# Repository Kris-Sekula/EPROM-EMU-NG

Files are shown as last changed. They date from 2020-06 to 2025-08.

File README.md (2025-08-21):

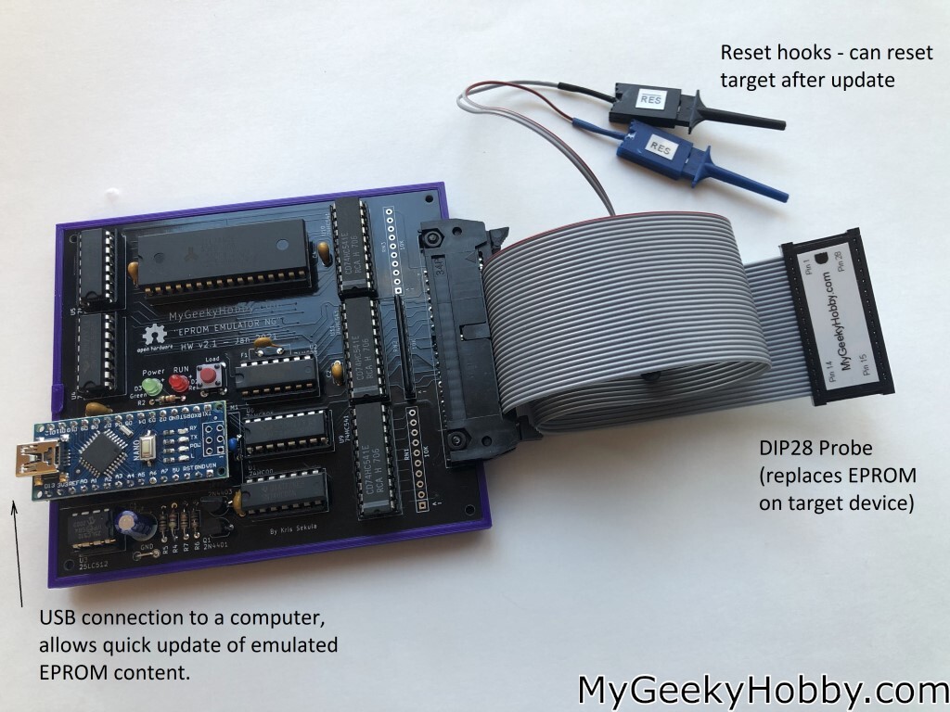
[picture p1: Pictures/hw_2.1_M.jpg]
EPROM EMULATOR NG

# EPROM-EMU-NG
EPROM Emulator Project with Arduino Nano, read more on [https://MyGeekyHobby.com](https://mygeekyhobby.com/2020/07/05/eprom-emulator/)

I have assembled devices and kits listed on [eBay](https://www.ebay.com/usr/avr4sale)

As people start building those, I encourage everyone to help creating updated firmware, software and collaborate here, report Issues if needed or contact me directly.

I get my PCBs from:

PCBWay (https://www.pcbway.com/project/shareproject/EPROM_Emulator_based_on_Arduino_.html)

If you found this helpful and you like the work I do, why not buy me a coffe, thanks ! :)



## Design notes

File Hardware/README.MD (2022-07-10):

###### Jul-9-2022

As of hardware version 1.9d and 2.2d support for a cheaper 28 pin probe has been added to the PCB, so depending on the type of probe you end up using, connector J1 has to be soldered in accordingly, see the picture below:

EPROM EMULATOR NG

###### Feb-6-2022

At this point there are two differnt hardware version of the emulator, one using 2x 32kb SRAMs and the other using a single 128kb SRAM (64k usable). Firmware and software is exaclty the same for both.

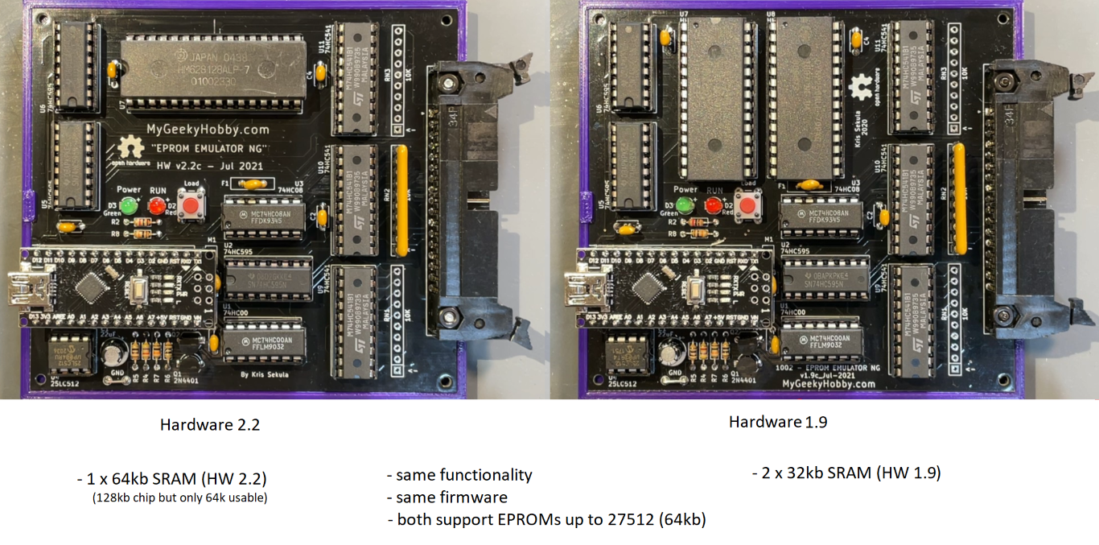
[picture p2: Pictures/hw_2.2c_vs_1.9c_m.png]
EPROM EMULATOR NG


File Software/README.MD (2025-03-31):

## Software (Python script) to control the EPROM emulator

### Currently recommended firmware and software:
* Firmware 2.0rc4 (EPROM_EMU_NG_FW_2.0rc4.ino - Arduino sketch in [Firmware](https://github.com/Kris-Sekula/EPROM-EMU-NG/tree/master/Firmware) folder)
* Software 2.0rc4 (EPROM_NG_v2.0rc4.py - Python script)

### If you want to try new features (increased speed of transfer, support for EEPROM), use the following:
* Firmware 2.0rc12 (EPROM_EMU_NG_FW_2.0rc12.ino - Arduino sketch in [Firmware](https://github.com/Kris-Sekula/EPROM-EMU-NG/tree/master/Firmware) folder)
* Software 2.0rc10 (EPROM_EMU_NG_2.0rc10.py - Python script)

## To successfully use the EPROM Emulator, you must do the following:
1. Install drivers
2. Install Python
3. Install required Python libraries
4. Run the script in command line mode (CLI) or in graphical interface mode (GUI)

### 1. Install Drivers
If you're using a genuine Arduino Nano module, install the Arduino IDE (this will install the drivers for all modules).
Most people use the much cheaper "clones", those in most cases, use the CH340 chip.
When plugged to a computer, they are supposed to "show up" as a "serial port device", but in many cases, driver installation is required. 

Sparkfun created a dedicated page that will guide you through the installation of CH340 drivers:

https://learn.sparkfun.com/tutorials/how-to-install-ch340-drivers/all

### 2. Install Python
The base way to install Python is to download the installation file from https://www.python.org/downloads/

> [!TIP]
> The installer has an option called "Add python to PATH", make sure you select it, this makes executing scripts much easier.

### 3. Install required libraries
There are two essential libraries that you must install:

* **pyserial** - to enable serial communication in Python
* **FreeSimpleGUI** - to allow a Python script to display a graphical user interface (GUI)

In Python, we install the libraries by calling a "package manager" called PIP. In your command prompt, you need to run:

```python -m pip install pyserial```

and 

```python -m pip install FreeSimpleGUI```

### 4.1 Run the script - CLI mode
You can run the script in a command-line mode by supplying the required parameters. Here is an example of the minimum required parameters to run the script:

```python.exe EPROM_NG_v2.0rc4.py -mem 27512 blink.bin COM13```

Parameters are explained:

"-mem 27512" -> Type of emulated memory

"blink.bin" -> file getting transferred (we support binary and intel hex files)

"COM13" -> serial port the emulator is plugged into

Here is a full output of the "upload session":
```
C:\PyDev>python.exe EPROM_NG_v2.0rc4.py -mem 27512 blink.bin COM13

Running EPROM EMU NG python script version 2.0rc4

File used: blink.bin

Done processing bin

Memory map disabled

Using serial port COM13, emulating: 27512 EPROM

-- attempting to get sync --

-> HW: v2.2h @ 115200, FW: 2.0rc4, SPI: 0, Auto: 0, Last EPROM: 27512, mygeekyhobby.com 2020 :)

-- processing file --

0x7E00 ->in

Time taken to transfer: 4.79s

-- Setting EPROM Type --
ACK

-- Finished --
-> Bus set to 27512 EPROM Memory
```

## 4.2 Run the script - GUI mode
If you want to start the script in graphical mode, **simply start it without any parameters**:

```python.exe EPROM_NG_v2.0rc4.py```

The script will open a "window":

![GUIMODE](https://github.com/Kris-Sekula/EPROM-EMU-NG/blob/master/Pictures/running_GUI_mode.JPG)

> [!NOTE]
> Depending on how Python is installed on your system, you may be able to simply "double-click" on the script to start it in GUI mode.

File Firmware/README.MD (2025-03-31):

## Firmware for Arduino Nano

### Currently recommended firmware and software:
* Firmware 2.0rc4 (EPROM_EMU_NG_FW_2.0rc4.ino)
* Software 2.0rc3 (EPROM_NG_v2.0rc4.py in [Software](https://github.com/Kris-Sekula/EPROM-EMU-NG/tree/master/Software) folder)

### If you want to try new features (increased speed of transfer, support for EEPROM) use the following:
* Firmware 2.0rc12 (EPROM_EMU_NG_FW_2.0rc12.ino - Arduino sketch)
* Software 2.0rc9 (EPROM_EMU_NG_2.0rc10.py - Python script in [Software](https://github.com/Kris-Sekula/EPROM-EMU-NG/tree/master/Software) folder)

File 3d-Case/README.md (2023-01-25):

The original files are for a "plastic base" rather than a proper case, but recently Todd Decker shared his design for a real case, check it out at [printables.com](https://www.printables.com/model/379508-eprom-emulator-case). He also shared his design via his [GitHub](https://github.com/ptdecker/openscad/tree/master/ROM%20Emulator) page.

Calling it a "case" is a bit of overstatement, it's simply a plastic "base plate" that you can install your emulator into. Adding some rubber feet to it (I use 3M sticky ones) will keep both your emulator and your table "protected". I printed mine with PLA.

There is a Probe_label file in Brother ptouch format and png format, so you print it and attach to the DIP 28 emulator probe.

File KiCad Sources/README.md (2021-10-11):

KiCad project files.

Version 2.2: Reshuffled component designations for pcb v1.9c and 2.2c to keep them in sync - help to keep the BoM alligned... only delta is the SRAM

Version 2.1: Moved from using 2x 32k SRAM to single 128k SRAM (64k usable). Firware and software is the same for both.

Version 1.9: Added pull-up resistors to /WE and EN_RST, helps prevent SRAM corruption during Arduino reset (needed only when doing partial uploads)

Version 1.8b: Fixed the footprint for Q1-2N4401 and Q2-2N4403, see Errata document for more details.

Version 1.8: I re-shuffled resistor networks, added RN3 to offer optional pull-up resistors for address line A0-A7, RN2 should be populated, RN1 and RN3 are optional. Added Q3 for my experiments, but there is no need to populate that transistor.

Version 1.7: Minor fix for a desing flaw as described in the ERRATA document. I also enlarged the holes for J1 as depeding on vendor of the connector in some cases the fit was very tight.

Version 1.6: Added some component description on silkscreen, no changes to tracks routing.

Version 1.4: I re-routed the power and improved the PCB design.

Version 1.0: After I built the first 5 prototypes, I discovered an issue with the PCB layout, one of the shift registers (U11) was getting onto a CMOS latch-up state, even though I had a few bypass caps around the PCB, I was still occasionally getting the issues. I fixed the prototypes by "bodging" a few connections at the bottom of the pcb.

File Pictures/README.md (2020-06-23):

A few pictures of the device, plus some "in action".

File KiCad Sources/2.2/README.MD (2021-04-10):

Version 2.2: no major changes, cleaned up the schematic a bit, re-shuffled the part designators so that ICs that are close to each other have consecutive numbers etc.

Firmware and software stays the same.

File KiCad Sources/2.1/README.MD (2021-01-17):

Changed from using 2x32 SRAM to single 128k SRAM (only 64k used). 

Firmware and software is the same for both desings, but the single SRAM has few pins less to solder :)

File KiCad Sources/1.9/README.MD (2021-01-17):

In this version of the design, I'm adding pull-up resistors to the /WE and the EN_RST lines. 
It helps to handle the state of the emulator when Arduino resets, this prevents the memory content corruption when we re-connect to the Arduino,
remember Arduino Nano has the feature where it resets as soon as you open the serial port. 
All of this is useful for the new software that I'm working on - it allows you to cache the data and only upload new/changed sectors.

Consider this PCB version verified as I already had boards made by PCBWay and they work fine.

This is the last version for the design with 2x 32k SRAMs ... I'm now moving to a new design that is using a single SRAM chip (see the 2.1 folder).

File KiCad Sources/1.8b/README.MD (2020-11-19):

1.8b is exactly as 1.8 but uses different footprint for Q1 and Q2 (see the Errata document for details)

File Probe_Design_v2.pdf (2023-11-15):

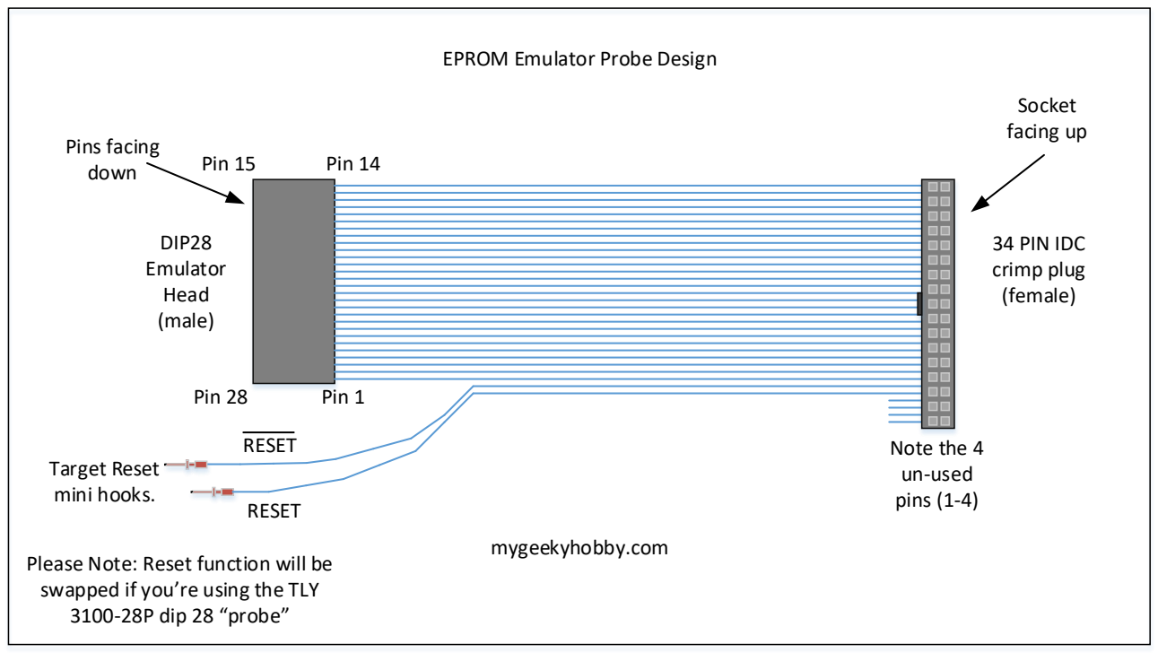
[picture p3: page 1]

34 PIN IDC
crimp plug
(female)

DIP28
Emulator
Head
(male)

Note the 4
un-used
pins (1-4)

Pin 14

Pin 28

Pin 15

Pin 1

mygeekyhobby.com

EPROM Emulator Probe Design

Pins facing
down

Socket
facing up

RESET

RESET
Target Reset
mini hooks.

Please Note: Reset function will be swapped if you’re using the TLY 3100-28P dip 28 “probe”

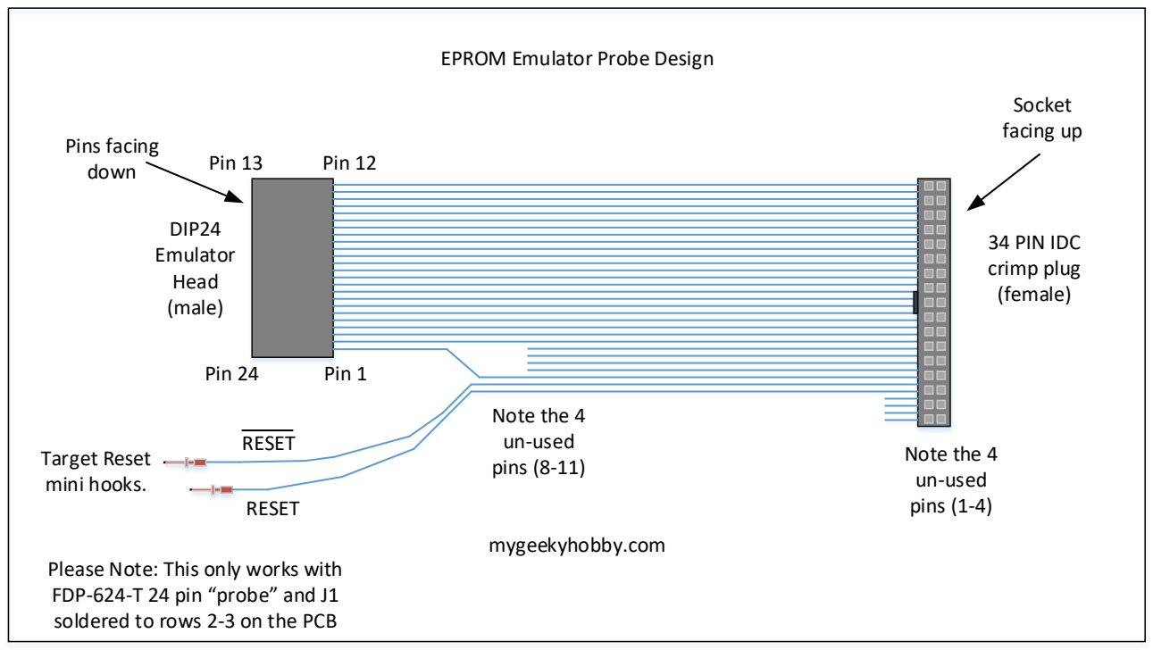
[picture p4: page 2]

34 PIN IDC
crimp plug
(female)

DIP24
Emulator
Head
(male)

Target Reset
mini hooks.

Note the 4
un-used
pins (1-4)

Pin 12

Pin 24

Pin 13

Pin 1

mygeekyhobby.com

EPROM Emulator Probe Design

Pins facing
down

Socket
facing up

Note the 4
un-used
pins (8-11)

RESET

RESET

Please Note: This only works with FDP-624-T 24 pin “probe” and J1 soldered to rows 2-3 on the PCB

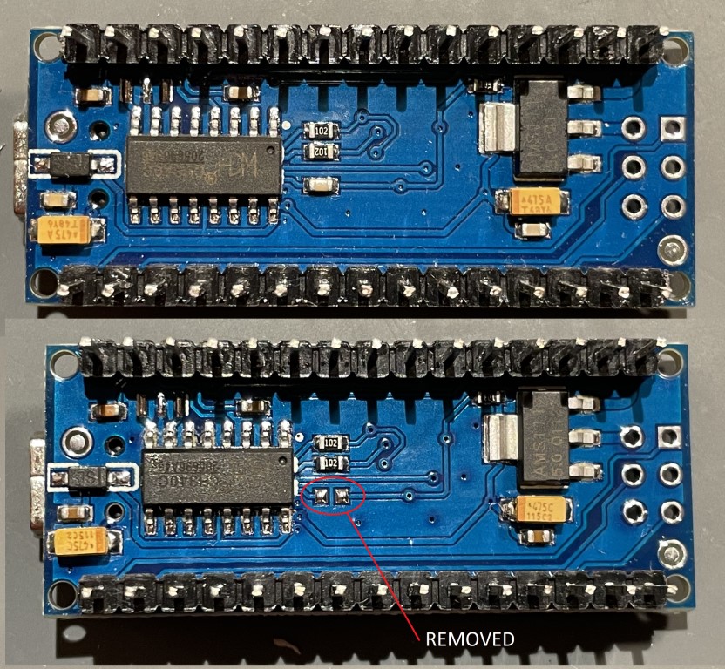
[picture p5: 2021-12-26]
Pictures/Nano_328PB.jpg

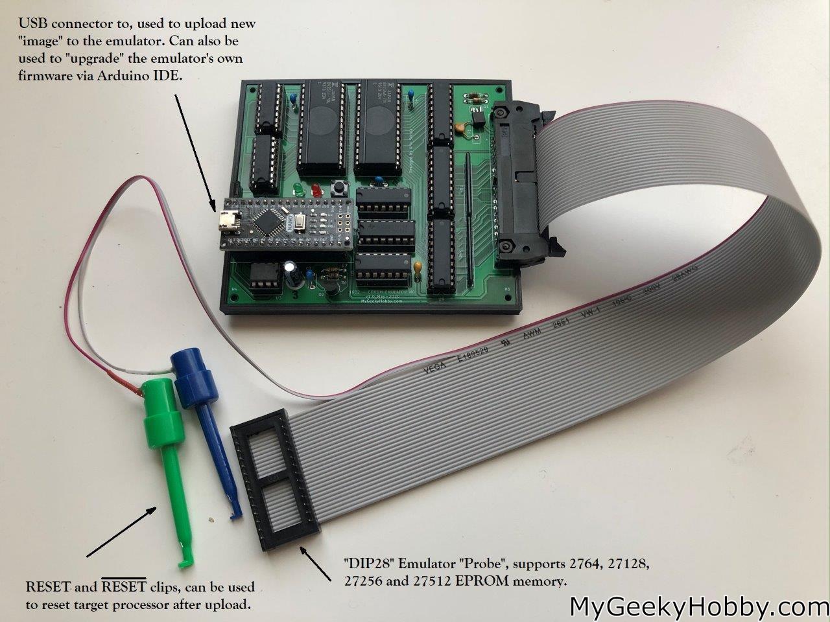
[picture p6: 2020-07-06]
Pictures/EMU_1.0b_ready_descr.jpg

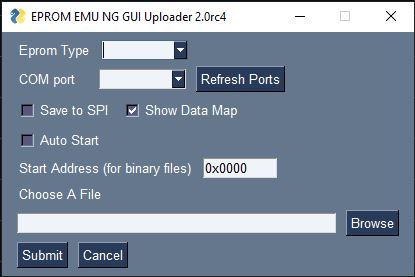
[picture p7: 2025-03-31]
Pictures/running_GUI_mode.JPG

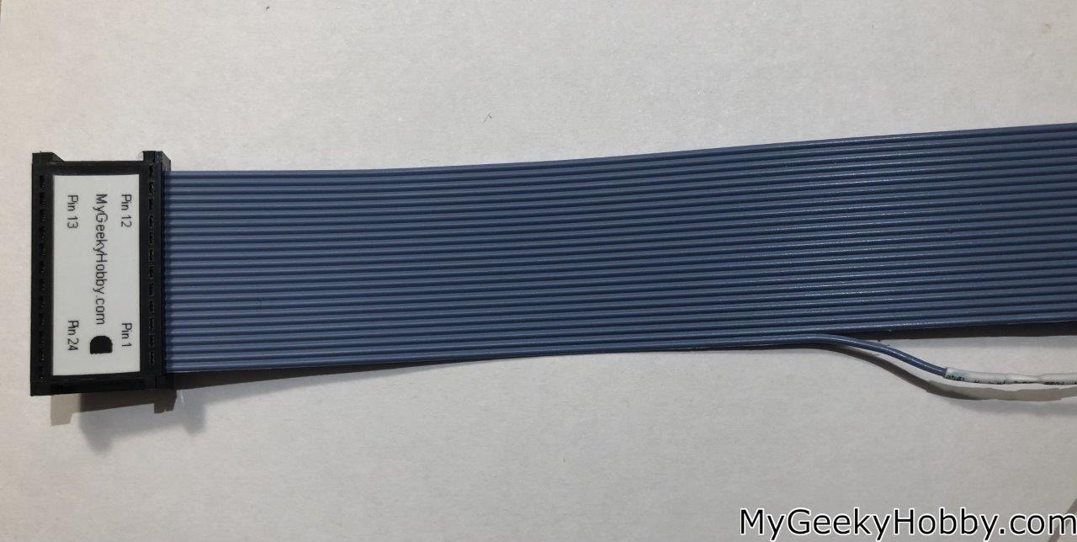
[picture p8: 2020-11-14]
Pictures/Emulator Probe/DIP24_4.jpg

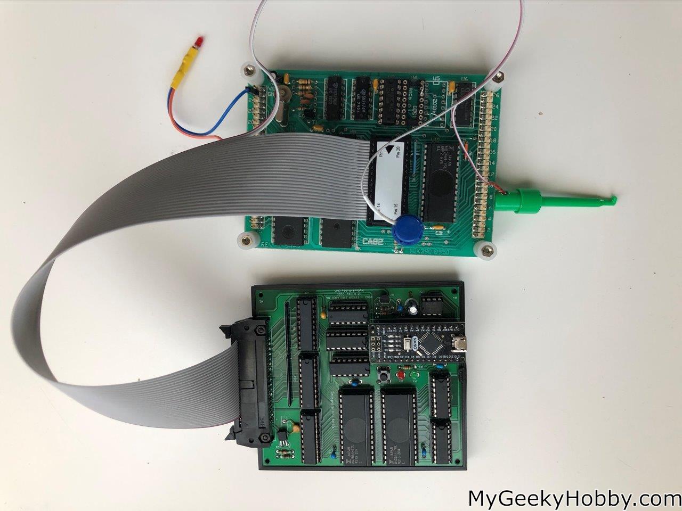
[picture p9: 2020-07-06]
Pictures/EMU_1.0b_w_Z80.jpg

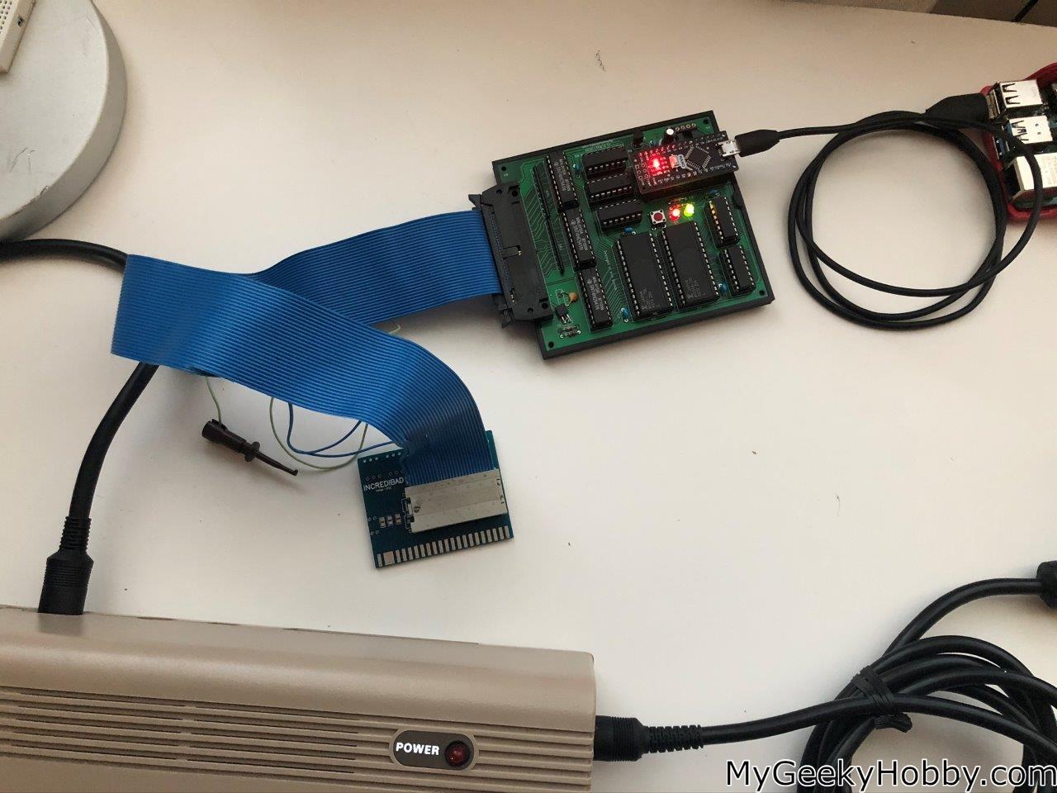
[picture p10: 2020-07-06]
Pictures/EMU_1.0b_w_c64_cart.jpg

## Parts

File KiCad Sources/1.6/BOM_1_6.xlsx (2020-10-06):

Ref | Value | Description | Digikey part no
C2, C3, C4, C5, C6 | 100nF | Unpolarized capacitor | ‎445-173588-1-ND‎
C1 | 10uF | Polarized capacitor, small symbol | P19513CT-ND
C7 | 22nF | Unpolarized capacitor | 445-173593-1-ND
RN1, RN2 | 10K | 9 resistor network, star topology, bussed resistors, small symbol | 4610X-1-103LF-ND
R1, R2 | 330R | Resistor 0.125W | CF18JT330RCT-ND‎
R3, R7 | 10k | Resistor 0.125W | CF18JT10K0CT-ND
R4 | 4.7k | Resistor 0.125W | CF18JT4K70CT-ND
R5, R6 | 10R | Resistor 0.125W | ‎CF18JT10R0CT-ND‎
D3 | LED | LED RED | ‎732-5005-ND‎
D2 | LED | LED GREEN | 732-5008-ND‎
D5 | BAT48 | DIODE SCHOTTKY 40V 350MA DO35 | ‎497-2512-1-ND‎
Q1 | BC547 | NPN transistor (BC547 or 2N4401) | 2N4401-APCT-ND
Q2 | BC557 | PNP transistor (BC557 or 2N4403) | 2N4403-APCT-ND‎
U3 | 25LC512 | Microchip SPI Serial EEPROM, DIP-8/SOIC-8/TSSOP-8 | 25LC512-I/P-ND
U1 | 74HC00 | quad 2-input NAND gate | ‎296-1563-5-ND‎
U2 | 74HC08 | Quad And2 | 296-1570-5-ND‎
U9, U10, U11 | 74HC541 | 8-bit Buffer/Line Driver 3-state outputs | ‎296-1594-5-ND‎
U4, U5, U6 | 74HC595 | 8-bit serial in/out Shift Register 3-State Outputs | 296-36142-5-ND
U7, U8 | HM62256B | 32,768-word × 8-bit High Speed CMOS Static RAM | 1450-1033-ND
M1 | Arduino Nano v3.0 | Arduino Nano module | 1050-1001-ND
J1 | IDC34 | Connector_IDC:IDC-Header_2x17_P2.54mm_Horizontal_Lock | 2057-MHR-34-HUAS-ND
F1 | Polyfuse_50mA | PTC RESET FUSE 60V 50MA RADIAL | MF-R005-0-ND‎
SW1 | SW_Push | Push Button Generic | 450-1804-ND
Sockets
U3 | DIP8 socket |  | ‎AE9986-ND‎
U1,U2 | DIP14 socket |  | ‎AE9989-ND‎
U4, U5, U6 | DIP16 socket |  | ‎AE9992-ND‎
U9, U10, U11 | DIP20 socket |  | ‎AE9998-ND‎
U7, U8 | DIP28 socket |  | ‎AE10004-ND‎
RN1, RN2 | SIP10 socket | use SIP20 and split in half, gives flexibility to change pull-ups later | 952-2538-ND
28 PIN Probe
DIP28 |  | DIP28 Male to flat cable | ‎2057-FDP-628-T-ND‎
IDC34 |  | SOCKET FLAT CABLE IDC 34P 2.54MM | ‎2057-FCS-34-SG-ND‎
Grabber |  | Red mini hook grabber | ‎461-1014-ND‎
Grabber |  | Black mini hook grabber | 461-1013-ND‎

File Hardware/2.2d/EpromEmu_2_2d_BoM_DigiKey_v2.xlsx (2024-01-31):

Index | Quantity | Part Number | Manufacturer Part Number | Description | Customer Reference
1 | 2 | CF18JT10R0CT-ND | CF18JT10R0 | RES 10 OHM 5% 1/8W AXIAL | R5, R6
2 | 3 | CF18JT10K0CT-ND | CF18JT10K0 | RES 10K OHM 5% 1/8W AXIAL | R3, R7, R8
3 | 1 | CF18JT4K70CT-ND | CF18JT4K70 | RES 4.7K OHM 5% 1/8W AXIAL | R4
4 | 2 | CF18JT1K00CT-ND | CF18JT1K00 | RES 1K OHM 5% 1/8W AXIAL | R1, R2
5 | 2 | 4610X-1-473LF-ND | 4610X-101-473LF | RES ARRAY 9 RES 47K OHM 10SIP | RN2, RN3
6 | 1 | 399-6649-1-ND | ES5226M050AE1EA | CAP ALUM 22UF 20% 50V RADIAL | C1
7 | 5 | 445-173588-1-ND | FG28X7R1H104KNT06 | CAP CER 0.1UF 50V X7R RADIAL | C2, C3, C4, C5, C6
8 | 1 | 445-173593-1-ND | FG28X7R1H223KNT06 | CAP CER 0.022UF 50V X7R RADIAL | C7
9 | 1 | RXEF025HF-ND | RXEF025 | PTC RESET FUSE 72V 250MA RADIAL | F1
10 | 1 | 497-2512-1-ND | BAT48 | DIODE SCHOTTKY 40V 350MA DO35 | D1
11 | 1 | 732-5005-ND | 151031SS04000 | LED RED DIFFUSED 3MM ROUND T/H | D2
12 | 1 | 732-5007-ND | 151031VS04000 | LED GREEN DIFFUSED 3MM ROUND T/H | D3
13 | 1 | 2N4403TFCT-ND | 2N4403 | TRANS PNP 40V 0.2A TO-92 | Q2
14 | 1 | 2N4401TFCT-ND | 2N4401 | TRANS NPN 40V 0.2A TO92 | Q1
15 | 1 | 296-12769-5-ND | CD74HC00E | IC GATE NAND 4CH 2-INP 14DIP | U1
16 | 1 | 296-12773-5-ND | CD74HC08E | IC GATE AND 4CH 2-INP 14DIP | U3
17 | 3 | 296-12813-5-ND | SN74HC541E | IC BUFFER NON-INVERT 6V 20DIP | U9, U10, U11
18 | 3 | 296-1600-5-ND | SN74HC595N | IC SHIFT REGISTER 8BIT 16-DIP | U2, U5, U6
19 | 1 | CAT25512VI-GT3OSCT-ND | CAT25512VI-GT3 | IC EEPROM 512KBIT SPI 8SOIC | U4
20 | 1 | 1738-1002-ND | FIT0290 | BOARD - SOP8 - DIP adapter | U4
21 | 1 | 1450-1017-ND | AS6C1008-55PCN | IC SRAM 1MBIT PARALLEL 32DIP | U7
22 | 1 | 1050-1001-ND | A000005 | ARDUINO NANO ATMEGA328 EVAL BRD | M1
23 | 1 | 2057-MHR-34-HUAS-ND | MHR-34-HUAS | CONN HEADER R/A 34POS 2.54MM | J1
24 | 1 | 450-1804-ND | 1825910-7 | SWITCH TACTILE SPST-NO 0.05A 24V | SW1
25 | 1 | AE9986-ND | A 08-LC-TT | CONN IC DIP SOCKET 8POS TIN | U4
26 | 3 | AE9992-ND | A 16-LC-TT | CONN IC DIP SOCKET 16POS TIN | U2, U5, U6
27 | 2 | AE9989-ND | A 14-LC-TT | CONN IC DIP SOCKET 14POS TIN | U1, U3
28 | 3 | AE9998-ND | A 20-LC-TT | CONN IC DIP SOCKET 20POS TIN | U9, U10, U11
29 | 1 | 2057-ICS-632-T-ND | ICS-632-T | IC SOCKET, DIP, 32P 2.54MM PITCH | U7
30 | 2 | S7013-ND | PPTC151LFBN-RC | CONN HDR 15POS 0.1 TIN PCB | M1/M1
31 | 1 | A786AR-ND | 10-0518-10 | CONN SOCKET SIP 10POS GOLD | RN2, RN3
32 | 1 | 2057-FCS-34-SG-ND | FCS-34-SG | SOCKET FLAT CABLE IDC 34P 2.54MM | Emulator Probe
33 | 1 | 3M157809-10-ND | 3365/34 300 | CBL RIBN 34COND 0.050 GRAY 10' | Emulator Probe
34 | 1 | 2057-FDP-628-T-ND | FDP-628-T | PLUG FLAT CABLE IDC 28P 2.54MM P | Emulator Probe
35 | 1 | 461-1013-ND | X100WBLK | MINI-HOOK BLACK SOLDER 0.093" | Emulator Probe
36 | 1 | 461-1019-ND | XRRED | MINI-HOOK RED SOLDER 0.093" | Emulator Probe

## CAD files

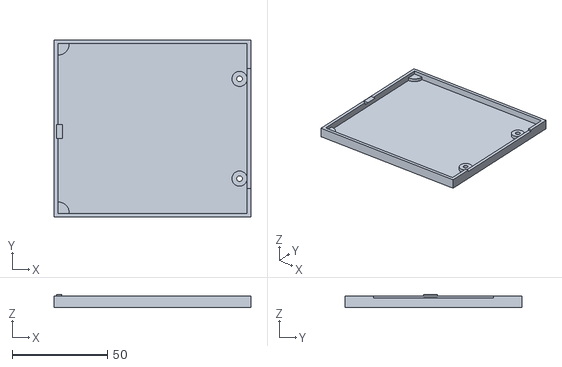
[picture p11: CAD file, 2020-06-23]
3d-Case/EPROM EMU NG base plate_v2.stl
103.2 x 93.0 x 7.00

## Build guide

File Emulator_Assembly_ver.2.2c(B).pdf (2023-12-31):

EPROM EMU NG – Assembly Instructions.

For PCB version 2.2c

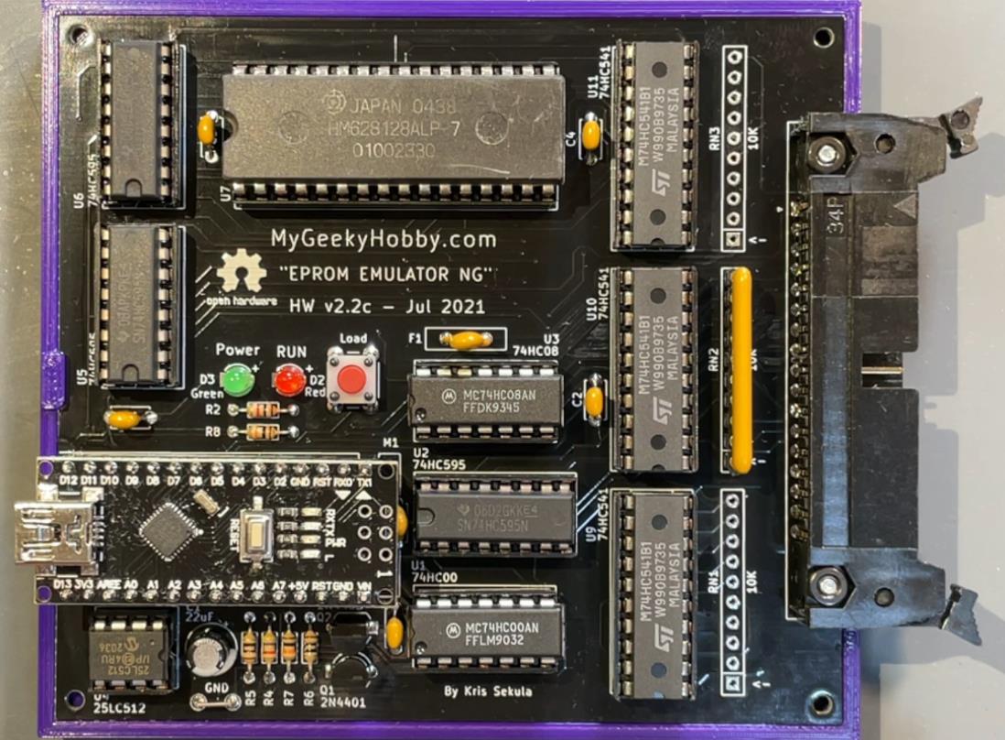
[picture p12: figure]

MyGeekyHobby.com – Dec 2023

Document version: 2.2c(B)

EPROM EMU NG – Assembly Instructions 2.2c(B). MyGeekyHobby.com– Dec 2023

© MyGeekyHobby.com 2021

Document history:

“Assembly Instructions 2.2c(B)” – added information about RN3.

Thank you for purchasing the “EPROM EMU NG” DIY Kit, following is a brief assembly instruction.

This document is being updated regularly, check my GitHub page for updates:

https://github.com/Kris-Sekula/EPROM-EMU-NG

Before you begin, familiarize yourself with locations of components on the blank PCB

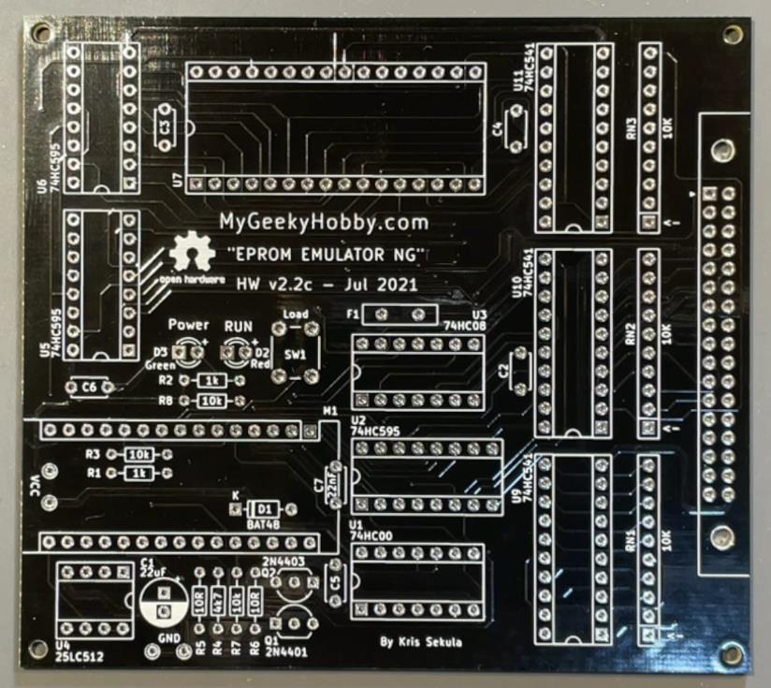
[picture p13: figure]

Solder components starting with the shortest.

1. Populate resistors R1, R2 – 1k, resistors R3, R7, R8 – 10k, resistor R4 – 4.7k, resistors R5,R6 – 10R and diode D1 (BAT48):

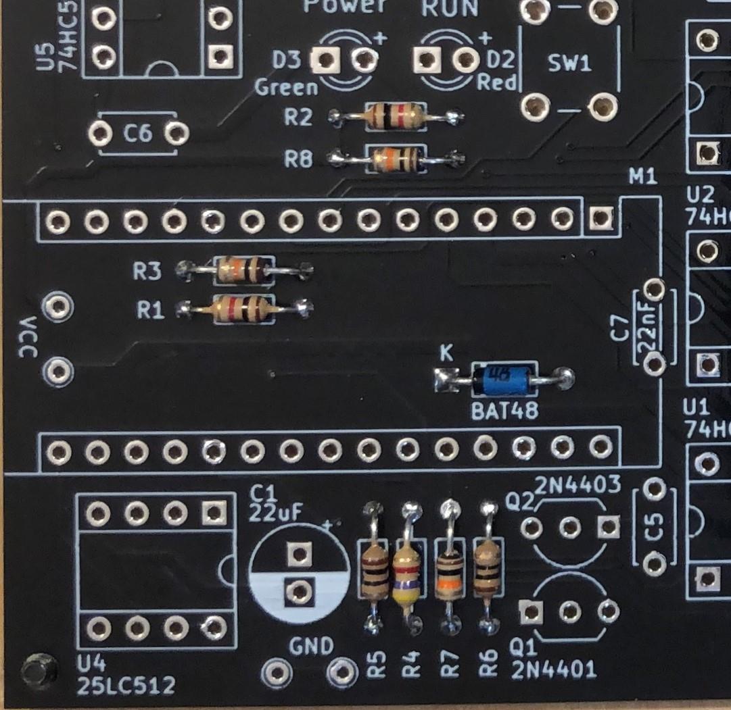
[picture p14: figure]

Note: Pay attention to diode D1 polarity, the black band should point towards the “K”.

2. Populate the precision socket for resistor network RN2 and RN3

Useful tip:

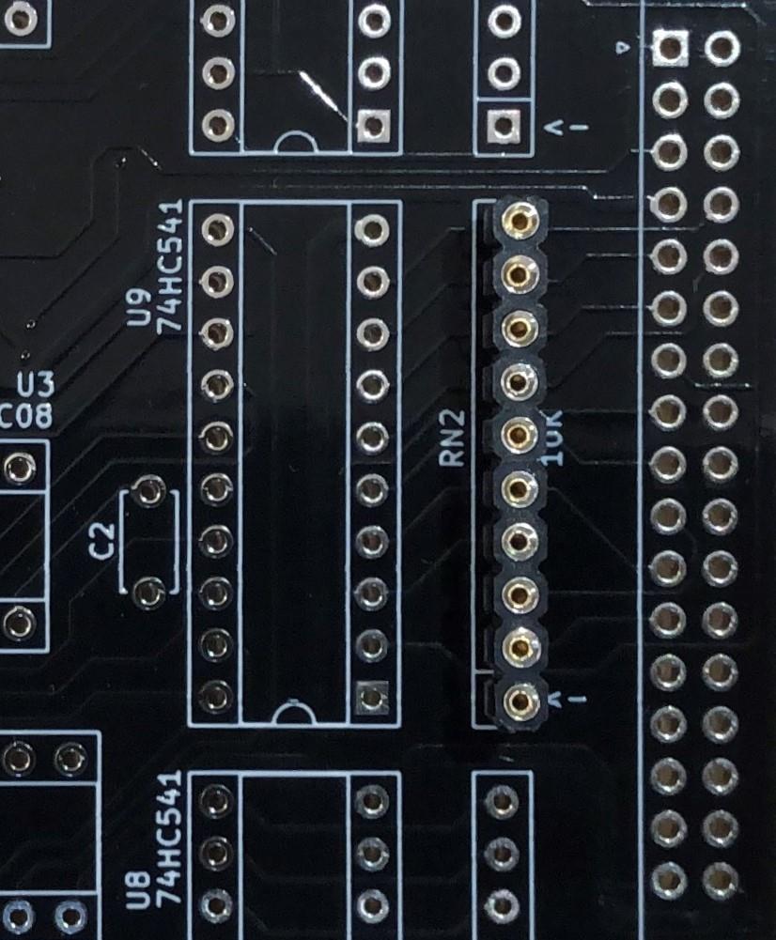
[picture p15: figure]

Solder one of the middle pins first, this will give you opportunity to check if the socket is straight, and adjust if needed before you solder all other pins.

NOTE: this instruction was updated in December 2023, please populate both RN2 and RN3 – the pictures are not reflecting the fact, but both of those resistor networks are required – they guarantee that all input lines (address bus) are not left “floating” if not used.

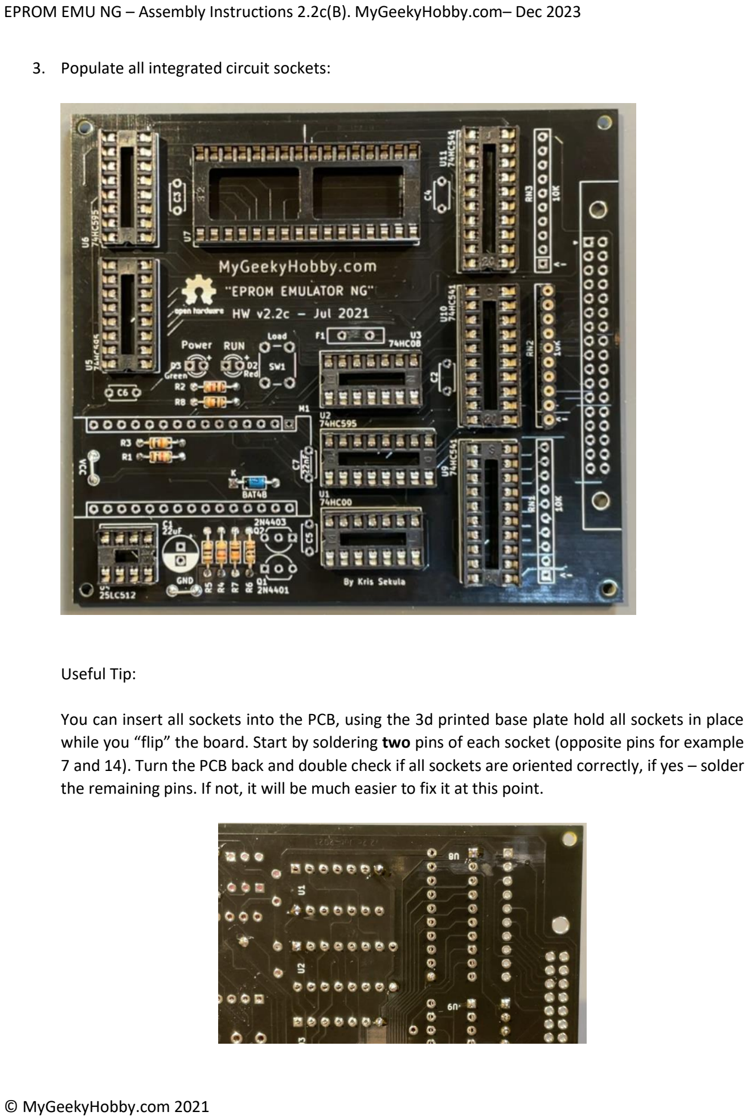
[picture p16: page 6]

3. Populate all integrated circuit sockets:

Useful Tip:

You can insert all sockets into the PCB, using the 3d printed base plate hold all sockets in place while you “flip” the board. Start by soldering two pins of each socket (opposite pins for example 7 and 14). Turn the PCB back and double check if all sockets are oriented correctly, if yes – solder the remaining pins. If not, it will be much easier to fix it at this point.

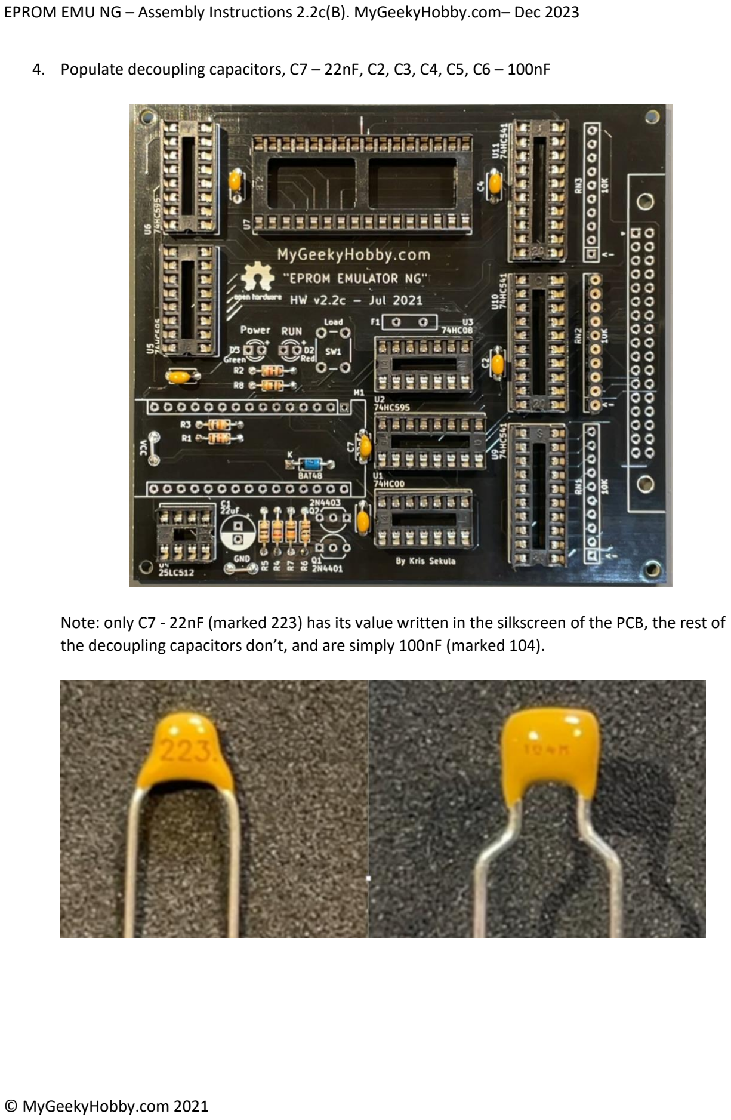
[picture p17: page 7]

4. Populate decoupling capacitors, C7 – 22nF, C2, C3, C4, C5, C6 – 100nF

Note: only C7 - 22nF (marked 223) has its value written in the silkscreen of the PCB, the rest of the decoupling capacitors don’t, and are simply 100nF (marked 104).

5. Populate the LEDs and the push button:

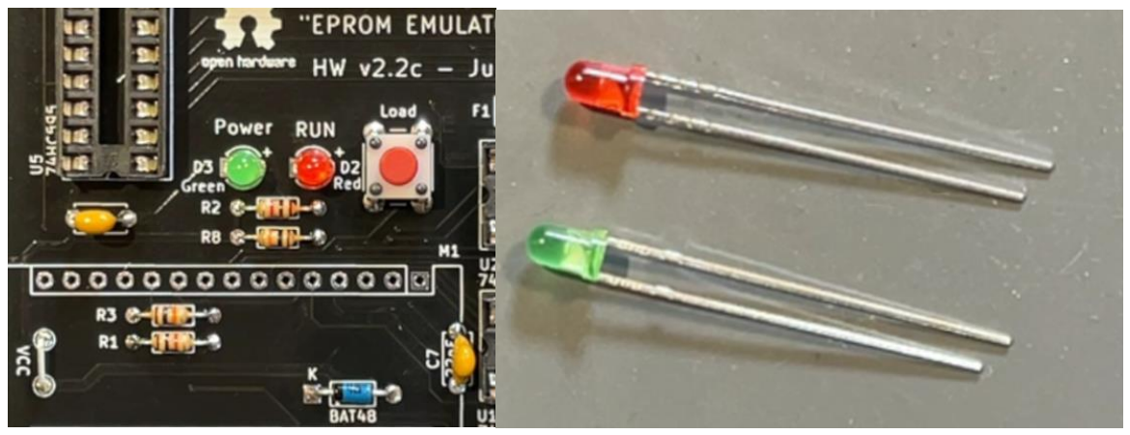
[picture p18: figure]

Useful Tip:
The longer lead of the LED should go to the hole marked with “+”.

Keep the cut-offs from the LED as you will need them in the next step

Note:
The current firmware of the emulator uses the push button in the following way:
a) Short press – loads the content of the SPI EEPROM into the SRAM
b) Long press – resets the target device (if the reset hooks are attached)

6. Use the LED cut-offs to populate the “GND” and “VCC” test points:

Useful Tip:

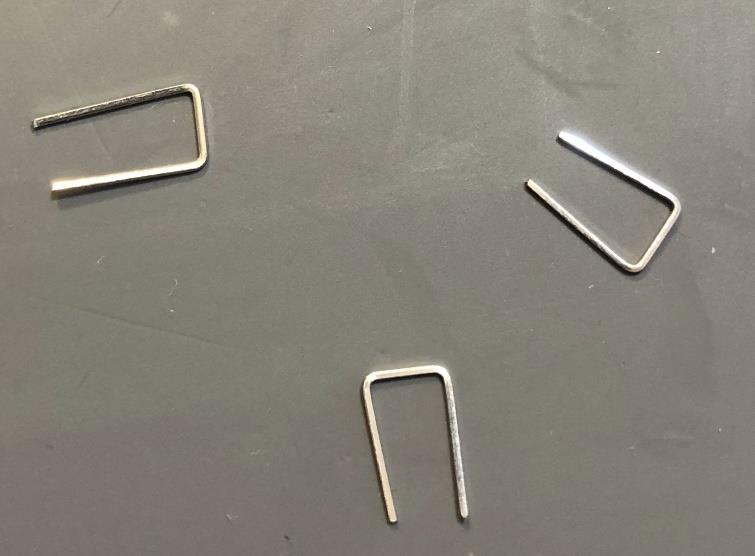
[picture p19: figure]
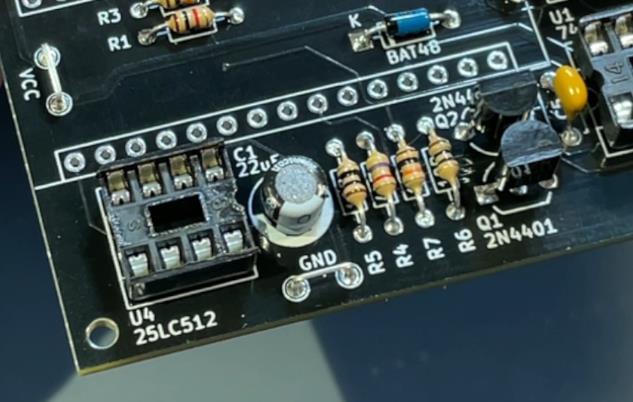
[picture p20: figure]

Those test points are “handy” place to attach ground from a logic probe or multimeter during firmware development.

7. Populate transistors Q1 – 2N4401 and Q2 – 2N4403:

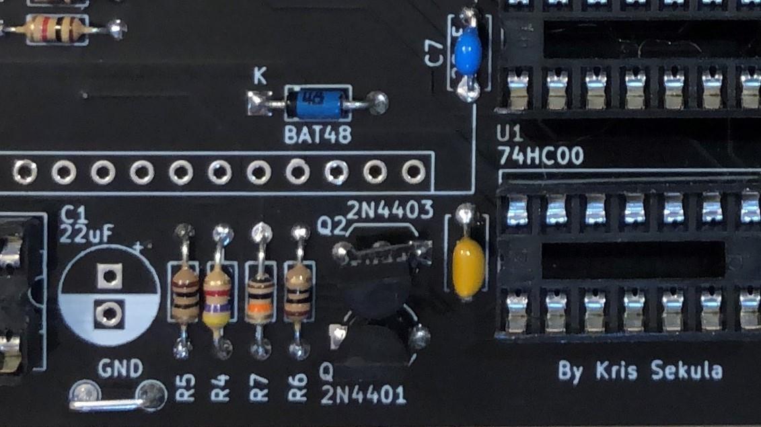
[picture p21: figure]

Useful tip:
Solder just the middle pin of the transistors, check if the transistor “stands” straight and adjust if needed before you solder the other two pins.
8. Populate C1 – 22uF/16V

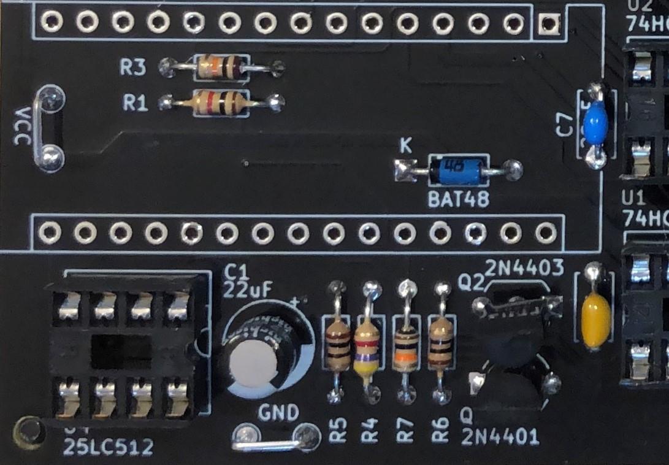
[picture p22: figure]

Note: Pay attention to capacitor polarity, white band mark negative lead!

9. Populate the Arduino Nano sockets M1a/M1b:

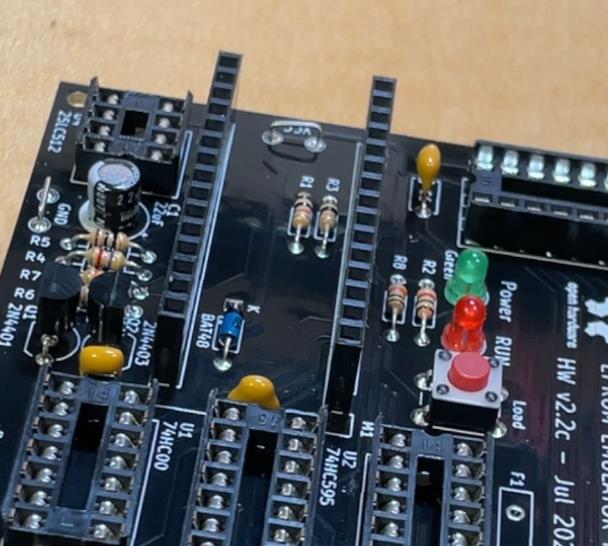
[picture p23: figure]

Useful tip:

If you insert the sockets into the PCB and lay it upside down on a flat surface, the socket will line up with the surface and stay straight… otherwise you can also use the trick of soldering a single pin first, and check if the socket is straight, correct if needed before soldering all other pins.

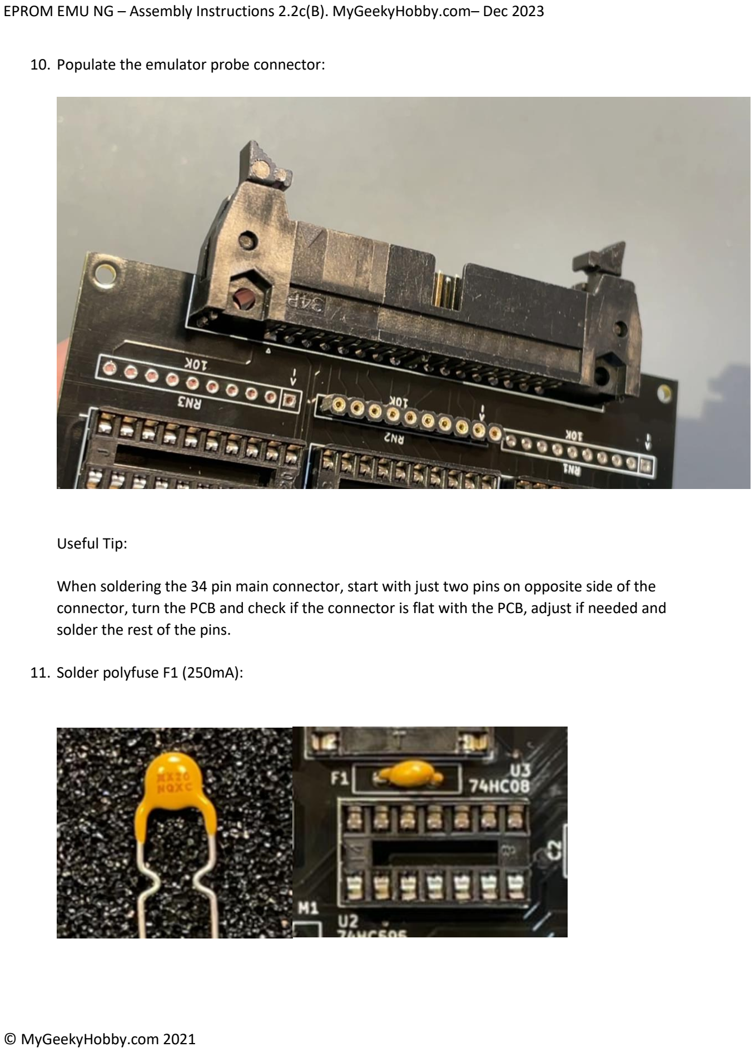
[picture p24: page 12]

10. Populate the emulator probe connector:

Useful Tip:

When soldering the 34 pin main connector, start with just two pins on opposite side of the connector, turn the PCB and check if the connector is flat with the PCB, adjust if needed and solder the rest of the pins.

11. Solder polyfuse F1 (250mA):

12. Solder the Nano pins, you can fist insert the pins into sockets in the PCB before soldering the Arduino module:

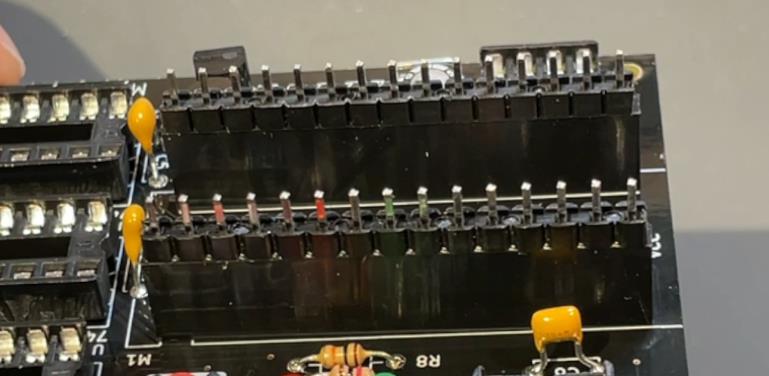
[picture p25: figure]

Be careful not to misalign the module, make sure all pins are in correct position before you start soldering:

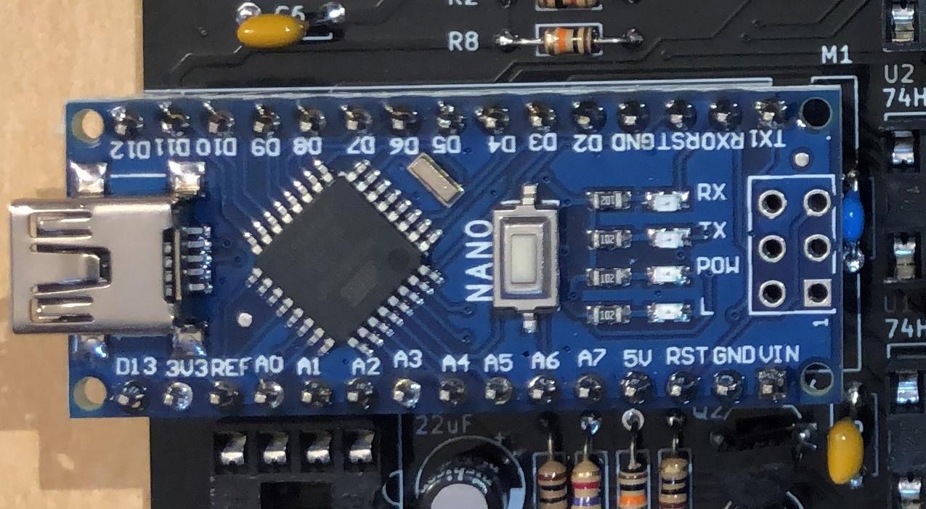
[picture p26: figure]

At this point all soldering is finished, you should clean the PCB and the Arduino module with 99% Isopropyl alcohol or similar PCB cleaner.

13. Prepare the base plate by adding the rubber feet:

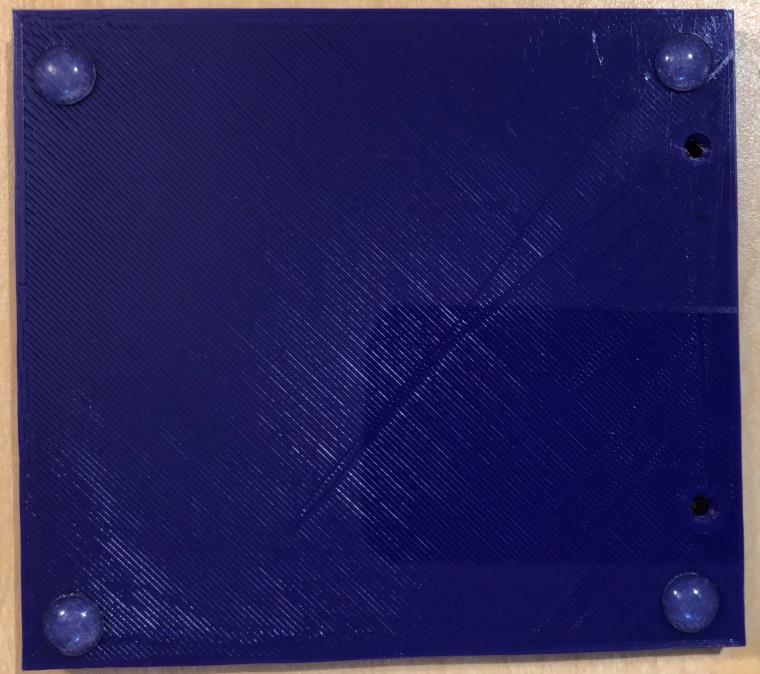
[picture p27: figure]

14. Secure the PCB into the base plate using two sets of screws and nuts, the PCB is now ready to populate the components:

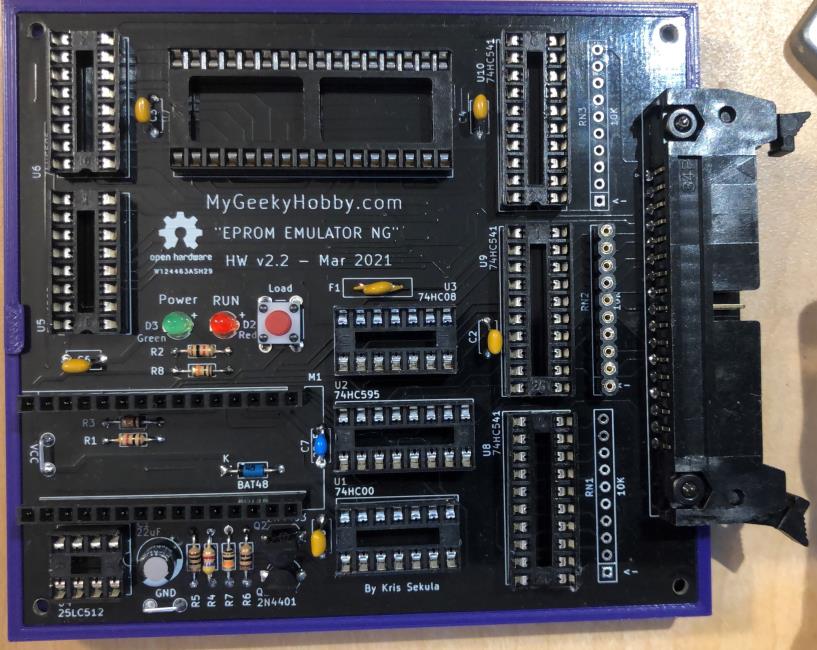
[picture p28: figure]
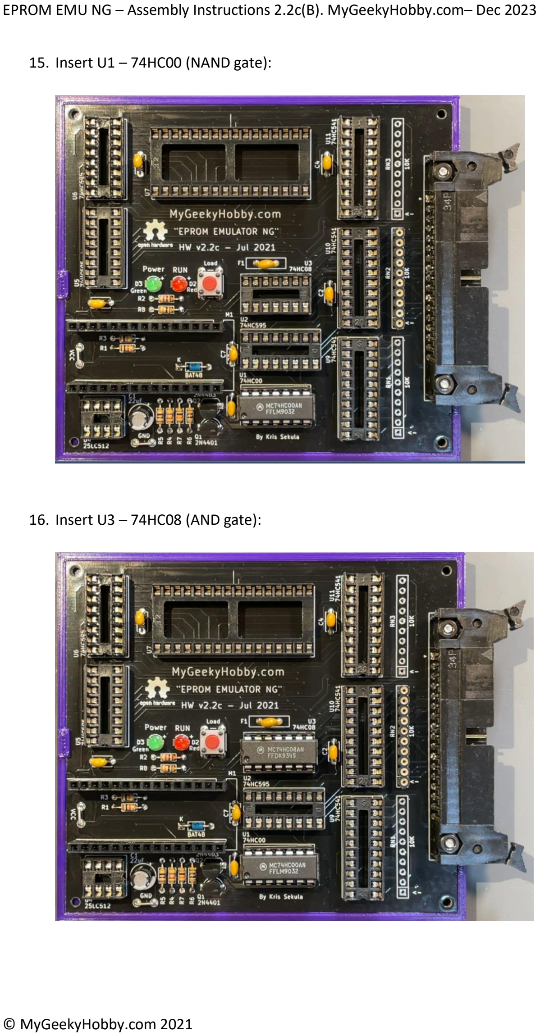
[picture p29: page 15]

15. Insert U1 – 74HC00 (NAND gate):
16. Insert U3 – 74HC08 (AND gate):

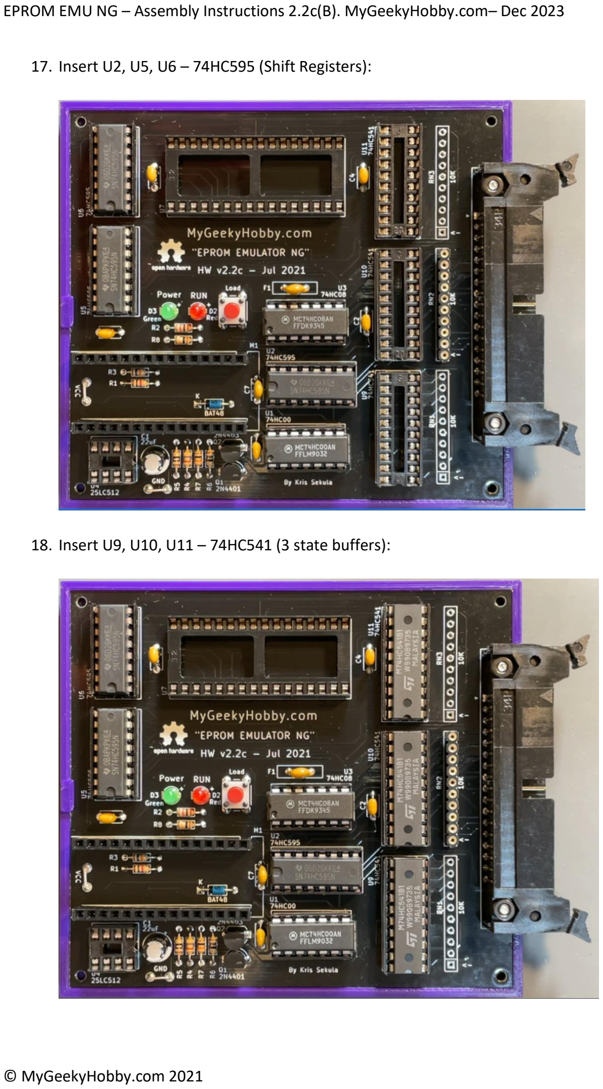
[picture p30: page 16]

17. Insert U2, U5, U6 – 74HC595 (Shift Registers):
18. Insert U9, U10, U11 – 74HC541 (3 state buffers):

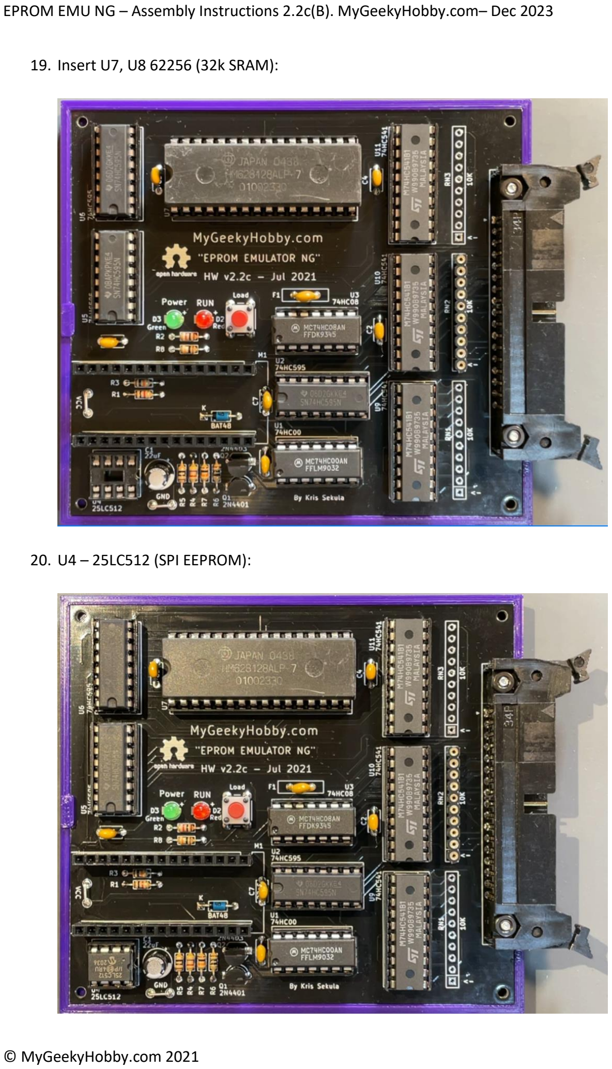
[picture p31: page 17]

19. Insert U7, U8 62256 (32k SRAM):
20. U4 – 25LC512 (SPI EEPROM):

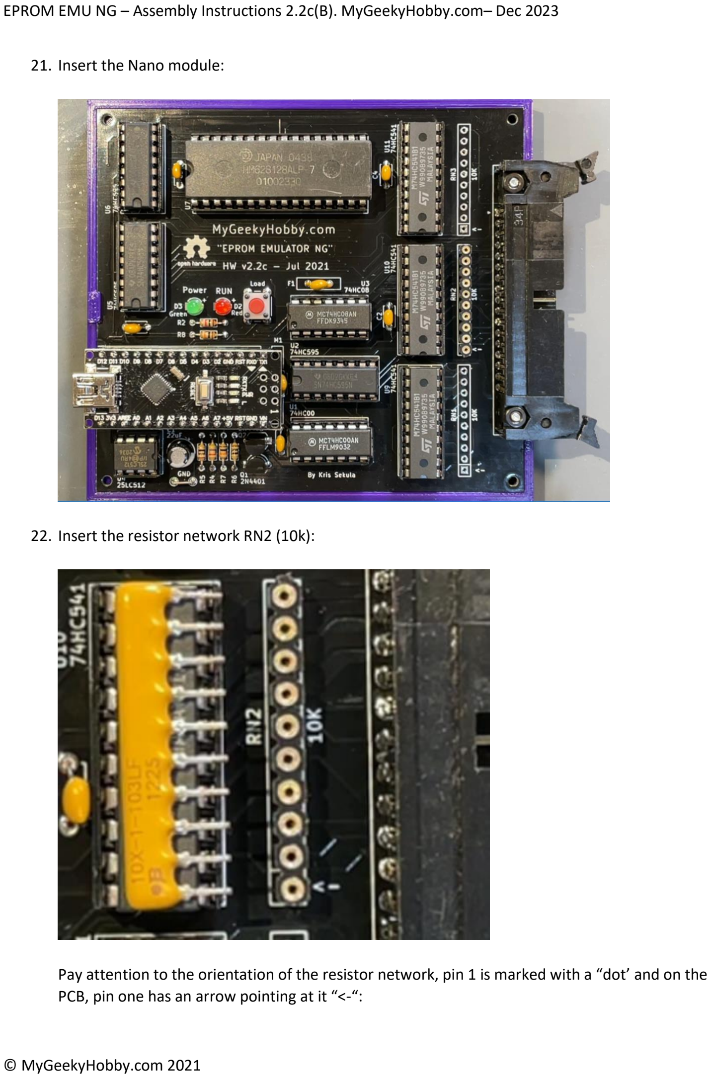
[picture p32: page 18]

21. Insert the Nano module:
22. Insert the resistor network RN2 (10k):

Pay attention to the orientation of the resistor network, pin 1 is marked with a “dot’ and on the PCB, pin one has an arrow pointing at it “<-“:

At this point your “EPROM EMULATOR NG” is assembled, you should program the Arduino Nano with the recommended version of firmware (Arduino sketch) and use it with compatible version of software (python script).

You will also need to build the Emulator Cable, detailed video instructions are here:

https://youtu.be/pb_EF_JVYxc?t=812

Legal Notice:

THE SOFTWARE, DESIGN AND/OR HARDWARE IS PROVIDED “AS IS”, WITHOUT WARRANTY OF ANY KIND, EXPRESS OR IMPLIED, INCLUDING BUT NOT LIMITED TO THE WARRANTIES OF MERCHANTABILITY, FITNESS FOR A PARTICULAR PURPOSE AND NONINFRINGEMENT. IN NO EVENT SHALL THE AUTHORS OR COPYRIGHT HOLDERS BE LIABLE FOR ANY CLAIM, DAMAGES OR OTHER LIABILITY, WHETHER IN AN ACTION OF CONTRACT, TORT OR OTHERWISE, ARISING FROM, OUT OF OR IN CONNECTION WITH THE SOFTWARE OR THE USE OR OTHER DEALINGS IN THE SOFTWARE.

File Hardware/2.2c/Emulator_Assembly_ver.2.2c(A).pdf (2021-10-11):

EPROM EMU NG – Assembly Instructions.

For PCB version 2.2c


MyGeekyHobby.com – Apr 2021

Document version: 2.2c(A)

EPROM EMU NG – Assembly Instructions 2.2c(A). MyGeekyHobby.com– Oct 2021


© MyGeekyHobby.com 2021

Thank you for purchasing the “EPROM EMU NG” DIY Kit, following is a brief assembly instruction.

This document is being updated regularly, check my GitHub page for updates:

https://github.com/Kris-Sekula/EPROM-EMU-NG

Before you begin, familiarize yourself with locations of components on the blank PCB

Solder components starting with the shortest.

1. Populate resistors R1, R2 – 1k, resistors R3, R7, R8 – 10k, resistor R4 – 4.7k, resistors R5,R6 – 10R and diode D1 (BAT48):


Note: Pay attention to diode D1 polarity, the black band should point towards the “K”.

2. Populate the precision socket for resistor network RN2

Useful tip:


Solder one of the middle pins first, this will give you opportunity to check if the socket is straight, and adjust if needed before you solder all other pins.

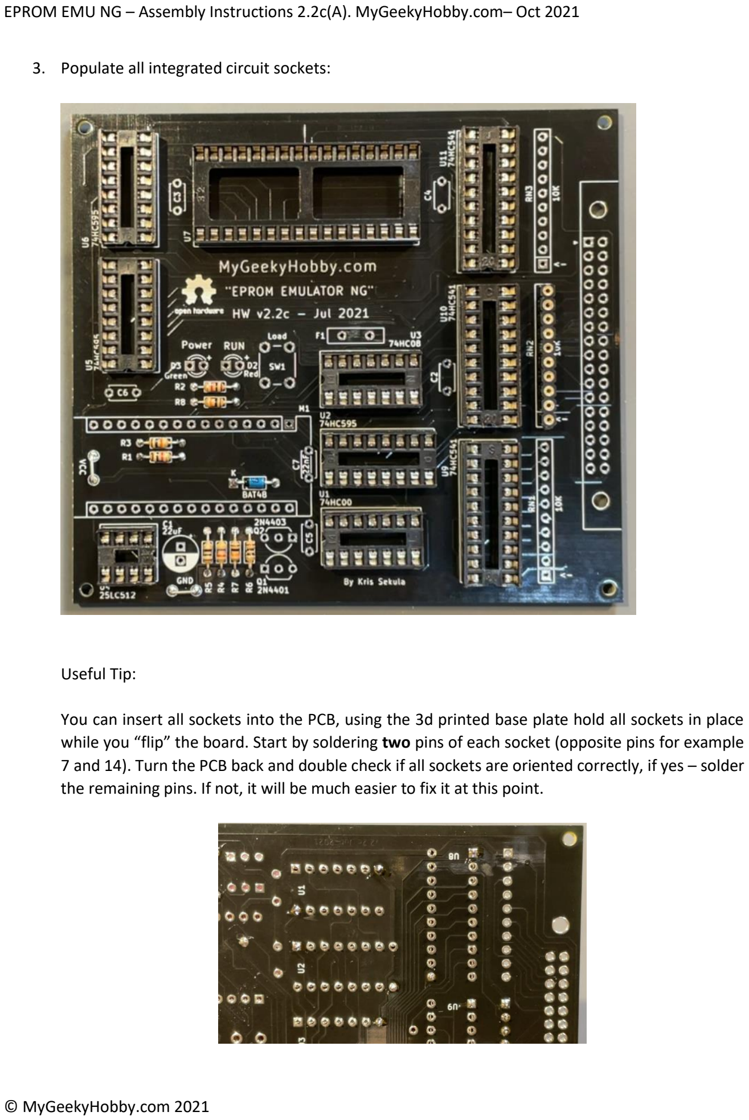
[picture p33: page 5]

3. Populate all integrated circuit sockets:

Useful Tip:

You can insert all sockets into the PCB, using the 3d printed base plate hold all sockets in place while you “flip” the board. Start by soldering two pins of each socket (opposite pins for example 7 and 14). Turn the PCB back and double check if all sockets are oriented correctly, if yes – solder the remaining pins. If not, it will be much easier to fix it at this point.

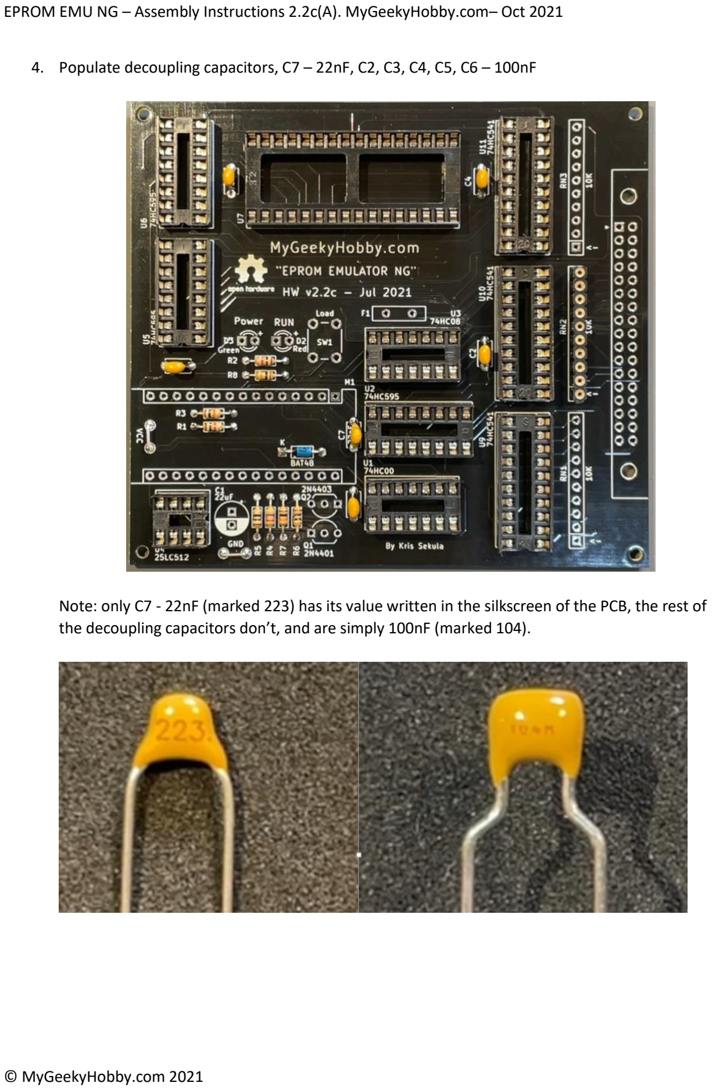
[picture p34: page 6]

4. Populate decoupling capacitors, C7 – 22nF, C2, C3, C4, C5, C6 – 100nF

Note: only C7 - 22nF (marked 223) has its value written in the silkscreen of the PCB, the rest of the decoupling capacitors don’t, and are simply 100nF (marked 104).

5. Populate the LEDs and the push button:


Useful Tip:
The longer lead of the LED should go to the hole marked with “+”.

Keep the cut-offs from the LED as you will need them in the next step

Note:
The current firmware of the emulator uses the push button in the following way:
a) Short press – loads the content of the SPI EEPROM into the SRAM
b) Long press – resets the target device (if the reset hooks are attached)

6. Use the LED cut-offs to populate the “GND” and “VCC” test points:

Useful Tip:


Those test points are “handy” place to attach ground from a logic probe or multimeter during firmware development.

7. Populate transistors Q1 – 2N4401 and Q2 – 2N4403:


Useful tip:
Solder just the middle pin of the transistors, check if the transistor “stands” straight and adjust if needed before you solder the other two pins.
8. Populate C1 – 22uF/16V


Note: Pay attention to capacitor polarity, white band mark negative lead!

9. Populate the Arduino Nano sockets M1a/M1b:


Useful tip:

If you insert the sockets into the PCB and lay it upside down on a flat surface, the socket will line up with the surface and stay straight… otherwise you can also use the trick of soldering a single pin first, and check if the socket is straight, correct if needed before soldering all other pins.

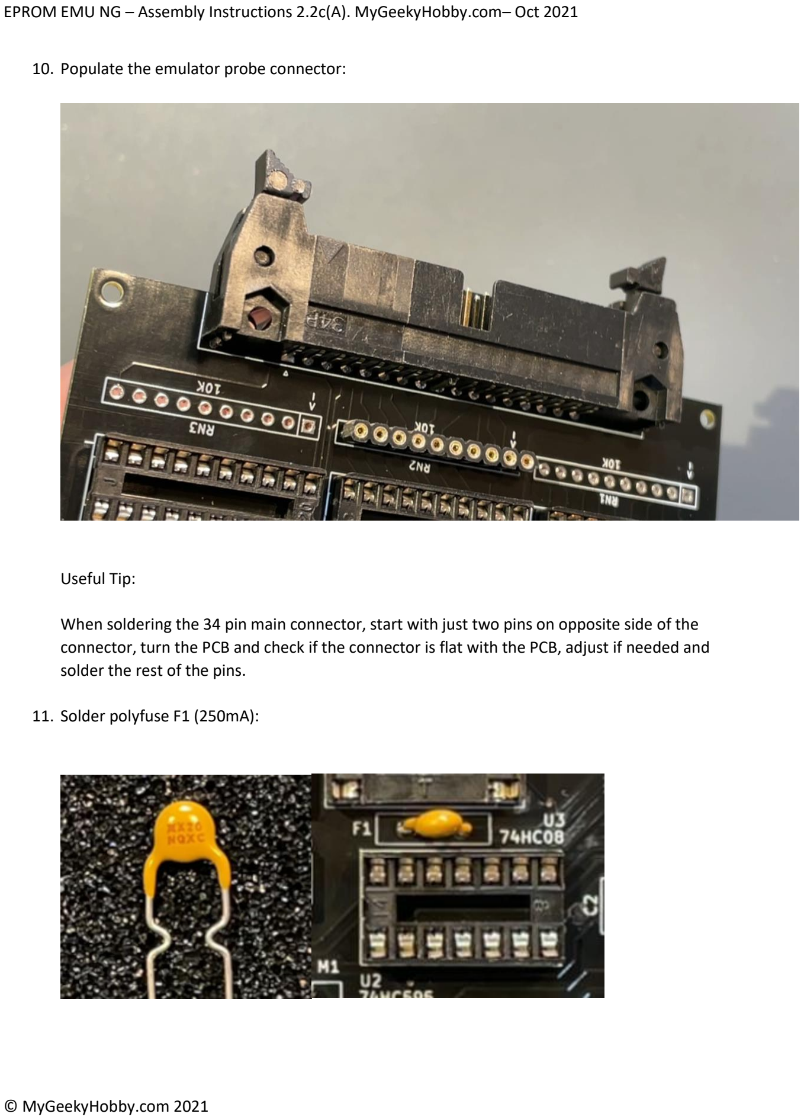
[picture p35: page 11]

10. Populate the emulator probe connector:

Useful Tip:

When soldering the 34 pin main connector, start with just two pins on opposite side of the connector, turn the PCB and check if the connector is flat with the PCB, adjust if needed and solder the rest of the pins.

11. Solder polyfuse F1 (250mA):

12. Solder the Nano pins, you can fist insert the pins into sockets in the PCB before soldering the Arduino module:


Be careful not to misalign the module, make sure all pins are in correct position before you start soldering:


At this point all soldering is finished, you should clean the PCB and the Arduino module with 99% Isopropyl alcohol or similar PCB cleaner.

13. Prepare the base plate by adding the rubber feet:


14. Secure the PCB into the base plate using two sets of screws and nuts, the PCB is now ready to populate the components:

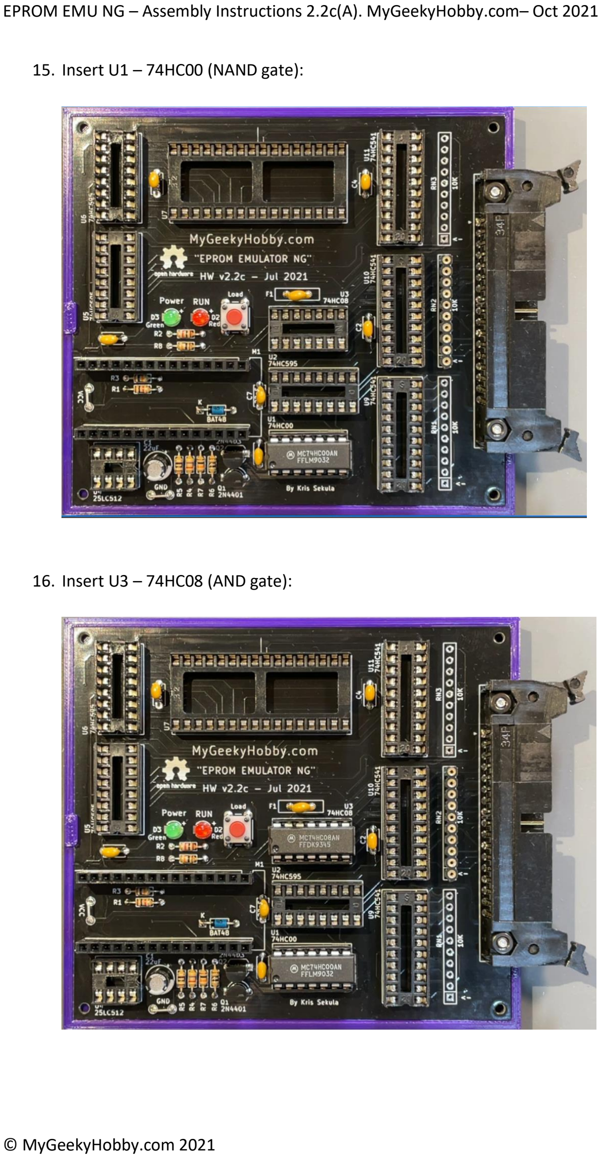
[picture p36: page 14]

15. Insert U1 – 74HC00 (NAND gate):
16. Insert U3 – 74HC08 (AND gate):

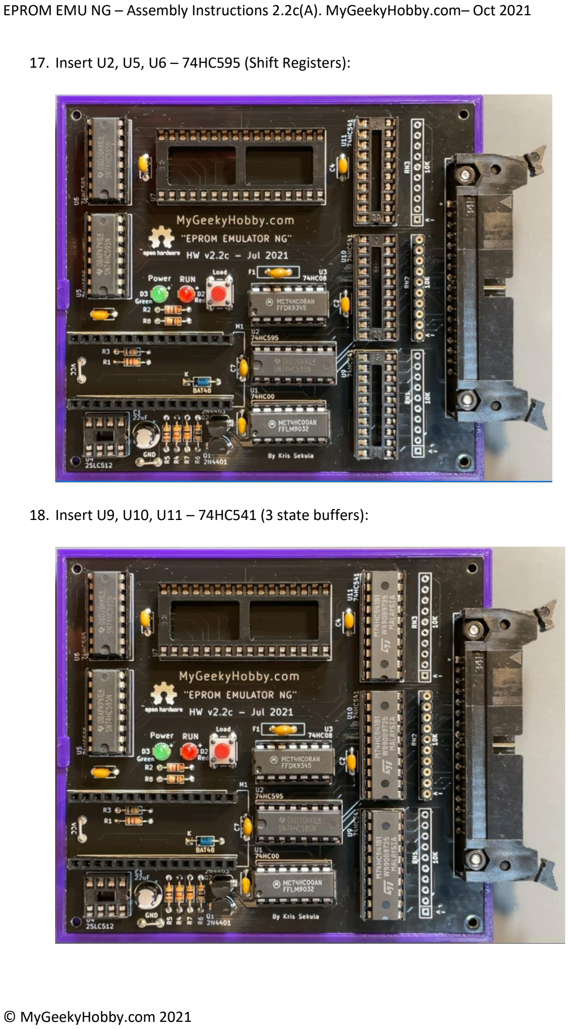
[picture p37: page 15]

17. Insert U2, U5, U6 – 74HC595 (Shift Registers):
18. Insert U9, U10, U11 – 74HC541 (3 state buffers):

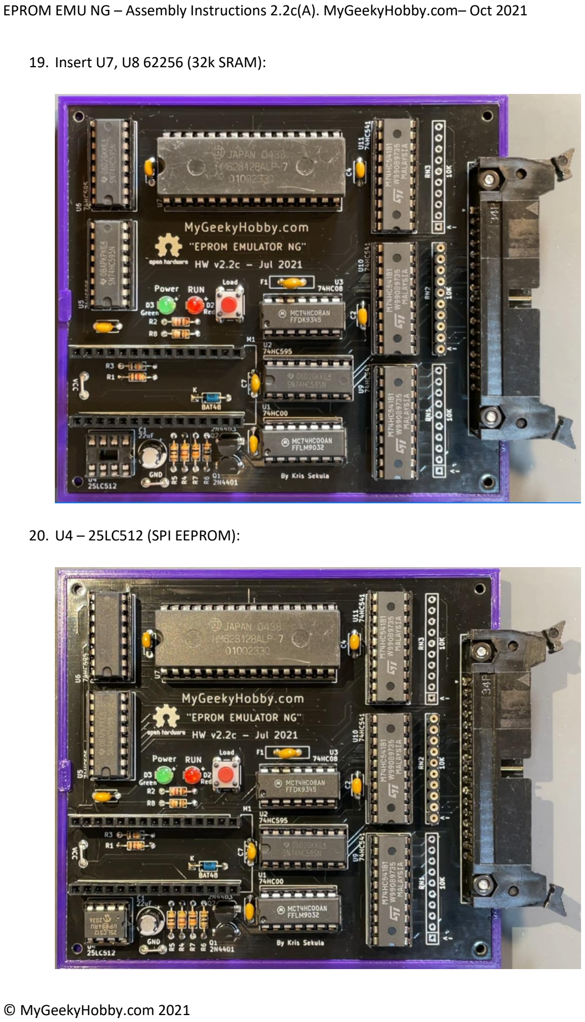
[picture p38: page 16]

19. Insert U7, U8 62256 (32k SRAM):
20. U4 – 25LC512 (SPI EEPROM):

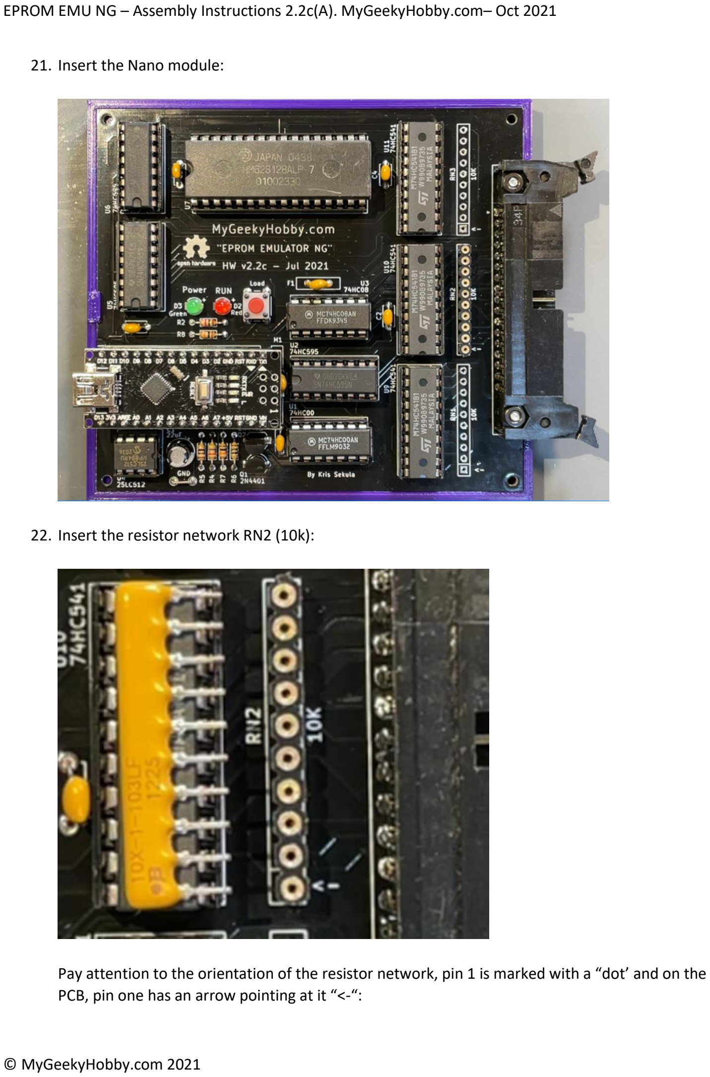
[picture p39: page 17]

21. Insert the Nano module:
22. Insert the resistor network RN2 (10k):

Pay attention to the orientation of the resistor network, pin 1 is marked with a “dot’ and on the PCB, pin one has an arrow pointing at it “<-“:

At this point your “EPROM EMULATOR NG” is assembled, you should program the Arduino Nano with the recommended version of firmware (Arduino sketch) and use it with compatible version of software (python script).

You will also need to build the Emulator Cable, detailed video instructions are here:

https://youtu.be/pb_EF_JVYxc?t=812

Legal Notice:

THE SOFTWARE, DESIGN AND/OR HARDWARE IS PROVIDED “AS IS”, WITHOUT WARRANTY OF ANY KIND, EXPRESS OR IMPLIED, INCLUDING BUT NOT LIMITED TO THE WARRANTIES OF MERCHANTABILITY, FITNESS FOR A PARTICULAR PURPOSE AND NONINFRINGEMENT. IN NO EVENT SHALL THE AUTHORS OR COPYRIGHT HOLDERS BE LIABLE FOR ANY CLAIM, DAMAGES OR OTHER LIABILITY, WHETHER IN AN ACTION OF CONTRACT, TORT OR OTHERWISE, ARISING FROM, OUT OF OR IN CONNECTION WITH THE SOFTWARE OR THE USE OR OTHER DEALINGS IN THE SOFTWARE.

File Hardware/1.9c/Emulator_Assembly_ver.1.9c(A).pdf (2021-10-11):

EPROM EMU NG – Assembly Instructions.

For PCB version 1.9c

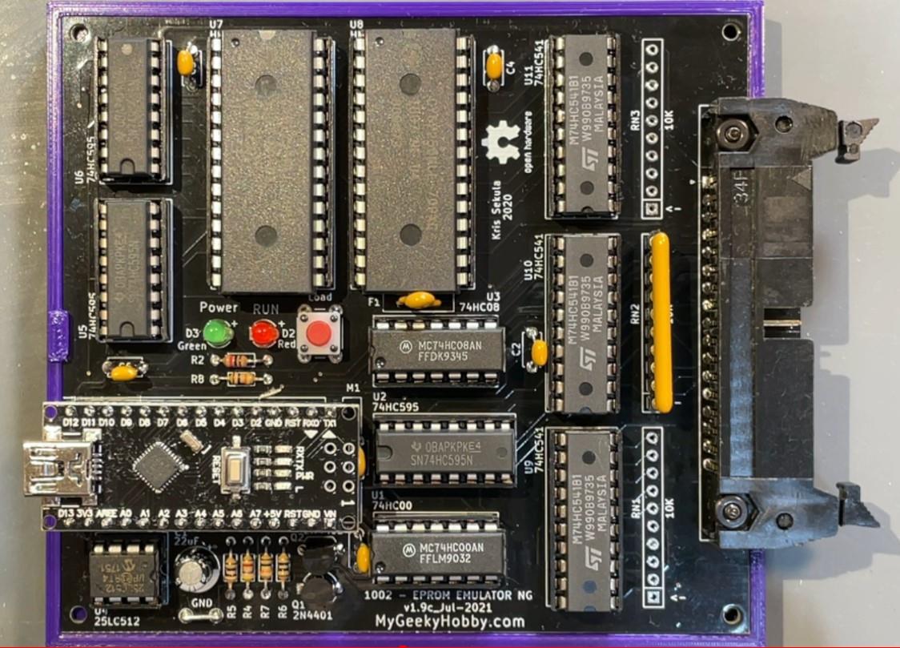
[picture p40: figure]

MyGeekyHobby.com – Oct 2021

Document version: 1.9c(A)

EPROM EMU NG – Assembly Instructions 1.9c(A). MyGeekyHobby.com– Oct 2021

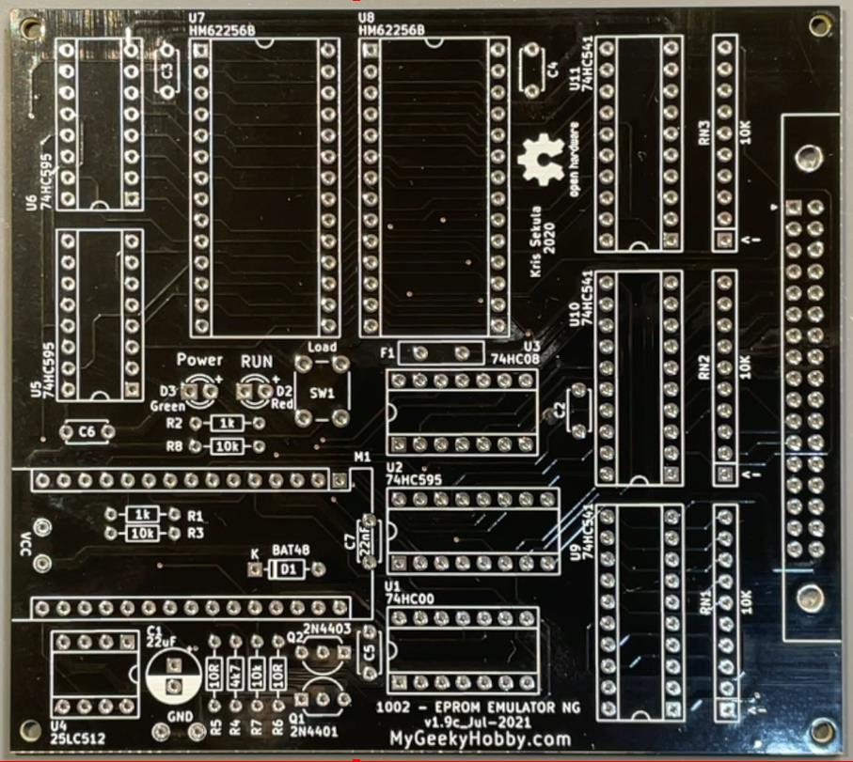
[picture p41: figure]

© MyGeekyHobby.com 2021

Thank you for purchasing the “EPROM EMU NG” DIY Kit, following is a brief assembly instruction.

This document is being updated regularly, check my GitHub page for updates:

https://github.com/Kris-Sekula/EPROM-EMU-NG

Before you begin, familiarize yourself with locations of components on the blank PCB

Solder components starting with the shortest.

1. Populate resistors R1, R2 – 1k, resistors R3, R7, R8 – 10k, resistor R4 – 4.7k, resistors R5,R6 – 10R and diode D1 (BAT48):

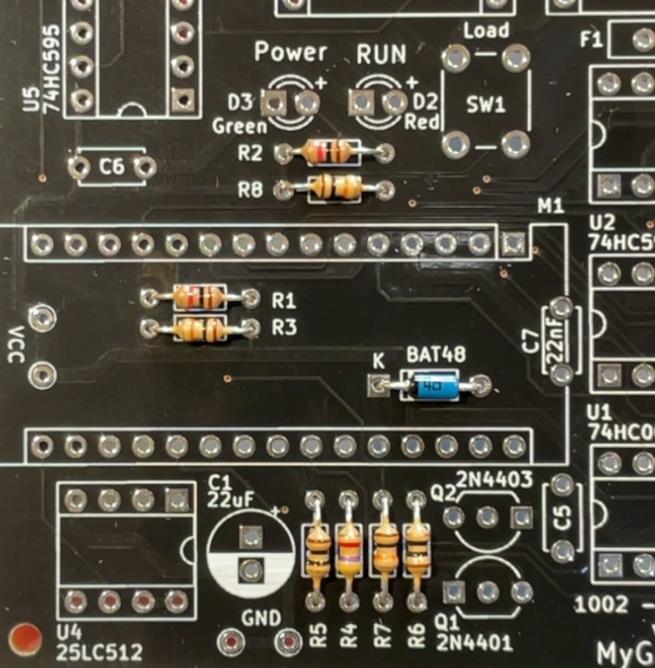
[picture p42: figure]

Note: Pay attention to diode D1 polarity, the black band should point towards the “K”.

2. Populate the precision socket for resistor network RN2

Useful tip:


Solder one of the middle pins first, this will give you opportunity to check if the socket is straight, and adjust if needed before you solder all other pins.

3. Populate all integrated circuit sockets:

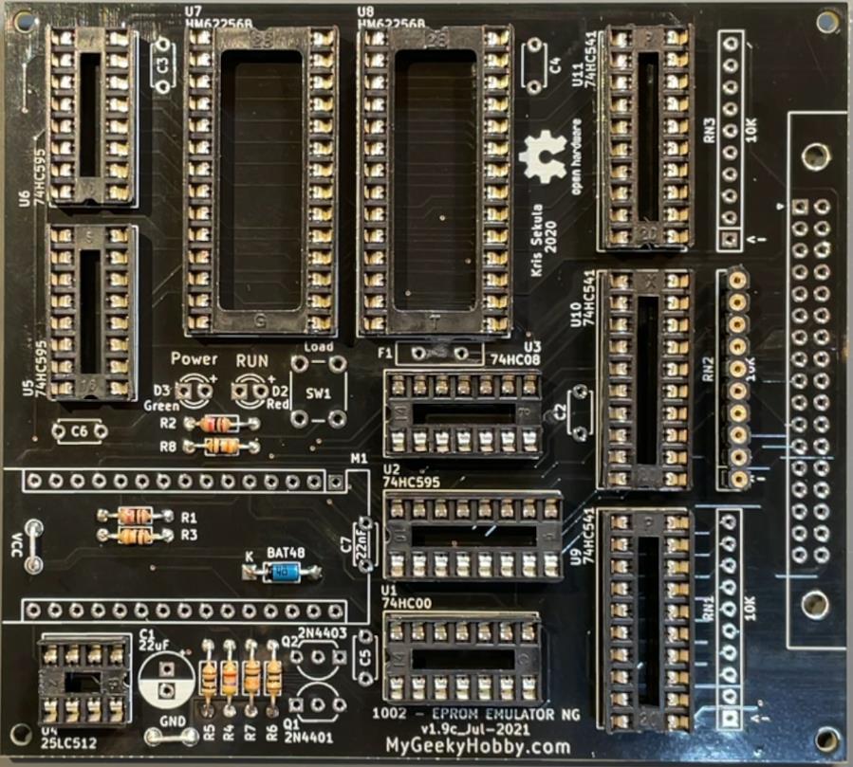
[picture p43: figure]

Useful Tip:

You can insert all sockets into the PCB, and using the 3d printed base plate hold all sockets in place while you “flip” the board exposing all pins. Start by soldering two pins of each socket (opposite pins for example 7 and 14). Turn the PCB back and double check if all sockets are oriented correctly, if yes – solder the remaining pins. If not, it will be much easier to fix it at this point.

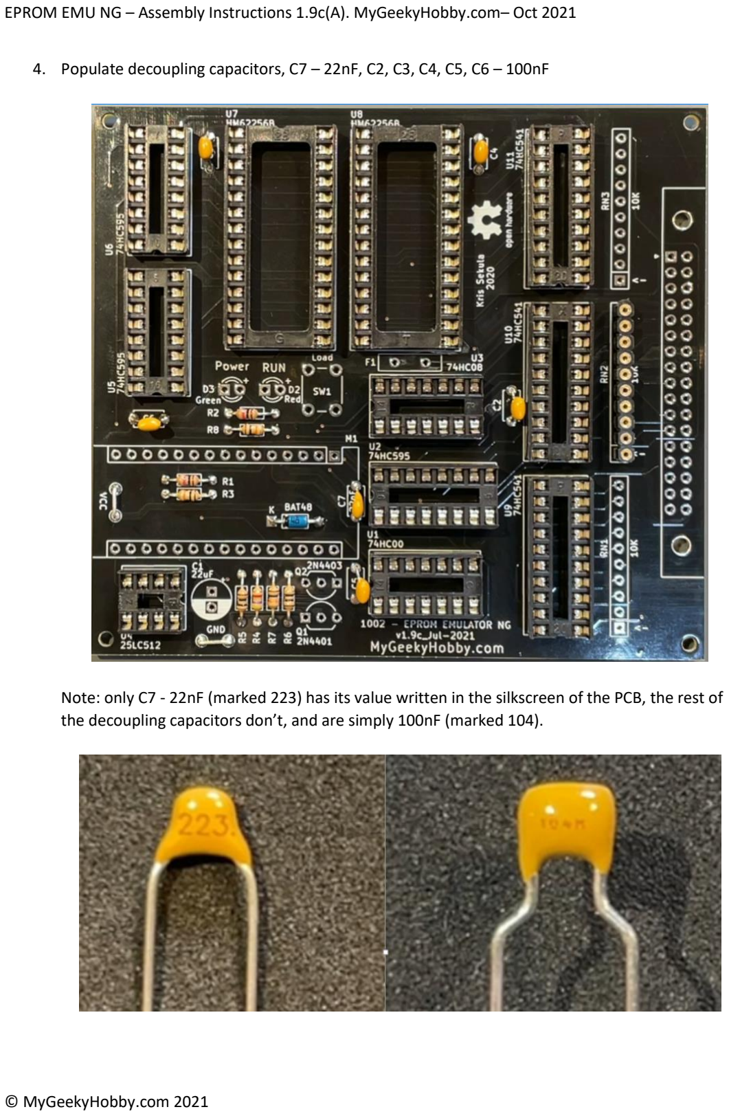
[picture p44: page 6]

4. Populate decoupling capacitors, C7 – 22nF, C2, C3, C4, C5, C6 – 100nF

Note: only C7 - 22nF (marked 223) has its value written in the silkscreen of the PCB, the rest of the decoupling capacitors don’t, and are simply 100nF (marked 104).

5. Populate the LEDs and the push button:

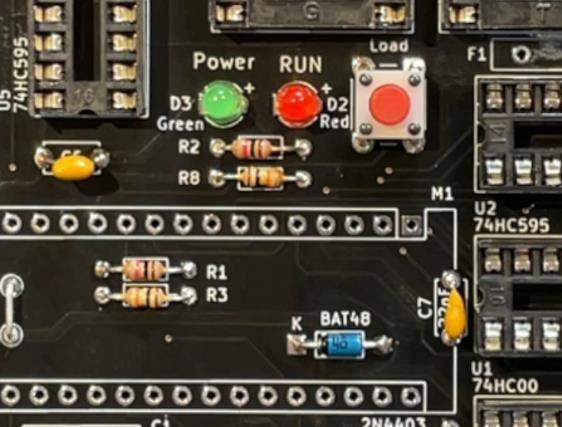
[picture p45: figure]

Important note:
Pay attention to the polarity of the LED, the longer lead of the LED should go to the hole marked with “+”.

Keep the cut-offs from the LED as you will need them in the next step

Note:
The current firmware of the emulator uses the push button in the following way:
a) Short press – loads the content of the SPI EEPROM into the SRAM
b) Long press – resets the target device (if the reset hooks are attached)

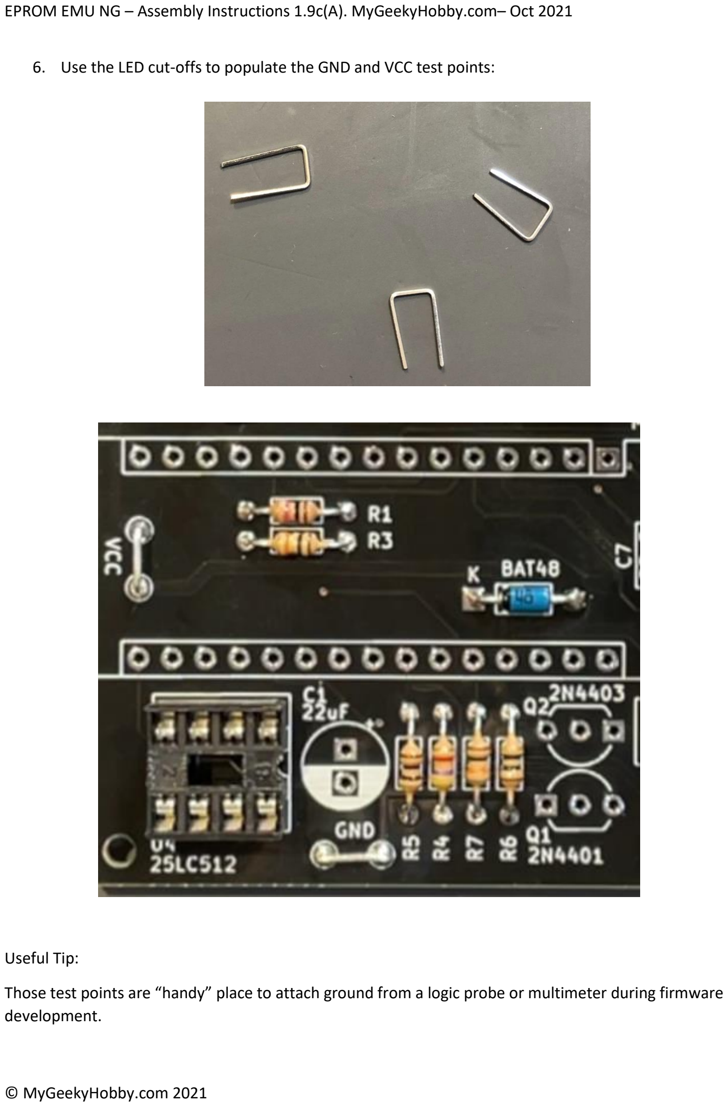
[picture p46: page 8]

6. Use the LED cut-offs to populate the GND and VCC test points:

Useful Tip:

Those test points are “handy” place to attach ground from a logic probe or multimeter during firmware development.

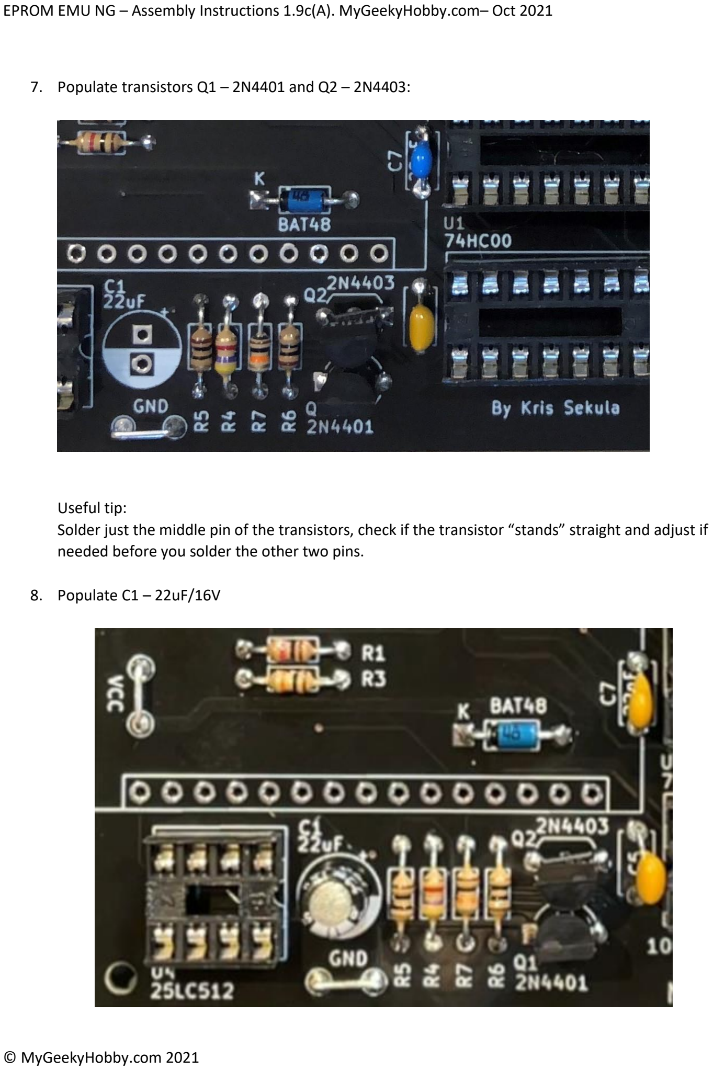
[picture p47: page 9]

7. Populate transistors Q1 – 2N4401 and Q2 – 2N4403:

Useful tip:
Solder just the middle pin of the transistors, check if the transistor “stands” straight and adjust if needed before you solder the other two pins.
8. Populate C1 – 22uF/16V

9. Populate the polyfuse F1 – 250mA:

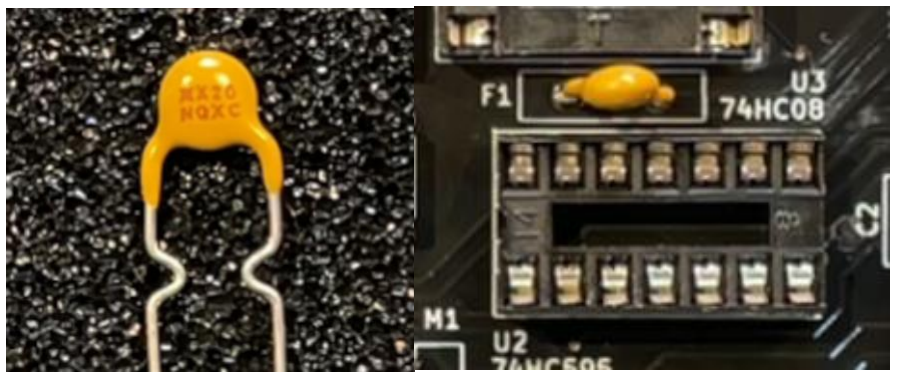
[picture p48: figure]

10. Populate the Arduino Nano sockets M1a/M1b:

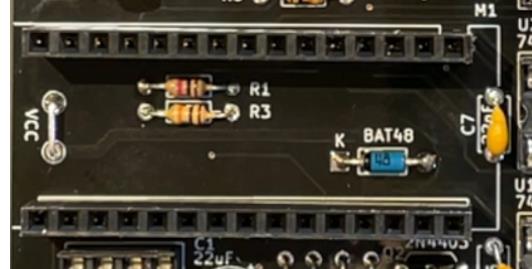
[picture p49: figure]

Useful tip:
If you insert the sockets into the PCB and lay it upside down on a flat surface, the socket will line up with the surface and stay straight… otherwise you can also use the trick of soldering a single pin first, and check if the socket is straight, correct if needed before soldering all other pins.

11. Populate the emulator probe connector:

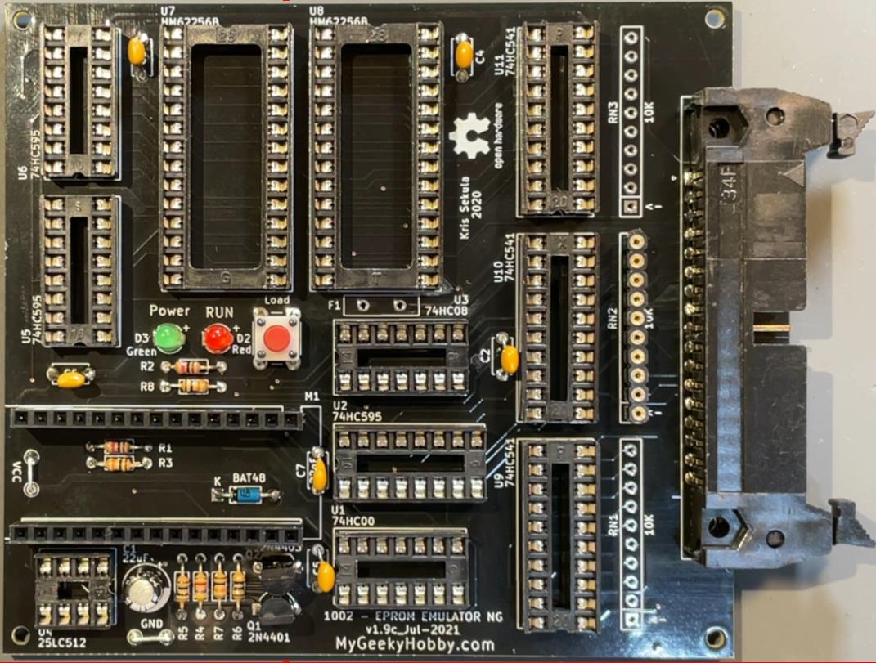
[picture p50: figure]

Useful Tip:

When soldering the 34 pin main connector, start with just two pins on opposite side of the connector, turn the PCB and check if the connector is flat with the PCB, adjust if needed and solder the rest of the pins.

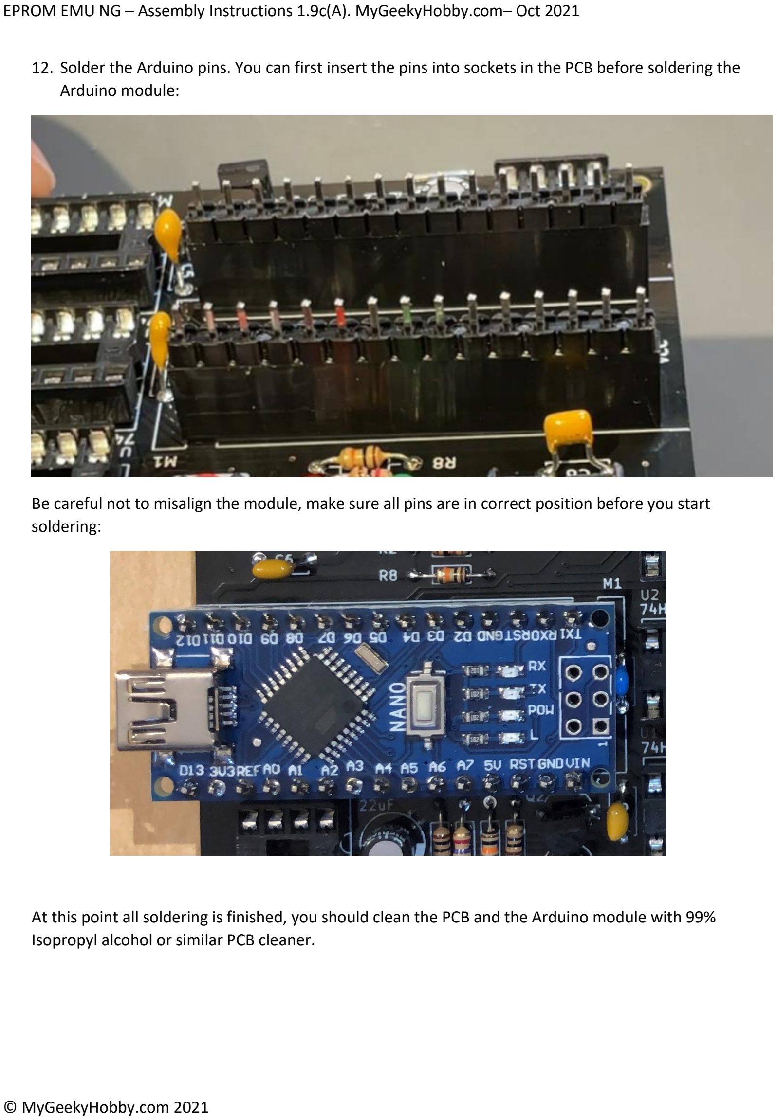
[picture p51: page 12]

12. Solder the Arduino pins. You can first insert the pins into sockets in the PCB before soldering the Arduino module:

Be careful not to misalign the module, make sure all pins are in correct position before you start soldering:

At this point all soldering is finished, you should clean the PCB and the Arduino module with 99% Isopropyl alcohol or similar PCB cleaner.


13. Prepare the base plate by adding the rubber feet:
14. Secure the PCB into the base plate using two sets of screws and nuts, the PCB is now ready to populate the components:


15. Insert U1 – 74HC00 (NAND gate):
16. Insert U3 – 74HC08 (AND gate):


17. Insert U2, U5, U6 – 74HC595 (Shift Registers):
18. Insert U9, U10, U11 – 74HC541 (3 state buffers):


19. Insert U7, U8 62256 (32k SRAM):
20. U4 – 25LC512 (SPI EEPROM):

21. Insert the Nano module:


22. Insert the resistor network RN2 (10k):


Pay attention to the orientation of the resistor network, pin 1 is marked with a “dot’ and on the PCB, pin one has an arrow pointing at it “<-“:

At this point your “EPROM EMULATOR NG” is assembled, you should program the Arduino Nano with the recommended version of firmware (Arduino sketch) and use it with compatible version of software (python script).

You should now build the Emulator Cable, detailed video instructions are here:

https://youtu.be/pb_EF_JVYxc?t=812

Legal Notice:

THE SOFTWARE, DESIGN AND/OR HARDWARE IS PROVIDED “AS IS”, WITHOUT WARRANTY OF ANY KIND, EXPRESS OR IMPLIED, INCLUDING BUT NOT LIMITED TO THE WARRANTIES OF MERCHANTABILITY, FITNESS FOR A PARTICULAR PURPOSE AND NONINFRINGEMENT. IN NO EVENT SHALL THE AUTHORS OR COPYRIGHT HOLDERS BE LIABLE FOR ANY CLAIM, DAMAGES OR OTHER LIABILITY, WHETHER IN AN ACTION OF CONTRACT, TORT OR OTHERWISE, ARISING FROM, OUT OF OR IN CONNECTION WITH THE SOFTWARE OR THE USE OR OTHER DEALINGS IN THE SOFTWARE.

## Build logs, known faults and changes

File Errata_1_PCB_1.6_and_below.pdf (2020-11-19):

Errata 1 to EPROM Emulator NG, PCB versions 1.6 and below.

Dear users of the EPROM Emulator NG, I recently discovered a potential flaw in the design of the emulator. Refer to the diagram of the emulator posted to GitHub dated (2020-05-05), parts shown here:

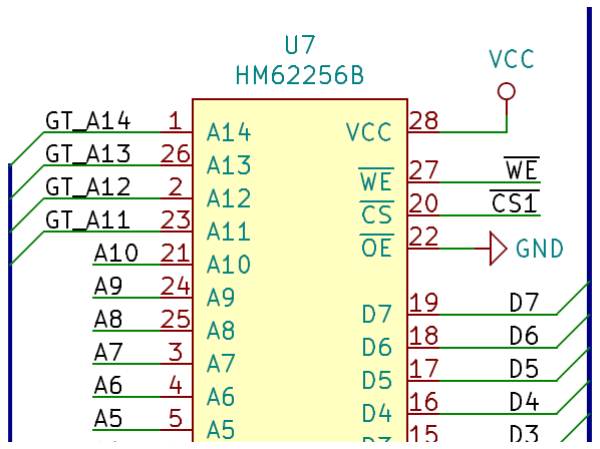
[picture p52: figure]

As you can see, the /OE line (pin 22) is connected to ground (GND), permanently enabling the output of the one of the SRAMs at any point of time (the other control line /CS is driven by the state of address line A15). This creates a potential issue, when the emulator is waiting for data from the computer and the shift registers are enabled, driving at the same time the data bus. This situation continues until data from computer or the SPI EEPROM is loaded into SRAM and the “emulation” starts (shift registers get disabled and external buffers - 74HC541 enabled). In my initial design and prototype of the emulator I had those lines correctly connected to the “Reset” signal, this way it guarantees only one of those can be active on the data line at any point, but while I was troubleshooting a completely unrelated issue I disconnected the OE lines from Reset and connected them to GND, I carried over the flawed design to later releases of the PCBs and only just noticed the mistake.

Interestingly this has not caused any functional issue for the many emulators that are currently in use, they are working and serving many of you very well, never the less I will publish updated diagram and new PCB design (1.7), the correct way to connect the SRAM is as follows:

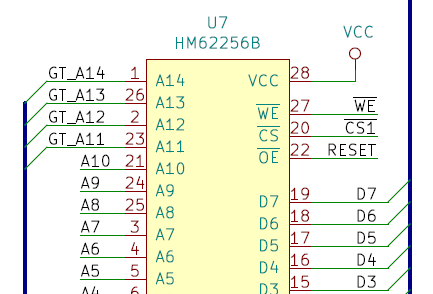
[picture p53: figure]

New builds of the emulator should follow the corrected design and the new PCB layout. For current users I recommend doing ONE of the following:

Option A: Hardware modification of the PCB: very simple, cut one track to separate the /CS line from GND, and run a short link of wire to connect the /CS to RESET:

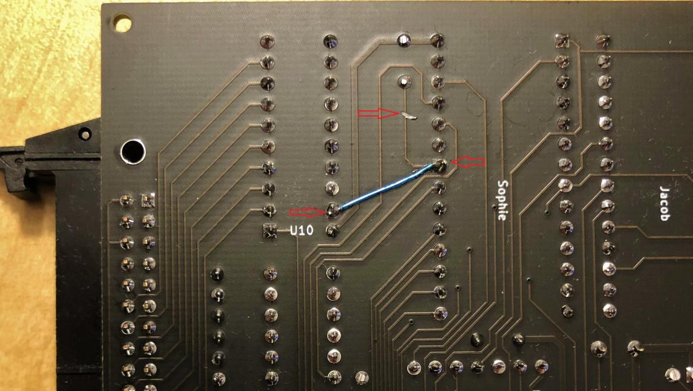
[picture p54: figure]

Option B: Use Arduino IDE and upload firmware 2.0rc1 or newer to the emulator. The new firmware disables the output buffers (and this way enables the shift registers) only once transfer from the computer starts (or the restore from SPI EEPROM is initiated), this way minimizing the potential for data bus “clash”.

I have tested both options and they work as expected, but “Option A” would be preferred as it guarantees in hardware that data bus “clash” doesn’t happen.

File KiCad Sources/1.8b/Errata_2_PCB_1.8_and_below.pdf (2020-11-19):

Errata 2, EPROM Emulator NG, PCB versions 1.8 and below.

Q1(2N4401) and Q2(2N4403) on the assembled device or supplied with the emulator kit uses different pinout than the one used on the PCB (although the silkscreen says 2N440x, in fact the footprint used on the PCB is for BC547 and BC557 and those transistors are not officially interchangeable as they use different pinout for Emitter and Collector). The correct way to populate the supplied 2N4401 and 2N4403 is so that the “flat” part of the transistors are facing away from each other, as pictured below.

Although this is not essential, it is recommended to re-install transistor Q1 – 2N4401 and Q2 – 2N4403 according to the picture here. Note that since the transistors in the emulator design are used simply to buffer the reset lines, even with those transistors installed incorrectly the “reset” function of the emulator will continue working as expected, the transistor will operate in somewhat unusual “Reverse Active” mode. If you don’t have facility to correct the transistors installation you can leave them installed the way they were shipped to you.

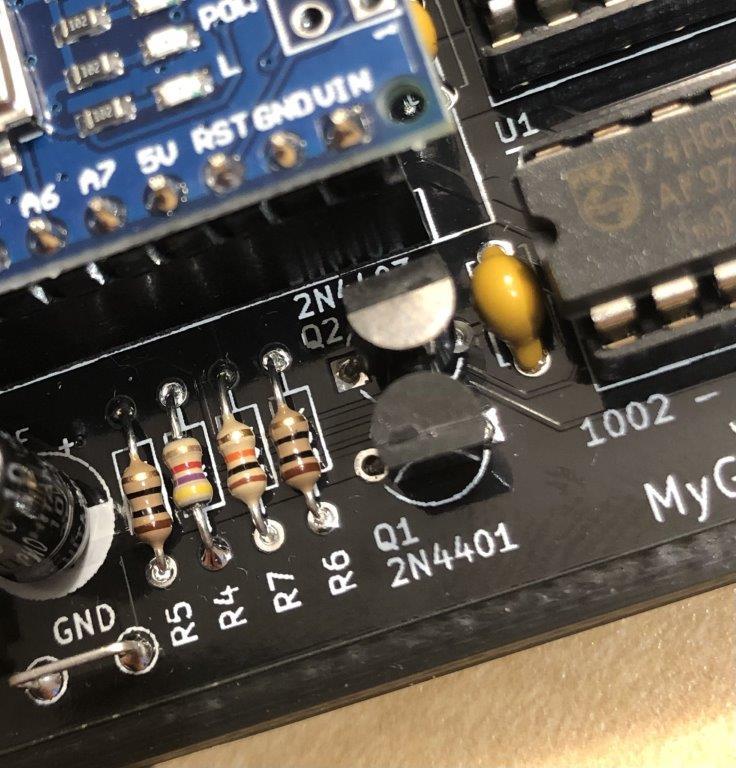
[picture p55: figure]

The silkscreen print for Q1 and Q2 has been fixed in PCB versions 1.8b onwards.

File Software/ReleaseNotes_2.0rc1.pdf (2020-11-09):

MyGeekyHobby.com “EPROM EMULATOR NG”

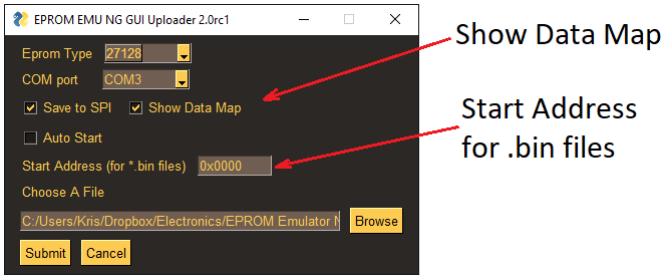
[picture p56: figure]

© MyGeekyHobby.com 2020

FIRMWARE AND SOFTWARE VERSION 2.0 rc1 release notes:

What’s new:

- speed improvements, data is transferred to the emulator in binary format, so it now takes only around 11s for 64Kb (27512 EPROM) - around 15s when “-spi” option is enabled.
- The “-spi” option now works correctly for any range of data (SPI EEPROM save option).
- Support for both binary files (.bin) and iHEX files (.hex). For binary files you can provide the start address to load the data in with “–address” option (defaults to 0x0000h).
- GUI now saves previously used parameters (you must run pysimplegui 4.30.0 or newer).
- “Data Map” shows where the information is loaded.

Before you run the new python script upgrade the “pysimplegui” package, must be 4.30.0 or newer, you can check what you are running and upgrade using “pip” commands:

#pip show pysimplegui

Name: PySimpleGUI

Version: 4.30.0

If version shows anything below 4.30.0 run the upgrade:

#pip install pysimplegui -U

Some additional information. The software / firmware has been largely changed, in the past most of the “logic” in processing the file was done on the Arduino, now it’s all done in the python code on the computer. The script maintains a local “buffer” where all the data gets loaded first. The buffer is split into 128Bytes “blocks” and any block that has been used is marked for upload to the emulator. Data gets uploaded to the emulator in packets of between 1 and 4, 128Byte blocks.

The control script now shows a data map, representing the blocks of data that will be sent to the emulator, it’s a nice way to “see” where your file will be placed in the address space. Each “*” or “_” represents 128 Bytes of data sectors, “*” is a sector with data and “_” is a sector with no data (the bin or hex file had no data for that area of the memory space). Only the sectors with data (“*”) are transferred to the emulator.

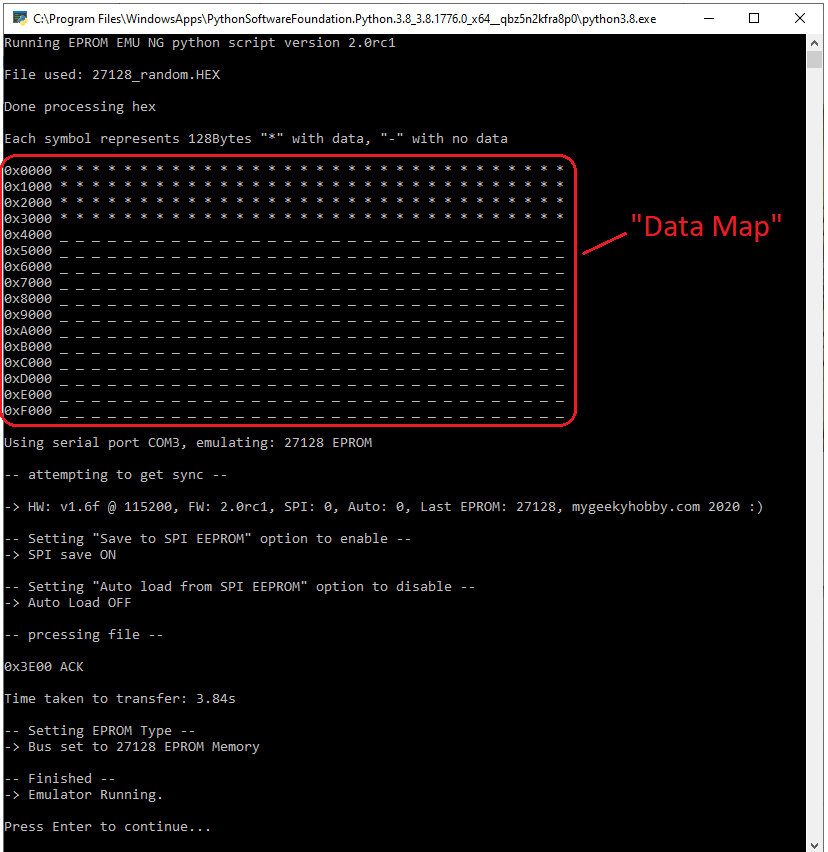
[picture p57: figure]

This is an a “Release Candidate” version of the software and is likely to still contain bugs, use with caution, please report any bugs if found.

Legal Notice:

THE SOFTWARE, DESIGN AND/OR HARDWARE IS PROVIDED “AS IS”, WITHOUT WARRANTY OF ANY KIND, EXPRESS OR IMPLIED, INCLUDING BUT NOT LIMITED TO THE WARRANTIES OF MERCHANTABILITY, FITNESS FOR A PARTICULAR PURPOSE AND NONINFRINGEMENT. IN NO EVENT SHALL THE AUTHORS OR COPYRIGHT HOLDERS BE LIABLE FOR ANY CLAIM, DAMAGES OR OTHER LIABILITY, WHETHER IN AN ACTION OF CONTRACT, TORT OR OTHERWISE, ARISING FROM, OUT OF OR IN CONNECTION WITH THE SOFTWARE OR THE USE OR OTHER DEALINGS IN THE SOFTWARE.

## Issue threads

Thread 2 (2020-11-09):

Read current address target device

dimiras, 2020-11-09:
Hello,
Is it possible to read which address the target device is accessing?

Thanks

Kris-Sekula, 2020-11-10:
Hi,

hmm, that would be pretty tricky as the address being accessed will constantly change while the target system is running.

What is the use case on your mind?

Kris

dimiras, 2020-11-10:
The use case I have in mind is to use it inside a car ecu, and have map tracing to know which map and cell is being accessed.
Something like this https://www.youtube.com/watch?v=iVGGv_PYTxI

Kris-Sekula, 2020-11-10:
oh, I see. Nope, sorry the current hardware of the emulator can't do that. I think someone else who is using my emulator for ECU, was asking me a similar question but I didn't realize what he meant... after viewing the video I now get the question, thanks :)

dimiras, 2020-11-10:
Ok thanks a lot :) Do you think that the hardware would need many changes to get a feature like this? I am a Software Engineer, so I would not have no problem with code side of things, but in terms of eletronic hardware I dont have a clue.

Kris-Sekula, 2020-11-10:
Yep, you the hardware would have to be completely changed. If the address being accessed doesn't change too fast, you can do it with a larger microcontroller ... otherwise, you would need an FPGA or something similar to keep track in real-time.

dimiras, 2020-11-10:
The target device uses a Intel 8051 at 12mhz

Kris-Sekula, 2020-11-10:
according to that video, you can see the CPU jumping between addresses once or twice a second, which is considered "slow" and a simple microcontroller to monitor the address lines would be enough... but if the target CPU is "jumping" between locations at full speed (8051 can do a million instruction per second), you would have to take a different approach. If you have access to the commercial hardware you can have a look at how they do it :)

dimiras, 2020-11-10:
I think they only monitor the addresses where the map values are and ignore the other memory accesses that the 8051 reads while going through the code. From what I could figure out they are using a fpga.

Closed 2020-11-12.

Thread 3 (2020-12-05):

Starting target in RESET

hubertushirsch, 2020-12-05:
Hi Kris,

in setup() you starting the emulator with EN_RST = LOW, with means, the target is not in reset.

pinMode( EN_RST, OUTPUT ); digitalWrite( EN_RST, LOW );  // disable outputs to start with AD0-15 from outside

What is the reason for this setting?
After the emulator is powered on, the content of the SRAM is not defined, it is random.
That is, the target system's CPU starts executing random code.
Maybe that's not a problem in an Atari or something similar.

In my use case I want to emulate the firmware ROM of an industrial system.
This stores important data in a battery-backed CMOS RAM.
The execution of unknown code after the start could overwrite data or cause unwanted signal combinations at external I/O connections.

I would prefer the emulator to start with holding the target system in reset (EN_RST = HIGH) until the SRAM contains defined content and EN_A11 to EN_A15 are set appropriately. The target system should only be released after autoload from the SPI, upload from the PC or manual load from the SPI using the push button.

Thanks
Ralf

Kris-Sekula, 2020-12-05:
Hey Ralf,

Yes, I know exactly what part of the code you are talking about.

This has been done on purpose, to mitigate the issue with PCB 1.6 and
below, where the CE of the SRAM is permanently plugged to the ground. To
minimise the chance of both the shift register and the SRAM outputting data
on the data bus, I keep the emulator in "emulation" mode after boot and
only enable the shift registers just before I'm ready to write the data to
SRAM (and WE changes the SRAM to data line to inputs).

If you are using v1.8 and above (or you modified v1.6 as per the errata)
you can change the code and keep the target reset when you power comes up.

Thanks
Kris

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

hubertushirsch, 2020-12-06:
Thanks Kris for the explanation.

I have the PCB 1.7.  /OE of the SRAMs is connected to RESET.

Setting EN_RST to HIGH when the program starts is a bit tricky. Here is the solution to how I modified my emulator.

After resetting the MCU in the Arduino, the associated port data register and the port data direction register are set to zero (0).
This means that the pin on the Arduino is in INPUT mode and therefore high-resistance/floating.
It is not certain whether U1D (74HC00 pin 11,12) will treat the floating inputs as HIGH or LOW (U1 is CMOS, not TTL).
So the state of RESET in emulator is also not predictable.
To get a defined level in this intermediate state, I connected a 10kOhm resistor to EN_RST as a external pull-up.

The next is the initialization of EN_RST in the setup() routine.
Since the Arduino first executes a series of internal code after the reset, which cannot be seen by the user, it takes a while until the setup() function is executed.

The obvious sequence

**pinMode( EN_RST, OUTPUT ); digitalWrite( EN_RST, HIGH );  // target reset, enable shift register, disable 541 buffers**

to initialize the EN_RST line has a pitfall.
Since the port data register is at zero (0) by the MCU reset, executing **pinMode (EN_RST, OUTPUT)** causes EN_RST to leave the tristate state and actively go to LOW.
Only after executing

**digitalWrite (EN_RST, HIGH);**

we get the desired high level again.

The trick to avoid this pitfall is to first set the port data register to one (1) and then set the port mode to OUTPUT.
As a result, the pin changes immediately from the tristate state to active HIGH.
Since the port data register is used to control the internal pull-up resistor in INPUT mode, you can set the port data register to one (1) in advance by changing from INPUT mode to INPUT_PULLUP.

The following states are passed through:

MCU reset:  PORTD2=0  DDD2=0  Mode=INPUT  EN_RST-Level=High by external pullup
Arduino boot code:  no change
**pinMode(EN_RST, INPUT_PULLUP);** PORTD2=1  DDD2=0  Mode=INPUT_PULLUP  EN_RST-Level=High by ext. pullup parallel to internal pullup
**pinMode(EN_RST, OUTPUT);** PORTD2=1  DDD2=1  Mode=OUTPUT  EN_RST-Level=High by active pin output.

The same applies to WE line (/WE on SRAM's).
The original code in line 196 would run through the sequence Tristate => Active LOW => Active HIGH.
Since we receive an L-H edge at the /WE pins of the SRAM, a data byte is even written in the SRAM here.
At which address and with which value depends on the random states of the shift register after power on.
To avoid this problem, I made the same changes here: External pullup from WE to Vcc and adapt the code.

My changes in the diff file compared to the published EPROM_EMU_NG_FW_2.0rc1.ino

[EPROM_EMU_NG_FW_2.0rc1.diff.txt](https://github.com/Kris-Sekula/EPROM-EMU-NG/files/5649481/EPROM_EMU_NG_FW_2.0rc1.diff.txt)
Greetings
Ralf

Kris-Sekula, 2020-12-07:
Hi Ralf,

Once again, you made a great analysis and proposed a solution. Just a comment, at some point, you wrote: "Maybe that's not a problem in an Atari or something similar". Indeed the emulator design presented here was initially really meant to only be used for hobby projects Atari, Commodore, or simple Z80 SBCs alike. It's not a commercial solution, it was never intended to be used in "industrial" systems or to drive similar "mission-critical" devices. Clearly, you are an experienced engineer and you want to use the emulator to do some "real" work, so you are "sanity" checking, exposing, and helping to fix issues that could potentially cause a problem, thank you! And thank you for sharing those findings with us!

I'll add the proposed code changes to the next releases of the firmware, and I will include the 10k pull-up resistor in the next release of the PCB as those are beneficial to the design.

BTW, do we have to worry about the WE line at all? Even if we end up writing random data to the SRAM it doesn't matter as the SRAM will have random data inside at boot time anyway, and we will be restoring the data using the computer or the restore from SPI EEPROM function... or am I missing something?

Kris

hubertushirsch, 2020-12-07:
Hello Kris

I am aware that this is a hobby project. But I enjoy perfecting my private projects or supporting others with their projects.
If I can improve the emulator with my analyzes and tips, I'll be happy to do so.
The more stable the solution, the higher the user acceptance will be. Hobby users are also happy about well-functioning solutions.
Changes to software or firmware do not cost anyone any money. And a resistor more or less is not the factor to not making an improvement.
Incidentally, there are suggestions from me, the decision whether they make sense and for an implementation of course you make.
In addition, I can be wrong and make mistakes, I think that you test every change proposal thoroughly before you adopt it.
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
Kris-Sekula, 2020-12-08:
Hi Ralf,

Just to close the loop. I'll be adding the pull-up resistors to the next rev of the PCB, for both the Reset and the WE line as it's not "costing" real money when I re-spin the PCB, but it should be noted that the emulator is not reset-resistant, even with the extra pull-ups and software improvements you are proposing. When I was designing the emulator, the Arduino "reset" button was not meant to be used for any function related to the emulator operation...but...wouldn't it be an excellent idea to perform a "target" reset using the Arduino "reset" button? :) Is this what you are trying to fix and I only just realized? haha :) The pull-ups will be required, but we will also have to add some logic in the firmware to re-store the state of the emulator after Arduino hardware "reset", for example, we need to restore the A11-A15 lines to whatever the "last used" EPROM type was...

Kris

hubertushirsch, 2020-12-08:
Hi Kris

You are absolutely right.
If the design does not include a reset on the Arduino for regular use, then it can stay as it is.
I recognize that the situation is more complex than I thought.

mem_cfg in the configuration EEPROM is initially set to mem64kB if it has an invalid value.
After that, mem_cfg is only changed when I upload an image for a different EPROM type and spiSave=1.
Suppose I load a 27128 into the SPI for frequent use. Then mem_cfg is set to mem16kB.
After resetting the emulator with autoLoad=1 or manual loading (push button) everything works fine.

If I now load a 2716 into the SRAM only (saveSPI=0, autoLoad=0) for a short-term test, setbus() is set correctly for the new type, but this is not saved in mem_cfg. That is ok, because mem_cfg should correspond with the image in the SPI EEPROM.
The Emulator starts running my 2716 from SRAM after upload.

After a reset on the Arduino (with all changes that prevent corruption of the SRAM) there is no information for which ROM type an image is in the SRAM.
You have to send (in this example) a ":ini16" and a ":EMUON" from the PC to the emulator so that it starts running on the correct bus.
The manually ":EMUON" to start is necessary anyway, because the emulator should not start with autoLoad=1 and the SPI content (in my vision), but with the SRAM content.
The whole thing can only work if the lastEPROM type is saved in a further configuration variable in the EEPROM config.

I think this is getting very special and doesn't justify the effort.

But thanks anyway for the exciting discussion.

Ralf

hubertushirsch, 2020-12-15:
Hi Kris,

as discussed in the mail, here my current state of development.
There are many changes in it, some of which I have already provided separately.
The diff file against the public v20rc1 is therefore very complex, so I am also sending the full sketch.

The latest changes:

#define or #undef UNFIXED
to include or not include special code for unfixed PCBs (/OE=GND)

ROM type in SRAM and ROM type in SPI are now handled separately,
the new configuration option **sram_cfg** has been introduced for this purpose.
Only after loading the SRAM from the SPI (autoload, push button) or uploading a new image to the SRAM with saveSPI=1 is sram_cfg=mem_cfg.

SPI clock increased to 8MHz (fosc/2). The 25LC512 can tick with 10MHz or higher.
Further changes to performance tuning in
load_SPIEEPROM()
spi_transfer()   --- could be renamed to spi_write ()?

The start of the time measurement in load_SPIEEPROM moved to the beginning of the function.
So the measurement is more realistic than just measuring the loop.

New remote control sequence: LOADSPI
Loads SRAM from the SPI, emulator remains in reset.
The behavior of the pushbutton is controlled by sending
: LOADSPI
: EMUON
to the emulator.

I hope you can find your way around the code despite the many simultaneous changes.

Ralf

[v20rc1ultrafast3.diff.txt](https://github.com/Kris-Sekula/EPROM-EMU-NG/files/5698979/v20rc1ultrafast3.diff.txt)

[v20rc1ultrafast3.ino.txt](https://github.com/Kris-Sekula/EPROM-EMU-NG/files/5698986/v20rc1ultrafast3.ino.txt)

hubertushirsch, 2020-12-16:
Hi
Sorry, yesterday I made a little mistake in the description. The last point has to be:

New remote control sequence :LOADSPI
Loads SRAM from SPI EEPROM and starts emulation
It is the same behavior as short pressing the pushbutton,
but remote controlled.

Ralf

hubertushirsch, 2020-12-23:
Thanks Kris for implementing my ideas in the new v2.0rc3 firmware.

I wish everyone a Merry Christmas.

Ralf

Closed 2020-12-23.

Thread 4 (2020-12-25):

Testing Firmware EPROM_EMU_NG_FW_2.0rc3.ino

hubertushirsch, 2020-12-25:
Thank you for providing the firmware **EPROM_EMU_NG_FW_2.0rc3.ino** for testing.
The firmware works flawlessly in my environment.

I would prefer to switch off the red LED during the long press together with EN_RST=HIGH.
I.e. when the reset signal is activated, the LED goes out and when the button is released it lights up again.

I tried out a few small code changes.
Here is the summary.

//  - remove unused variable 'page_ctn'
//  - move variable 'spi_address' from global scope to function **load_SPIEEPROM()**
//      The variable is only used in this function.
//      The positive side effect: Saves 20ms more in loading SRAM
//  - simplify filling shift registers in **writeMemoryLocation()**, two variables are omitted.
//      No effect on speed.
//  - in long press button move the turn LED off few lines up, so the 150ms is included in LED off time
//      This makes it easier to recognize the triggering of the reset and release the button at the right time

In addition, some comment lines are incorrect in the rxframe evaluation:
:iniAuto0
:iniSPI0

The diff file is attached.

In the Python script **EPROM_NG_v2.0rc3.py**, reference is still made to the old function (turm autoLoad off) for Long Press Button. That can be omitted.

Greetings
Ralf

[v20rc3update1.diff.txt](https://github.com/Kris-Sekula/EPROM-EMU-NG/files/5742359/v20rc3update1.diff.txt)

Kris-Sekula, 2020-12-25:
Thanks for the feedback Ralf.

The LED going OFF during long press was already implemented in rc3 (line
584 and 588) to indicate the "long-press reset" was successful.

I'll integrate the other comments into rc4 when it's out.

Thanks again!

Kris

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

hubertushirsch, 2020-12-25:
Hi Kris,

> The LED going OFF during long press was already implemented in rc3

yes, but I think is better in handling for the operator that the LED already goes out when the reset is initiated.
That was my feeling when trying it out.
So I moved the statement **digitalWrite( LED_G, LOW )** up a few lines.
```
    } else {                             // Button not released after 500ms
      delay(1000);                       // Wait 1s more
      if (digitalRead(LD_BTN) == LOW) {  // Button not released after (500+1000)ms = long press
        // long press resets target
        digitalWrite( LED_G, LOW );      // turn the LED off to indicate the RESET was initiated <== LED turned off
        digitalWrite( EN_RST, HIGH);
        delay(150);
        digitalWrite( EN_RST, LOW );
        Serial.println(F("-> Resetting target via button"));
//        digitalWrite( LED_G, LOW );      // turn the LED off to indicate the RESET was succesful ==> shift this some lines up
        while (digitalRead(LD_BTN) == LOW) {
          delay(100);                    // wait for releasing button
        }
        digitalWrite( LED_G, HIGH );    //
      }
    }

```

Ralf

Kris-Sekula, 2020-12-26:
Ah, ok I see now. No problem, this doesn't make much difference to me, so
I'm happy to follow your recommendation. I'll add this change to rc4 as well

Thanks again :)
Kris

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

Closed 2021-01-25.

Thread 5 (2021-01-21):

Bufferoverflow in Python script

hubertushirsch, 2021-01-21:
Hi Kris,

When uploading a binary ROM image, the 64k limit is not checked.
The script crashes when the file exceeds this limit.

Use case:
128kB image file for a target with 2 * 64kB EPROM (2 * 27512).
It is not a problem to burn the image in two EPROMs with an EPROM burner, as I can specify the start address in the file and the length in the burning software for each burn process.

The emulator is in the socket of the lower ROM.
During the upload, an attempt is made to load the complete file into the buffer, which leads to an overflow.

```
D:\<path>\>EPROM_EMU_NG_SW_Python_v2.1.2.py -mem 27512 -spi n -map y d:\<filepath>\file128k.bin com9
-------------------------
EPROM EMULATOR NG Script version 2.1.2 started - mygeekyhobby.com
Option 'use cache' is set to: disabled
Reading data from: d:\<filepath>\file128k.bin
Traceback (most recent call last):
  File "D:\<path>\EPROM_EMU_NG_SW_Python_v2.1.2.py", line 565, in <module>
    main()
  File "D:\<path>\EPROM_EMU_NG_SW_Python_v2.1.2.py", line 338, in main
    current_data = load_to_buffer(file)
  File "D:\<path>\EPROM_EMU_NG_SW_Python_v2.1.2.py", line 304, in load_to_buffer
    data_64k[x+startaddr] = binfile[x]
IndexError: list assignment index out of range

```
The buffer in the Python script is declared as 64kB.
A test as to whether the loading address (option -start <offset>) + file length is> 64kB should be implemented.
A warning should be issued for files that exceed the 64k limit and the upload should stop automatically when the 64k limit is reached.

On the other hand, it is not possible to plug the (or a second) emulator into the socket of the top ROM and load the top half of the file into the emulator. File offset = 0x10000, Loading address = 0x0000.
For this one would have to be able to specify an offset for the start in the file.

Of course, you can split the image file beforehand using suitable tools. But during a development process this would be an additional step that would have to be repeated after each ASM / compiler run.

Ralf

hubertushirsch, 2021-01-22:
Another aspect:
Suppose I have a 4kB binary file for a target, which is physically equipped with 2 * 2kB EPROM (2716).
The problem of loading only the upper half of the image for the second EPROM into the emulator is as already described.

If I only want to emulate the lower EPROM, 4kB are still loaded into the emulators SRAM and/or SPI, although only 2kB are required for the 2716. The bus is also set to type 2716 so that the third and fourth kilobytes are never addressed.

Should one (this is only to be understood as a discussion) limit the amount of data to be uploaded to the size of the selected EPROM type? Or what is the philosophy behind the current implementation of uploading the complete file?

Ralf

hubertushirsch, 2021-01-23:
Hi Kris

Here is a suggestion from me to limit the file loading process to the ROM size and the 64k address space.
I've only tested it with full images. I have not checked the function when using the cache mode.

Ralf
[EPROM_EMU_NG_SW_Python_v2.1.2update1.diff.txt](https://github.com/Kris-Sekula/EPROM-EMU-NG/files/5860547/EPROM_EMU_NG_SW_Python_v2.1.2update1.diff.txt)

Kris-Sekula, 2021-01-23:
Hi Ralf,

2.1.2 is not public yet, so only the members of the groups.io are experimenting with it, so for now I'm not going to post any fixes here.

The first version of my python control script had those checks baked in, but after I added the hex file support, those checks were a bit trickier to implement. Adding a check for .bin is half of the story, I also need to make sure we do the same checks for .hex.

Regarding the adjustment of the file boundary to support splitting the image across multiple Lower / Higher EPROMs, I'm still not convinced if the emulator script should be responsible for doing that. Of course, we can add this function, but with many corner cases and all sorts of things to consider, I wonder if we should let another program do this job. If you are developing firmware, I'm sure you are not using GUI mode, but have some kind of .bat or .sh or make file, so adding one more command to adjust the files before they go to the EPROM emulator should be easy to do, I use this well-established EPROM load files manipulation program: https://sourceforge.net/projects/srecord/
Even the people behind the commercial Keil compiler recommend it. The program was in development since 2003 ... and it took them almost 10 years to get to a stable state, so I'm worried the moment I add one manipulation use case to my script, there will be another and another, etc.

Thanks again for your helpful contributions and remarks, you've been the biggest and most serious contributor to the firmware / software of the emulator so far. Good job!

Kris

hubertushirsch, 2021-01-23:
Hi Kris,

> 2.1.2 is not public yet,

the changes I sent you, of course, also work in the published version EPROM_NG_v2.0rc3.py.
Since I was only working with the preliminary version recently, I did not think about it when implementing my ideas.

I would definitely recommend the 64k overflow test for binary files. In Intel Hex only 16bit addresses are possible, because this problem does not exist.

Reducing the uploaded bytes to the size of the selected EPROM was an idea in order to save upload time, since the data behind the EPROM size in the SRAM is never addressed. And to prevent unnecessary write operations in the SPI EEPROM.

Selecting individual EPROMs in multi-EPROM images (file offset) was also an idea. Of course you can do a split with external tools. I know **srecord**. I have just implemented the option of specifying a file offset. If there is no interest, I will not go any further.

Ralf

Kris-Sekula, 2021-01-25:
Ralf,

Added your changes to 2.1.rc4 shared on groups.io, checks for data outside of selected memory type are now done for both bin and hex files.

Kris

Closed 2021-01-25.

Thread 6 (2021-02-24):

Adapter for dual 27c256? (For IBM 5140)

prozacgod, 2021-02-24:
So I'm a fairly green electronics hobbyist, and I was wondering if it would be easy to make this work on the IBM 5140's dual socket interface, probably with some form of daughter/adapter board.

I found references to the original roms here, and they're listed as 27c256

http://www.minuszerodegrees.net/rom/rom.htm

I haven't confirmed that, but I assume since there's a dumped rom file there, it's probably accurate.

Any thoughts?

prozacgod, 2021-02-24:
A bit more information

This page:
http://ohlandl.ipv7.net/5140/5140.html

Lists the roms as "SMM6326CBK"

Kris-Sekula, 2021-02-24:
Hi,
I'm not that familiar with the 5140 but when I see two ROM it will either
mean:
1. They used two x 27256 as this was the max size that was cheap enough to
fit the code into - in that case you can just use a single emulator
(utilizing the 64k memory it can emulate) and probably a simple adapter to
get the signals decoded into the right place.
2. they used two chips because they want to get the 16bit data bus. In that
case, you will need two emulators, to give you the 16bit data bus. They
show up on your computer as serial ports and you can control them
individually, we could even modify the control script to manage two
emulators from a single command or something like that.

Hope that helps
Kris

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

prozacgod, 2021-02-24:
Oh, that's a good point about the bus size - I just pulled some of the code into a debugger, and it's looking like it's flat data just on 2 rom files, so that's good.

I'm guessing here, but bear with me - if I need to make this "larger eprom" fit the smaller eprom, I need to tie the CS lines from both sockets through an or gate, into the emulators CS line, and the CS line from the eprom higher in address space into the a15 address line on the emulator?

this ... sounds close?

P.S. - Thanks for such a fast reply!

Kris-Sekula, 2021-02-24:
"I'm guessing here, but bear with me - if I need to make this "larger
eprom" fit the smaller eprom, I need to tie the CS lines from both sockets
through an or gate, into the emulators CS line, and the CS line from the
eprom higher in address space into the a15 address line on the emulator?"

spot on! without the schematic diagram to confirm, I would take the exact
same assumption...CS lines from both sockets via an OR gate (you could use
a two diode OR gate approach instead of an actual OR gate) and A15 from one
of the sockets CS signal ... Depending on implementation they might be
controlling the OE and/or the CS in the 27C256...Try to dig out the actual
schematic diagram so we can confirm the best approach.

Kris

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

Closed 2021-03-02.

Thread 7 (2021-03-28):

23xx support

eh, 2021-03-28:
I was wondering if you would consider adding 23xx support, the difference is only in pinout. This would make it handy to use in things like ZX81/TS1000 without an adapter.

Kris-Sekula, 2021-03-29:
Hi Erik. I have used the emulator with Commodore 64 to emulate the 2364 PROM. You simply can select 2764 memory. On the hardware side, you still need an adapter as 2364 only is a 24 pin device and the emulator is 28pin, there is also a pinout difference, but more importantly, 2364 only has one control signal /CS, but most EPROMs and the emulator requires both /CE and /OE to work. You can buy one of the popular adapters for a Commodore or you can order a PCB from PCB way that I created to cover both the 23xx and the 2716/2732 use-cases with my emulator. See here [https://www.pcbway.com/project/shareproject/2364_to_2764_or_2716_2732_to_2764_27512_adapter.html](url)

eh, 2021-03-29:
I have a dead Timex Sinclair 1000 and I suspect the ROM (I can verify ULA/Z80 functionality) and I have purchased an adapter already, just not gotten around to using it. The thing is, ZX81/TS1000 (and more?) have a DIP28 ROM footprint. Mine is even socketed. As it happens I had just recently purchased your emulator, so I thought I could try that.

To be honest any explanation for why it can't do 23xx is probably lost on me for now, as I'm just getting into this stuff (I picked up your mgh80 kit at the same time). The adapter boards I've seen (including the one I have) just move pins around, and maybe provide A14/A15 for bank selection. There's no magic to provide CE/OE. So I figured just re-assigning some pin locations, similar to what an adapter does but in software, would work. I had a look at your arduino source but don't have the time just now to figure out where EEPROM.h is getting its pin definitions.

I'm probably in over my head and will take your word for it that it can't be done. For what it's worth I've had no issues with either of your kits. They were a joy to assemble and the emulator has come in handy for other projects since I built it. Not waiting on my cheap UV eraser (and then waiting again because it almost never fully erases) has made it very much worth owning.

Kris-Sekula, 2021-03-29:
Erik, I don't have a Timex / ZX81 to try, but I had a look at the board and schematic: [http://www.mainbyte.com/ts1000/drw_board.jpg](url) and it looks like the ROM is a 2364 - and those are 24 pins. Maybe you have a different revision of the PCB with a 28pin footprint.  The "software" trick for re-arranging the Address / Data lines is possible (I use it to support 28C256) but the control signals on the emulator are directly connected to the output buffer (74hc541). For the buffer to open you need both /CE and /OE to be logic low... the ZX81 can supply only one of those control signals the other has to be routed to the ground - most of the adapters for Commodore including my adapter works the same way by re-routing one of the control signals to ground.

I have a ZX Spectrum and for that one, you need to modify the motherboard a bit to support standard EPROMS (including my emulator). Additionally, the way data/address lines are arranged in the spectrum, you may have to remove the pull-up resistor network from the emulator for this to work.

eh, 2021-03-29:
No matter, as I was implying it is a DIP24 2364 (in a DIP28 socket/footprint) and that's what I was hoping to emulate. I've attached a picture of mine, and you can search google images for other examples. It's the norm. 1,2,27,28 are wired to support DIP28 in I suppose Sinclair fashion, whatever was cheapest they could get at the time.

But I have to apologize, I've actually conflated two things here. The fact that the TS1000 has a DIP28 footprint and is wired to support a longer chip is not relevant. I spent a lot of hours on this thing today and it's what I had on my mind. Ignore the DIP28 stuff, sorry about that.

Looking over the pinout I think I have a better understanding, an adapter will tie CE low and bring OE to the CE pad. I guess if you can't make assumptions about these pins in a hypothetical "23xx" mode then it can't be done. I was thinking "arduino pins are mapped to eprom pins" which is wrong and I should have looked at your schematic. It's been a long day of fighting a video gremlin on this board, so again, sorry about all this.

Looking at my picture I've just noticed the RAM also has a DIP28 outline ... at any rate I have an adapter to build.
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

Kris-Sekula, 2021-03-29:
no worries Erik, looks like you got an "issue 3" PCB that has the option to use larger ICs - something I've just learned today. As you discovered, some of this control logic has to be done in hardware, so you will need a small adapter. I'll close the GitHub issue.

Closed 2021-03-29.

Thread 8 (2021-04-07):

Emulating an AT27C256

InPermutation, 2021-04-07:
_Please consider this a draft note-to-self, since I don't have time tonight to write a pull request._

The pinout between an AT27C256 and a 28256 differs in that the EEPROM's A14 is on pin 1, with /WE on pin 27, while the 28256 EPROM has Vdd on pin 1 and A14 on pin 27.

So, since in the EPROM-EMU-NG, pin 1 is A15, and A14 will be held high ("write enable" not asserted), we can write a little Python script to convert a 32K binary file into a 64K file padded with junk in addresses `0000:3FFF` and `8000:c000`:

```python
#!/usr/bin/env python3

import sys

if __name__ == "__main__":
    with open(sys.argv[1], "rb") as infile:
        data = infile.read()
        assert len(data) == 0x8000, f"len must be {0x8000}; was {len(data)}"
    with open(sys.argv[2], "wb") as outfile:
        outfile.write(b'\xff' * 0x4000) # junk
        outfile.write(data[0:0x4000])
        outfile.write(b'\xff' * 0x4000)  # junk
        outfile.write(data[0x4000:0x8000])
```

then write it out like usual:

```
% python3 EPROM_NG_v2.0rc3.py -mem 27512 -spi y -auto y ./a512.out /dev/tty.usbserial-1410 -start 0 -map y
```

I used a TL866 II+ with [`minipro`](https://gitlab.com/DavidGriffith/minipro/) to confirm that this reads correctly as a 27C256:

```
% minipro -p AT28C256 -r a.test
```

And, I attached it in place of the EEPROM of my Ben Eater 6502, and it boots up correctly!

InPermutation, 2021-04-07:
Data writes at about 1.6 kbps, so we can speed this up by not even writing the junk bytes. First optimization: use the `-start 4000` parameter, and remove the first `# junk` line.

Second optimization: write two separate files, write at `-start 4000` and `-start c000`. (todo: check math)

InPermutation, 2021-04-07:
The downside to the second optimization is that RST/ goes high for a fraction of a second between the two runs, which could cause undesired operation of the target computer.

Kris-Sekula, 2021-04-07:
Hey Jacob, great job investigating. I sent you an email, try that if you get a chance and let me know if your BE6502 boots... if it does I'll publish the files for others to try.

Kris-Sekula, 2021-04-11:
The newly released (experimental) version of firmware and software now has EEPROM support included:
Firmware 2.0rc8 (EPROM_EMU_NG_FW_2.0rc8.ino - Arduino sketch in Firmware folder)
Software 2.0rc8 (EPROM_EMU_NG_2.0rc8.py - Python script in Software folder)

InPermutation, 2021-04-11:
The new firmware works great, thanks @Kris-Sekula!

Closed 2021-04-11.

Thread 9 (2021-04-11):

`-spi n` seems broken

InPermutation, 2021-04-11:
I may have spoken too soon on #8 - it stopped working in 28256 mode in my BE6502 when using `-spi n` (`y` works).

Also, the transfer time almost triples when using `-spi n`:

* `-spi n`: `Time taken to transfer: 15.22s`, fails to boot.
* `-spi y`: `Time taken to transfer: 5.27s`, boots fine.

Firmware version: 2.0rc8.

Uploader version: 2.0rc8.

macOS 11.2.3

Python 3.9.2

Kris-Sekula, 2021-04-11:
Send me the bin or hex file you are using to test with, I’ll take a look
later on. I did some basic testing last night and was getting good results,
but I relay on reports like yours to iron out the last glitches :)

On Sun, Apr 11, 2021 at 1:32 PM Jacob Krall ***@***.***>
wrote:

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

Kris-Sekula, 2021-04-11:
Also, can you please paste the output of the console for the failed upload
(with spi -n)

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

InPermutation, 2021-04-11:
```
python3 /Users/jacob/EPROM-EMU-NG/Software/EPROM_EMU_NG_2.0rc8.py -mem 28256 -spi n -auto n a.out /dev/tty.usbserial-1410

Running EPROM EMU NG python script version 2.0rc8

File used: a.out

Done processing bin

Memory map disabled

Using serial port /dev/tty.usbserial-1410, emulating: 28256 EPROM

<- attempting to get sync
-> HW: v2.1, FW: 2.0rc7, SPI: 1, Auto: 0, Last EPROM: 28256, mygeekyhobby.com 2020 :)

<- Setting "Save to SPI EEPROM" option to disable
-> SPI save OFF

<- Setting "Auto load from SPI EEPROM" option to disable
-> Auto Load OFF

<- processing file

0xB800 >

Time taken to transfer: 15.2s

<- Setting EPROM Type

<- Enable Emulation
-> Emulator Running.

Success, Finished.
```

----

[a.out.zip](https://github.com/Kris-Sekula/EPROM-EMU-NG/files/6293008/a.out.zip)

InPermutation, 2021-04-12:
It's macOS 11.2.3

InPermutation, 2021-04-12:
For comparison, the output with `-spi y`
```
python3 /Users/jacob/EPROM-EMU-NG/Software/EPROM_EMU_NG_2.0rc8.py -mem 28256 -spi y -auto n a.out /dev/tty.usbserial-1410

Running EPROM EMU NG python script version 2.0rc8

File used: a.out

Done processing bin

Memory map disabled

Using serial port /dev/tty.usbserial-1410, emulating: 28256 EPROM

<- attempting to get sync
-> HW: v2.1, FW: 2.0rc7, SPI: 0, Auto: 0, Last EPROM: 28256, mygeekyhobby.com 2020 :)

<- Setting "Save to SPI EEPROM" option to enable
-> SPI save ON

<- Setting "Auto load from SPI EEPROM" option to disable
-> Auto Load OFF

<- processing file

0xBE00 ACK

Time taken to transfer: 5.26s

<- Setting EPROM Type
-> Bus set to 28256 EEPROM Memory

<- Enable Emulation
-> Emulator Running.

Success, Finished.
```

Kris-Sekula, 2021-04-12:
I did some testing on my raspberry pi and got the following results:

with "spi -n":

Using serial port /dev/ttyUSB0, emulating: 28256 EPROM

<- attempting to get sync
-> HW: v2.1, FW: 2.0rc8, SPI: 0, Auto: 0, Last EPROM: 2764, mygeekyhobby.com
2020 :)

<- Setting "Save to SPI EEPROM" option to disable
-> SPI save OFF

<- processing file

0xB800 >

Time taken to transfer: 2.97s

<- Setting EPROM Type
-> Bus set to 28256 EEPROM Memory

<- Enable Emulation
-> Emulator Running.

with "spi -y":

Using serial port /dev/ttyUSB0, emulating: 28256 EPROM

<- attempting to get sync
-> HW: v2.1, FW: 2.0rc8, SPI: 0, Auto: 0, Last EPROM: 2764, mygeekyhobby.com
2020 :)

<- Setting "Save to SPI EEPROM" option to enable
-> SPI save ON

<- processing file

0xBE00 ACK

Time taken to transfer: 5.0s

<- Setting EPROM Type
-> Bus set to 28256 EEPROM Memory

<- Enable Emulation
-> Emulator Running.

For the "spi -n" I'm using a new method of transfer (bypassing local buffer
in the Arduino) this "saves" about 0.9s transfer time for the 32kb
filesize...

But looks like there is a difference in behavior for macOS, I'm going to
have to "investigate" ... but first need to dig out my macOS machine :)

In the meantime you can either revert to one of the older versions of
firmware/software or do the following changes to the python script:

Around line 102 add the "buffer_size = 512"

[image: image.png]

And around line 500 add the "data_tx = (":SBN\r\n").encode()

[image: image.png]

This will revert the transfer method for "spi -n" back to "buffered" mode.

Kris

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

InPermutation, 2021-04-12:
I added some debug help to my firmware and programmer script. If the firmware receives a command it doesn't recognize, I added
```c++
      Serial.print(rxFrame);
      Serial.println(" not recognized.");
```
to the bottom of `loop()`.

Then, I added some `print` debugging to the script:

```diff
--- a/Software/EPROM_EMU_NG_2.0rc8.py
+++ b/Software/EPROM_EMU_NG_2.0rc8.py
@@ -521,9 +521,9 @@ try:

                # send to emulator
                ser.write(buff64k[StartAddr:StartAddr+FrameSize])
-               response = ser.readline()
+               response = b" === " + response + b" --- " + ser.readline()^M

-               print("0x%0.4X"%StartAddr,response.decode().strip(), end='\r', flush=True)
+               print("0x%0.4X"%StartAddr,response.decode().strip(),  flush=True)^M

        taken = time.time() - start
```

Successful output:

```
…
<- processing file

0x0000 === ->in
 --- ACK
0x0200 === ->in
 --- ACK
0x0400 === ->in
 --- ACK
0x0600 === ->in
 --- ACK
0x0800 === ->in
 --- ACK
0x0A00 === ->in
 --- ACK
0x0C00 === ->in
 --- ACK
…
```
Unsuccessful:
```
<- processing file

0x0000 === >
 ---
0x0800 ===  --- >
0x1000 === :DIR not recognized.
 --- 4096 not recognized.
0x1800 === 2048 not recognized.
 ---  not recognized.
0x2000 === 6144 not recognized.
 --- 2048 not recognized.
0x2800 === :DIR not recognized.
 --- 8192 not recognized.
0x3000 === 2048 not recognized.
 --- :DIR not recognized.
0x3800 === 10240 not recognized.
 --- 2048 not recognized.
0x8000 === :DIR not recognized.
 --- 12288 not recognized.
0x8800 === 2048 not recognized.
 --- :DIR not recognized.
0x9000 === 14336 not recognized.
 --- 2048 not recognized.
0x9800 === :DIR not recognized.
 --- 32768 not recognized.
0xA000 === 2048 not recognized.
 --- :DIR not recognized.
0xA800 === 34816 not recognized.
 --- 2048 not recognized.
0xB000 === :DIR not recognized.
 --- 36864 not recognized.
0xB800 === 2048 not recognized.
 --- :DIR not recognized.

Time taken to transfer: 2.07s
```

So, there's something weird going on with that `:DIR` command, and _only_ that `:DIR` command…?

Will keep digging.

Kris-Sekula, 2021-04-12:
ok, great. You don't happen to have a windows or raspberry pi machine
kicking around to try? I want to eliminate the OS from the equation... I'll
try on macOS once I get my old laptop out.

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

InPermutation, 2021-04-12:
Still on macOS, will try from a Raspberry Pi next :)

I added functionality to the firmware to print `.length()` and iterate over the bytes of the `rxFrame` and found a whole lot of leading `NULL` bytes:

```<- processing file
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
Kris-Sekula, 2021-04-12:
interesting, do you see those trailing zeros on successful transfer with
spi -y ?

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

InPermutation, 2021-04-12:
nope, it recognizes the `:SBN` command just fine

InPermutation, 2021-04-12:
It works just fine on my Raspberry Pi Zero, by the way.

```
~ $ lsb_release -a
No LSB modules are available.
Distributor ID:	Raspbian
Description:	Raspbian GNU/Linux 9.13 (stretch)
Release:	9.13
Codename:	stretch
~ $ python3 --version
Python 3.5.3
```

(I did have to comment out all of the `PySimpleGui` code, because of that really old system version of `python3`)

InPermutation, 2021-04-12:
I tried using `/dev/cu.usbserial-*` instead of `/dev/tty.usbserial-*`, per [this Stack Overflow question](https://stackoverflow.com/q/37688257/3140), but saw no difference.

Also, I realized the "slow" send speed of the defect is because `ser.readline()` is timing out on each block after 0.5 seconds of inactivity 😄

Kris-Sekula, 2021-04-12:
I just tested on macOS as well and it is also broken when I try.

looks like some kind of macOS related issue probably with the pyserial, I
checked with the scope and at some point, I see data stops coming from the
serial port into the Arduino.

lowering the size of the chunk of data that gets sent to the serial port
via the script down to 1024 "fixes" the issue for me (adjust the
buffer_size from 2048 to 1024)

[image: image.png]

Kris

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

Kris-Sekula, 2021-04-12:
Jacob,
I published rc9 files, changed the transfer size from 2048 to 1024...If I ever figure out how to properly fix it on macOS we can revert to 2048 or even larger but for now to have macOS support working let's stick to 1024.
Let me know if you get a chance to test it.
Kris

P.S. yep, the 15s was the timeout on each block (todo: proper flow control, and timeout handling, for example, the script should have been able to tell you it was not getting the confirmations from the emulator etc. )

InPermutation, 2021-04-13:
rc9 fixes this issue on my Mac 👍

InPermutation, 2021-04-24:
I had a similar problem with another project, also based on the Arduino Nano clone board, which uses the CH340 chip for USB serial communications.

My latest hunch: macOS’ built-in `com.apple.DriverKit-AppleUSBCHCOM` kext has broken flow control.

Kris-Sekula, 2021-04-24:
Thanks for the info Jacob! Not entirely surprised based on the "quality" of
the driver for those CH340 chips on macOS. It is interesting that the
program "upload" via Arduino doesn't suffer the same issue.

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

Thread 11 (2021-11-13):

Incorrect handling for EPROM type 28C64 in rc9 / rc10

hubertushirsch, 2021-11-13:
There is a fatal bug in firmware 2.0rc9 and rc10 (Files EPROM_EMU_NG_FW_2.0rc9.ino and EPROM_EMU_NG_FWrc10.ino).

The (E)Eprom type with the highest ID is the 28C64 (mem_cfg=8).

If you set this type permanently (:iniE64), the next time you start the emulator in setup () the deafult type 27512 (mem_cfg=6) is set again because the following program section is faulty:
<b>
  //
  // get "last used EPROM" config from SPI_EEPROM
  //
  if ((EEPROM.read(mem_cfg) > 7) || (EEPROM.read(mem_cfg) < 1)) {
    EEPROM.write(mem_cfg,6);  // set default to 27512
    Serial.println(F("Setting default EPROM Memory to 27512"));
  }
  else {
    lastEPROM = EEPROM.read(mem_cfg) ;
    Serial.println(String("Config: Last EPROM used is ") + memTable[lastEPROM]);
  }
</b>
The <code>if statement</code> must be like this:
<b>
  if ((EEPROM.read(mem_cfg) > 8) || (EEPROM.read(mem_cfg) < 1)) {
</b>
If this error is corrected, access to memTable[] will fail because there is no index 8 there:
<b>
const char* memTable[8] = {"27xx","2716","2732","2764","27128","27256","27512","28256"}; // lookup table for memory type
</b>
The table must contain an element for index 8:
<b>
const char* memTable[8] = {"27xx","2716","2732","2764","27128","27256","27512","28256","28C64)}; // lookup table for memory type
</b>
Greetings
Ralf aka Hubert

Kris-Sekula, 2021-11-13:
Confirmed, this is definitely "self inflicted" bug :) Thank you for finding it and sharing the details, as always you are a pro Ralf! I'll get the code updated tonight.

hubertushirsch, 2021-11-13:
For more clarity I have named the EPROM IDs symbolically and use the names instead of numbers in all places.
<b>
enum {noROM, rom2kB, rom4kB, rom8kB, rom16kB, rom32kB, rom64kB, romE32kB, romE8kB, lastType};
</b>
Same order as the names in memTable[]. This will make the code
<b>
//
// get "last used EPROM" config from SPI_EEPROM
//
if ((EEPROM.read(mem_cfg) >= lastType) || (EEPROM.read(mem_cfg) < rom2kB)) {
EEPROM.write(mem_cfg, rom64kB); // set default to 27512
Serial.println(F("Setting default EPROM Memory to 27512"));
}
else {
lastEPROM = EEPROM.read(mem_cfg) ;
Serial.println(String("Config: Last EPROM used is ") + memTable[lastEPROM]);
}
</b>
or elsewhere
<b>
  switch (eprom) {
    case rom2kB:
      digitalWrite( EN_A11, LOW );
      digitalWrite( EN_A12, LOW );
      digitalWrite( EN_A13, LOW );
      digitalWrite( EN_A14, LOW );
      digitalWrite( EN_A15, LOW );
      break;
    case rom4kB:
      digitalWrite( EN_A11, HIGH );
      digitalWrite( EN_A12, LOW );
      digitalWrite( EN_A13, LOW );
      digitalWrite( EN_A14, LOW );
      digitalWrite( EN_A15, LOW );
      break;
    case rom8kB:
    case romE8kB:
      digitalWrite( EN_A11, HIGH );
      digitalWrite( EN_A12, HIGH );
      digitalWrite( EN_A13, LOW );
      digitalWrite( EN_A14, LOW );
      digitalWrite( EN_A15, LOW );
      break;
    case rom16kB:
      digitalWrite( EN_A11, HIGH );
      digitalWrite( EN_A12, HIGH );
      digitalWrite( EN_A13, HIGH );
      digitalWrite( EN_A14, LOW );
      digitalWrite( EN_A15, LOW );
      break;
    case rom32kB:
.......
</b>
Ralf

Kris-Sekula, 2021-11-13:
Thanks Ralf, if you don't mind please attach your version of the file here
and I'll update the repository.

Kris

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

hubertushirsch, 2021-11-14:
Hi Kris,

I have corrected the code of the original rc9 file. The temporary name is v20rc9-fix1.
You have to adapt the file name and the internal version string to your naming scheme.
The complete file and a diff file are included.

[v20rc9-fix1.ino.txt](https://github.com/Kris-Sekula/EPROM-EMU-NG/files/7534162/v20rc9-fix1.ino.txt)
[v20rc9-fix1.diff.txt](https://github.com/Kris-Sekula/EPROM-EMU-NG/files/7534160/v20rc9-fix1.diff.txt)

Regards
Ralf

Kris-Sekula, 2021-11-15:
Thank you Ralf, I used your version of the file (after adding what was in rc10) and published it as rc11. Thanks again for taking the time to report and for sharing your code!

Closed 2021-11-15.

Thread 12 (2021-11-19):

Higher serial speed don't work in :DIR mode

hubertushirsch, 2021-11-19:
High Kris,

I had previously done tests with higher serial data rates and discussed them on groups.io.
I had successfully tested the FW/SW (rc3/rc3) with 115200 (default), 250000, 500000 and 1000000bit/s.
Higher speeds lead to shorter transmission times.
This no longer works in the current rc11 firmware/rc9 software.
When transferring with the old method (spi=yes => :SBN) it works as before.
With SRAM only mode (spi=no => :DIR), the transmission time is shortened when increasing from 115200 to 250000bit/s as expected.
At 500000 and 1000000bit/s it now takes 64s.

I haven't investigated the problem yet.
I suspect it is due to the serial receiving algorithm in the firmware (buffer problem?).
At first glance, the send routine in the Python script is identical except for the start command (:SBN vs. :DIR)

Thus, even with "SRAM only" (spi=no), a higher transmission rate would have a better effect than different algorithms for spi=no and spi=yes.

Ralf

Kris-Sekula, 2021-11-20:
Hey Ralf

Yeah, that is intentional, unfortunately. I was having issues with a few of the Nano boards with CH340 running at 1000000bit/s, so by default, I didn't push the code to run at that speed. But I still wanted to make the transfer faster so I optimize the code based on the 115200 speed by writing directly to SRAM instead of buffering the data on the Nano. This gave me a boost, I think I "shaved" 1-2 sec in comparison to going via the buffer. This works well but only at 115200, if you go faster the Nano doesn't have time to complete the write to SRAM before another byte arrives from the computer. Attached is a modified Python code that brings back the :SBN for all transfers, and will run at  1000000bit/s, don't forget to adjust the speed in the Arduino code as well.
[EPROM_EMU_NG_2.0rc9b.py.txt](https://github.com/Kris-Sekula/EPROM-EMU-NG/files/7574060/EPROM_EMU_NG_2.0rc9b.py.txt)

hubertushirsch, 2021-11-20:
Hi Kris,

thanks for the answer.

115200 bit/s is not a law. It's just a limitation in the Arduino IDE's serial monitor.
Nobody restricts the transfer of data between two systems as quickly as the technical possibilities of the systems allow.

I have made measurements in all combinations, always with FW rc11 and SW rc9(b).
A 27512 EPROM with 80% real code and 20% 0xff is transmitted in each case.
Based on these measurements, everyone can decide which mode they prefer.

115200 :SBN  7,47s
115200 :DIR  6,05s (saved 1,42s compared to 115200 :SBN)

250000 :SBN  4,27s (saved 3,2s to 115200 :SBN or 1,78s to 115200 :DIR)
250000 :DIR  2,94s

500000 :SBN  2,92s (saved 4,55s to 115200 :SBN or 3,13s to 115200 :DIR)
500000 :DIR  >60s

1000000 :SBN  2,31s (saved 5,16s to 115200 :SBN or 3,74s to 115200 :DIR)
1000000 :DIR  >60s

You see, with the same transfer rate :DIR is faster than :SBN, but :DIR does not work at higher transfer rates.
But :SBN at 250000 bit/s is already significantly faster than :DIR at 115200 bit/s.
If your goal is to save time, :SBN with a higher transmission rate is the more efficient solution.

Ralf

Kris-Sekula, 2021-11-20:
Hey Ralf,

I don't dispute that faster transfer is better :) 100% with you on that.
The limitation is not Arduino IDE / or Arduino serial monitor. The only
reason I was sticking to 115200 was that a few of the Arduino Nano clone
modules that I used that came from China had a ch340 chip onboard and
although the chip is supposed to support higher speeds, out of 40 modules
that I used, 2-3 of them were failing to communicate at speeds over 115200,
hence I decided not to go over that speed.

Even at 115200 I was trying to find a way to speed up the transfer, and
assuming I only want to run at 115200, one way of speeding things up was to
stop buffering the data once it arrives in the emulator and send it
directly to the SRAM.

I encourage anyone who wants to get faster transfer time to use faster
speeds, but by default I ship the software and firmware configured at
115200 so that I know for sure it will work with any of my Nano modules out
there.

This is the beauty of "open source", you got the power to make a change
based on your needs :)

So as a conclusion, I feel we are both "correct", but thanks for pointing
out and reminding everyone that running the emulator at higher speeds is
possible and will give shorter transfer times.

Kris

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

hubertushirsch, 2021-11-20:
Hi Kris,

I now understand why you only want to use 115200.
I also only use Clones and have not made any negative experiences. You have already experienced problems, so I understand your point of view.

greeting
Ralf

Closed 2021-11-20.

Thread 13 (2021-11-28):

Possible to support 24C64WP SOP 8 64-Kbit serial I2C bus EEPROM?

ArcadeHustle, 2021-11-28:
[m24c64wp.pdf](https://github.com/Kris-Sekula/EPROM-EMU-NG/files/7612754/m24c64wp.pdf)

Kris-Sekula, 2021-11-28:
hmm... you need to be more specific, 24C64WP as a Target memory or as a
replacement of the 25LC512 SPI EEPROM?

Kris

On Sat, 27 Nov 2021 at 19:31, Hustle Arcade ***@***.***>
wrote:

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

ArcadeHustle, 2021-11-28:
As a target memory for mem_type: https://github.com/Kris-Sekula/EPROM-EMU-NG/blob/master/Software/EPROM_NG_v2.0rc3.py#L290

Kris-Sekula, 2021-11-28:
nope unfortunately the emulator works with a "parallel" memory bus, the
24C64WP is I2c, different hardware configuration would be required... but
would not be too complex to implement, what is the use-case?

On Sat, 27 Nov 2021 at 19:45, Hustle Arcade ***@***.***>
wrote:

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

ArcadeHustle, 2021-11-28:
A large number of devices make use of small i2c flash memories, including video game saves, and toys like Tomogatchi Digimon use them for character settings, or game firmware.

This will enable reverse engineering of an entire class of devices that is not supported now. For example sprite swapping with Digimon could be very easy with your tool supporting this style of chip.
https://twitter.com/rayjt9/status/1371553018496352266
https://twitter.com/BRV64/status/1352826675344461824

Thanks for your input.

ArcadeHustle, 2021-11-28:
BIOS's may often store settings in an EEPROM of this type as well. Sega RingEdge arcade system is one such system that stores Intel Management Engine on an i2c flash chip for example. Laptop passwords for administrative features can also live in these sort of EEPROMs.
https://hackaday.com/2021/03/24/removing-supervisor-passwords-and-learning-python/

cheers!

Kris-Sekula, 2021-12-13:
The EEPROM I2C bus is a "shared" bus, so in most cases, you can plug a simple I2C programmer (or an Arduino with a bit of code) and re-program the EEPROM. It really makes more sense to do it with a different device.

ArcadeHustle, 2021-12-13:
"and re-program the EEPROM" reprogramming isn't the issue. Real time watching of the changes would be nice. Thanks for your consideration. Will have to search elsewhere for the solution.

Closed 2021-12-13.

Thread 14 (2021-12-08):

KiCad sources missing from 2.2c

StormTrooper, 2021-12-08:
The KiCad source files are missing from the 2.2c folder.

I only see them in 2.2 and earlier.

Kris-Sekula, 2021-12-13:
Sorry I missed those... not much has changed, only a few part designators. Added the sources.

Closed 2021-12-13.

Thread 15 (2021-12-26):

Support for Nano modules based on ATMEGA328PB

Kris-Sekula, 2021-12-26:
I recently bought a batch of Nano modules based on the newer ATMEGA328PB microcontroller without even realizing it. Although the microcontroller is practically backward compatible with the ATMEGA328P, I experienced issues when using the EPROM Emulator with those modules, for example, the upload of the binary image was failing randomly, this would look like a successful upload is happening, the red LED would be lit up for a short moment and then would go off. When monitoring with a logic analyzer I was seeing that the microcontroller gets reset at the end of the upload when the python script disconnects. This was "unexplained". As per this repo: https://github.com/watterott/ATmega328PB-Testing the reset level for the PB version is: 1.6V @ Vcc=5 and 2.1V @ Vcc=5V  for the P version... this leads me to believe that the reset control is the problem. To confirm I removed the 100nF capacitor between the DTR line on the CH340 and the ATMEGA328PB Reset line. This fixed the issue. See the picture of the modified board:

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

Not sure how to deal with this further, my workaround for the batch of Nano modules will be to remove the 100nF capacitor and ask users to press the "reset" button during firmware upload (not a big deal as this is not often required).

Removing the 100nF capacitor also means that when the python program connects to the emulator it doesn't automatically reset the emulator - this is a good thing, but this also exposed a small bug in the original firmware where the address bus was not fully set before data was re-uploaded via the serial connection. This bug is now fixed and updated firmware has been added to the repository.

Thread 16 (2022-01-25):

Trace feature

AMT-Cheif, 2022-01-25:
do you think is it possible to implement trace feature in your fw without lose to much performance?
with trace I mean see in real time which address/data is access from the circuit where the emulator is mounted.

Kris-Sekula, 2022-01-26:
Unfortunately, it's not possible with the current hardware design.

AMT-Cheif, 2022-01-26:
do you have any suggestion to start a new desgn?

Closed 2022-01-26.

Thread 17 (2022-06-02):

DIP28 PROBE Components

AMT-Cheif, 2022-06-02:
I'm trying to find dhe component to build the probe, but I can't find anywhere the dip28 header. the link to digikey you posted on your website not work anymore. Can you help me to find the header?

Kris-Sekula, 2022-06-03:
The BOM is on GitHub (https://github.com/Kris-Sekula/EPROM-EMU-NG/blob/master/Hardware/2.2c/EpromEmu_2_2c_BoM_DigiKey.xlsx) the part number you are looking for is the: FDP-628-T (that is DigiKey pn: 2057-FDP-628-T-ND) ... The BoM link on my page is still correct, but since one of the parts is out of production you just have to mark it to be deleted and the list of parts will load up on DigiKey ... I'll update the list this week,  but with the current components shortage, it can be challenging to secure everything.

Closed 2022-06-03.

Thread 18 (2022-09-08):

Next time, support 32 pin devices...

mdhampton, 2022-09-08:
It would make things easier for larger roms (like bios for old PC's made from new(ish) parts (EMM 8088, etc). And you could replace the two RAM chips with a single 512kx8 ram. If I ever have time, I may fork this and attempt it, but I have lots on my plate already...

Kris-Sekula, 2022-09-10:
Good suggestion, there are other ways this project could be improved, but by the time those adjustments are done it may make it way too complicated and  a completely new approach is probably needed - cpld/rp2040 etc.

Closed 2022-09-10.

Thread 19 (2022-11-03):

HEX Format Needs to Honor the -start Command Line Argument

frenchie68, 2022-11-03:
Currently, the -start argument is only taken into account when processing non-HEX input files.

Kris-Sekula, 2022-11-04:
Hey Francois, thanks for the suggestion. I don't really have plans to support the "-start" flag for hex files. Hex file records format includes the address portion so it can be used to locate the code correctly in the EPROM address space. You can set the compiler to "locate" the code correctly in the address space (for example by using the .TA directive in SBAssembler https://sbprojects.net/sbasm/directives.php?directive=ta).  Even if I was to support that flag, it would have to be called "offset" as a hex file can have multiple sections that are located in different areas of address space, so applying the same "start" parameter wouldn't work.

The other reason I don't want to add too many options into the main python code is that I don't believe those functions should be part of it - the code will end up bloated once I try to support more and more file formats and options etc. I normally suggest to use another tool to "manipulate" the data before it's sent to the the emulator... for example "SRecord" is an open source tool that has been designed to manipulate EPROM load files, it has been developed for over 10 years, even professional complers like Keil recommend using it.... you can make SRecord part of you compiler toolchain.

frenchie68, 2022-11-04:
Hi Kris. The least I can say is I do not understand your reluctance about this proposal. We have seen offline, that (naive) support for this can be limited to two lines of code changes, and no new option needs to be introduced. Yes, an HEX file can have multiple sections, but the -start option could be used to filter out anything that is not meant to reside in the target device.

Kris-Sekula, 2022-11-04:
Francois, since the change you are proposing is small enough we can probably accommodate it in the official script. If you have a version of the code with the changes implemented, working and tested please share it with me and I'll officially add it here (and will include you in the credits).

Just to be clear, the reason I'm reluctant to introduce any more file "manipulation" option is that I don't want the emulator script to become a tool for file manipulation. It took the team behind SRecord 10 years to make everyone happy, so I don't want to "reinvent the wheel" by introducing functionality that is already included in the compiler or tools like SRecord...

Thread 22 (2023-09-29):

kicad source

interbiznw, 2023-09-29:
hey do you have the kicad sources for 2.2d? the 2.2.c ones are there, just wondering on the 2.2d

thanks!

Kris-Sekula, 2023-10-10:
Added, sorry for the delay, I was traveling and didn't have access to the files.

Closed 2023-10-10.

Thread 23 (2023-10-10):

assembled devices

interbiznw, 2023-10-10:
I didn't see any assembled devices or bare boards anywhere so I had some boards made, and bought parts to assemble them

I have some if  anyone needs.. I can get you bare board, or fully assembled/programmed ready to go units>>https://store.interbiznw.com/

Kris-Sekula, 2023-10-10:
I also offer them via eBay, https://www.ebay.com/itm/174408084902

Kris-Sekula, 2023-10-10:
due to my travel, my ebay store listing are not showing as I have "away"
enabled. The listings will show up starting tomorrow.

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

Kris-Sekula, 2023-10-10:
I bought last batch from DigiKey, I see they are out of stock currently but
I'm those will be re-stocked at some point - it's a standard item that they
normally offer. Their website says TC74HC541APF-ND will be back in stock in
November

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

Kris-Sekula, 2023-10-10:
I now recommend populating RN3, without it the inputs of address lines are
floating and this can sometimes cause issues with U6 going into "CMOS
latchup" (heats up and fails)

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

Closed 2023-10-10.

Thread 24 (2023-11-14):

HW Version 2.2d - June 2022 issues with TLY-3100-28P and silk screen

pocoaust, 2023-11-14:
G'day,
I made this version, and ordered 10x  28 pin TLY-3100 -28P.  I assemble the unit, but cannot get the Probe to work.  I installed the 40 Pin header in position 1 and 2 as per silk screen, but the signals are all over the place.  When I probed them, they are not in the correct order for the TLY plug.  Also, the IC numbers are different on the top and bottom of the silk screen, so which is actually correct.
Thanks
Paul

Kris-Sekula, 2023-11-14:
Hey Paul,

Sorry to hear you're having issues with the probes. These days I'm only
using the TLY-3100-28P, so this is a confirmed working solution. As long as
you solder the connector to position 1,2 you should be fine. It's likely
somewhere with the cable assembly you're having issues.
Have you seen my assembly video?
https://youtu.be/pb_EF_JVYxc?si=U0fAcKkOXZdQ7scs&t=810
There are also some details here:
https://github.com/Kris-Sekula/EPROM-EMU-NG/blob/master/Probe_Design.pdf

Both links show the other type of probe, but in general the instructions
are identical ... one difference will the the reset hooks, when using
position 1-2, the "active low" reset will come out on the first wire of the
ribbon cable (usually the only red wire) and the "active high" will be 2nd
wire.

Btw, If you send a picture of your assembled cable I may be able to tell
you if it's correct.

Kris

P.S> Agree, the IC markings on the PCB are incorrect for the output
buffers, the markings on top layer are fine, the ones on bottom layer are
incorrect.

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

pocoaust, 2023-11-14:
Hi mate,

Thanks for the quick response.  It was my mistake.  My probes were fine,
but it turns out 2 of the 10 541 IC's I brought are faulty from new.  I
made another cable and it was the same as the old ones, so I checked all
the IC's and found one Bad 541, went to replace it but decided to test
before, and also found the replacement was faulty....

I think I may have reversed the cable (i just had pin headers with no
key) when i couldn't get unit to work, and thats why when i traced the
signals it appeared wrong. (Sorry, my mistake)

Thanks again for your help, and great work on this project.

Paul

------ Original Message ------
From "Kris Sekula" ***@***.***>
To "Kris-Sekula/EPROM-EMU-NG" ***@***.***>
Cc "pocoaust" ***@***.***>; "Author" ***@***.***>
Date 14/11/2023 7:02:30 PM
Subject Re: [Kris-Sekula/EPROM-EMU-NG] HW Version 2.2d - June 2022
issues with TLY-3100-28P and silk screen (Issue #24)

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

pocoaust, 2023-11-14:
Okay story thickens....
I got working with 28pin no issue, but when i tried to use the 24 pin
adaptor, no go.

i have placed the 40 pin IDC in position 1/2 as per instructions on
board.  When i buzzed the VCC line, with this setup, the VCC is now on
Pin 8, no pin 7 as in the Probe Diagram.  I then wired pin 8 to pin 24
VCC after removing the A13 line which is shown still connected on the
Probe Diagram. This now goes to the fuse directly.

I then wired pin 11, now A7 to Pin one on the Socket.

It now works.

So, is this because the IDE connector needs to be in 2/3?  Underneath?
or am I just going mad.

I suspect that the issue is the diagram was done for a previous version
and this version reverses the sides the pins are on when you install the
IDC in 2/3 position maybe?

Also, this may mean the reset signal are reversed as well......

This is why I was getting the odd readings for signals originally... ;-)

Any ideas?
Paul

------ Original Message ------
From "Paul O'Connor" ***@***.***>
To "Kris-Sekula/EPROM-EMU-NG"
***@***.***>
Date 15/11/2023 6:51:23 AM
Subject Re[2]: [Kris-Sekula/EPROM-EMU-NG] HW Version 2.2d - June 2022
issues with TLY-3100-28P and silk screen (Issue #24)

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

Kris-Sekula, 2023-11-14:
Paul,
Sorry some of the instructions are out of date... when the probe cable
diagram was created, I was only using the ADAMTech FDP-628 "DIP Probe" (or
FDP-624 for 24 pin)... later I found the TLY-3100-28P but this one has all
connections "mirrored" .. and there is no 24 pin equivalent. The solution
was to add the second row of pins and give users the choice to solder 1-2
for the TLY probe or 2-3 for the FDP probe.

You mentioned you managed to successfully get the 28 pin probe working with
TLY-3100-28P ... but when building the 24 pin cable what type of DIP probe
are you using? You can't mix TLY and FDP on the same PCB ...

When emulating 24 pin devices (2716/2732) you can use the same 28 pin
cable, but plug it to your target the way that the top 4 pins are hanging
outside the 24pin dip socket ... and it will work.

Kris

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

pocoaust, 2023-11-15:
Hi mate, thats the answer....

I use the TLY-3100-28P and I cut off the last 4 pins and plastic weld
the end....  Thats why it didn't work.  I ended up with off set 24 Pin.

So can I suggest you add the  FDP 24 pin part number to the probe pdf
and a caution not to note to say you must use the same with the FDP on
the 28 pin Probe if you wish to use both.

The work around is as I described to get it working ;-)

Thanks again for your help.

Paul

------ Original Message ------
From "Kris Sekula" ***@***.***>
To "Kris-Sekula/EPROM-EMU-NG" ***@***.***>
Cc "pocoaust" ***@***.***>; "Author" ***@***.***>
Date 15/11/2023 9:26:44 AM
Subject Re: [Kris-Sekula/EPROM-EMU-NG] HW Version 2.2d - June 2022
issues with TLY-3100-28P and silk screen (Issue #24)

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

Kris-Sekula, 2023-11-15:
I updated the pdf. Thanks for your patience and for reporting the documentation issues.

pocoaust, 2023-11-15:
Thanks for you work.  I,can't get the unit to work in the real world, but I
am using a bat84 instead of the bat 48 which I will get tomorrow.
Hopefully that fixes the remaining issue.

Thanks again for your help.

Take care.

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

pocoaust, 2023-11-16:
Finally bit the bullet and ordered the correct sockets 28 and 24 pin.  Will
make another board with plug on alternates position.

Take care
Paul

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

Closed 2023-11-15.

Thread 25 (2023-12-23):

2716

smdjeff, 2023-12-23:
24 pin devices like the 2716 and 2732 are supported by keeping the top 4 pins of the 28pin emulator probe unplugged. The power must be provided by the USB cable.

Kris-Sekula, 2023-12-24:
Another option is to use this adapter - it was specifically designed to work with the emulator. https://www.pcbway.com/project/shareproject/2364_to_2764_or_2716_2732_to_2764_27512_adapter.html

Closed 2023-12-24.

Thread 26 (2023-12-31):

Cannot get FDP type probes to work with V2.2d board

pocoaust, 2023-12-31:
Kris,

I got the new FDP-624-T 24 pin and 28 pin from DIGIkey.   I remade a new board and put the header into row 2/3 of Ver 2.2d board.  If I run it on pc I can program and then read the emulator in TL866Pro, but as soon as I put either the 28Pin into a Amstrad CPC (27256), or the 24 pin into a TEC one-a (2716), the U6 starts to heat up and it does not work.

The 28 Pin worked in the previous board i made with the same Amstrad but with with the TLY probe and Header connector in Position 1/2

When i buzz the pins from the FDP out, they appear correct according to the Schematic.  I have tried with the RN2 installed and removed, same issue.

Any ideas?

pocoaust, 2023-12-31:
MY main need is to support 2716 in emulation.

Kris-Sekula, 2023-12-31:
Just to confirm a few facts:

1. You currently have two emulators, one assembled to use the TLY probe and
one assembled to use the FDP(both 24 and 28) pin probes?
2. The TLY 28 pin based emulator works fine with your Amstrad CPC (as
27256)?
3. The new unit assembled to support the FDP probe, you are currently
experiencing issues with U6 heating up.

I've seen U6 getting hot if RN2 is left unpopulated, so make sure RN2 and
RN3 are in at all times - those lead to address bus inputs and you just
don't want to leave inputs floating.

If you've not noticed the U6 getting hot before installing RN2, it's
possible that U6 is now broken - I would suggest swapping it - or as a
minimum test it with your TL866 to confirm that it "survived" the heat of
CMOS latchup.

Are you able to "read" the 24pin probe via the TL866?

Try the following order of power sequence:

When powering up the emulator:
1. With both the emulator and your target system (the one you plug your
emulator into) powered off, install the emulator probe.
2. Power up your target
3. plug the usb cable from the computer to the emulator.
4. upload binary to the emulator - should be ready to use.

When powering off the emulator:
1. Remove the USB cable from the emulator.
2. Power off the target system
3. You can remove the emulator probe from your target at this point.

If you're still experiencing U6 lockup, swap it for the 74LS595 or 74F595
versions - those are TTL and will not lockup.

Kris

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

pocoaust, 2023-12-31:
Hi mate,  Merry Xmas and Happy new Year.

Yes, I have 2 versions....  (Gave TLY probe one to mate who only needed
27256 emulation.)  Only has RN2 installed on this one as per Assembly
instructions  April 2021 Ver 2.2A  This worked on Amstrad CPC.

Built new one yesterday with FDP probes....

added RN3....  Assembly instructions shows as empty  April 2021 Ver 2.2A

Found a bad gate on one 541... 4 in this batch...  ALi express ....
AHHHHHH

Now 28 Pin FDP 28 pin now works in Amstrad and TLL866

24 Pin in Tec-1a (2716 emulation) still does not work, but reads in
TL866 okay....

I have tried cutting VPP line Pin 21 on 24 pin FDP Probe, as is still
connected to A11, but still no go.

I have tried removing RN2, but behaves worse.

Should I bend up the 2 pins on RN2 for the CS and OE lines? Could it be
like the spectrum?

The 595 now only still heats after after attempting to use and cycling
power several times on Tec 1a.....  It then continues to grow hot even
when TEC-1a is Powered down?  to stop I must power down emulator
.....Cmos hangup?

Any help appreciated.

Paul

------ Original Message ------
From "Kris Sekula" ***@***.***>
To "Kris-Sekula/EPROM-EMU-NG" ***@***.***>
Cc "pocoaust" ***@***.***>; "Author" ***@***.***>
Date 31/12/2023 3:26:40 PM
Subject Re: [Kris-Sekula/EPROM-EMU-NG] Cannot get FDP type probes to
work with V2.2d board (Issue #26)

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

Kris-Sekula, 2023-12-31:
Hey Paul, thanks, and Happy New Year to you too.

The recommendation on RN3 changed since the document was published - I updated and put a note into the assembly document today. Not populating RN3 will sometimes cause the U6 to go into CMOS lockup - the only way to "un-lock" it, is to remove power from the emulator (both power from target and power from USB) ... the lockup can happen based on all sorts of conditions and is very "case" specific... power cycling the target while it's connected to a computer can cause the issue, so I'm not surprised this is what you see when you cycle multiple times power on your TEC.

I am not sure why your TEC 1a is not playing well with the emulator ... probably worth isolating the pull-up on OE and CE lines to see if it makes any difference, considering that your TL866 "reads" the emulator correctly it must be somehow the interaction between the units...

I know TEC-1F works fine, as I have that documented in the "use-cases" sent to me by William. I'll take a look at the schematic on 1a and try to give you some advice.

Do you have a scope, so that we can take a look at those signals while the emulator is plugged in?

Kris

Closed 2024-01-16.

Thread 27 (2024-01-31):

Errors in EpromEmu_2_2d_BoM_DigiKey_v1.xlsx

ellensp, 2024-01-31:
EpromEmu_2_2d_BoM_DigiKey_v1.xlsx list the following

```
Index	Quantity	Part Number	    Manufacturer Part Number	Description	                Customer Reference
5	2	        4610X-1-103LF-ND    4610X-101-103LF             RES ARRAY 9 RES 10K OHM 10SIP	RN2
31	1	        A786AR-ND           10-0518-10	                CONN SOCKET SIP 10POS GOLD	RN2

```

but the assembly documents says you need RN2 and RN3

So these are in error.

Index 5 the customer reference should be RN2, RN3
Index 31 the quantity should be 2 and the customer reference should be RN2, RN3

Kris-Sekula, 2024-01-31:
you're correct, thanks for spotting and reporting ...I've updated the Bom. Also just FYI, I've updated the RNs to 47k from 10k ... either value is ok, but I'm now using 47k in the assembled emulators that I offer.

Closed 2024-01-31.

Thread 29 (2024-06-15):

Value RN1 to RN3

rolo64416, 2024-06-15:
There is a difference in values of RN1, RN2 and RN3. In the schematic and on the board it is 10K, in the BOM it is 47K.

Kris-Sekula, 2024-06-15:
I’ve been using both, 10k, 22k, and 47k will all work fine

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

rolo64416, 2024-06-15:
Thanks.

Closed 2024-06-15.

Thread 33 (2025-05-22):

byteBuffer seems to not contain data and is writing a "blank" EPROM to the SPI buffer

Pyrofer, 2025-05-22:
When I program the EPROM it works in real time, it emulates correctly and the host boots.
If I reload from SPI via resetting the nano or hitting the load button it "blanks" the ram to FF.
I put a Serial.print(byteBuffer(k+1); into the SPI write section which should echo the data being written to the screen, but I get this instead,

EPROM EMU NG tool v2.0rc10

Processing ROM32K.HEX.BIN... done (bin)
Each symbol represents 128Bytes "*" with data, "-" with no data

0x0000 * * * * * * * * * * * * * * * * * * * * * * * * * * * * * * * *
0x1000 * * * * * * * * * * * * * * * * * * * * * * * * * * * * * * * *
0x2000 - - - - - - - - - - - - - - - - - - - - - - - - - - - - - - - -
0x3000 - - - - - - - - - - - - - - - - - - - - - - - - - - - - - - - -
0x4000 - - - - - - - - - - - - - - - - - - - - - - - - - - - - - - - -
0x5000 - - - - - - - - - - - - - - - - - - - - - - - - - - - - - - - -
0x6000 - - - - - - - - - - - - - - - - - - - - - - - - - - - - - - - -
0x7000 - - - - - - - - - - - - - - - - - - - - - - - - - - - - - - - -
0x8000 - - - - - - - - - - - - - - - - - - - - - - - - - - - - - - - -
0x9000 - - - - - - - - - - - - - - - - - - - - - - - - - - - - - - - -
0xA000 - - - - - - - - - - - - - - - - - - - - - - - - - - - - - - - -
0xB000 - - - - - - - - - - - - - - - - - - - - - - - - - - - - - - - -
0xC000 - - - - - - - - - - - - - - - - - - - - - - - - - - - - - - - -
0xD000 - - - - - - - - - - - - - - - - - - - - - - - - - - - - - - - -
0xE000 - - - - - - - - - - - - - - - - - - - - - - - - - - - - - - - -
0xF000 - - - - - - - - - - - - - - - - - - - - - - - - - - - - - - - - Using serial port COM28, emulating: 2764 EPROM
<- attempting to get sync
-> HW: v2.2d, FW: 2.0rc12, SPI: 1, Auto: 1, Last EPROM: 2764, mygeekyhobby.com 2020 :)
<- Setting "Save to SPI EEPROM" option to enable
-> Bus set to 27512 EPROM Memory
<- Setting "Auto load from SPI EEPROM" option to enable
-> SPI save ON
<- processing file:
0x1E00 ->in
Time taken to transfer: 4.84s
<- Setting EPROM Type
255,255,255,255,255,255,255,255,255,255,255,255,255,255,255,255,255,255,255,255,255,255,255,255,255,255,255,255,255,255,255,255,255,255,255,255,255,255,255,255,255,255,255,255,255,255,255,255,255,255,255,255,255,255,255,255,255,255,255,255,255,255,255,255,255,255,255,255,255,255,255,255,255,255,255,255,255,255,255,255,255,255,255,255,255,255,255,255,255,255,255,255,255,255,255,255,255,255,255,255,255,255,255,255,255,255,255,255,255,255,255,255,255,255,255,255,255,255,255,255,255,255,255,255,255,255,255,255,255,255,255,255,255,255,255,255,255,255,255,255,255,255,255,255,255,255,255,255,255,255,255,255,255,255,255,255,255,255,255,255,255,255,255,255,255,255,255,255,255,255,255,255,255,255,255,255,255,255,255,255,255,255,255,255,255,255,255,255,255,255,255,255,255,255,255,255,255,255,255,255,255,255,255,255,255,255,255,255,255,255,255,255,255,255,255,255,255,255,255,255,255,255,255,255,255,255,255,255,255,255,255,255,255,255,255,255,255,255,255,255,255,255,255,255,255,255,255,255,255,255,255,255,255,255,255,255,255,255,255,255,255,255,255,255,255,255,255,255,255,255,255,255,255,255,255,255,255,255,255,255,255,255,255,255,255,255,255,255,255,255,255,255,255,255,255,255,255,255,255,255,255,255,255,255,255,255,255,255,255,255,255,255,255,255,255,255,255,255,255,255,255,255,255,255,255,255,255,255,255,255,255,255,255,255,255,255,255,255,255,255,255,255,255,255,255,255,255,255,255,255,255,255,255,255,255,255,255,255,255,255,255,255,255,255,255,255,255,255,255,255,255,255,255,255,255,255,255,255,255,255,255,255,255,255,255,255,255,255,255,255,255,255,255,255,255,255,255,255,255,255,255,255,255,255,255,255,255,255,255,255,255,255,255,255,255,255,255,255,255,255,255,255,255,255,255,255,255,255,255,255,255,255,255,255,255,255,255,255,255,255,255,255,255,255,255,255,255,255,255,255,255,255,255,255,255,255,255,255,255,255,255,255,255,255,255,255,255,255,255,255,255,255,255,255,255,255,255,255,255,255,255,255,255,255,255,255,255,255,255,255,255,255,255,255,255,255,255,255,255,255,255,255,255,255,255,255,255,255,255,255,255,255,ACK
<- Enable Emulation
-> Bus set to 2764 EPROM Memory

Success, Finished.

However the RAM only contains the correct data and the SPI does not, any reset or reload of the emulator blanks the ram.

Kris-Sekula, 2025-06-03:
used incorrect type of EEPROM, all worked fine once the correct IC was used....

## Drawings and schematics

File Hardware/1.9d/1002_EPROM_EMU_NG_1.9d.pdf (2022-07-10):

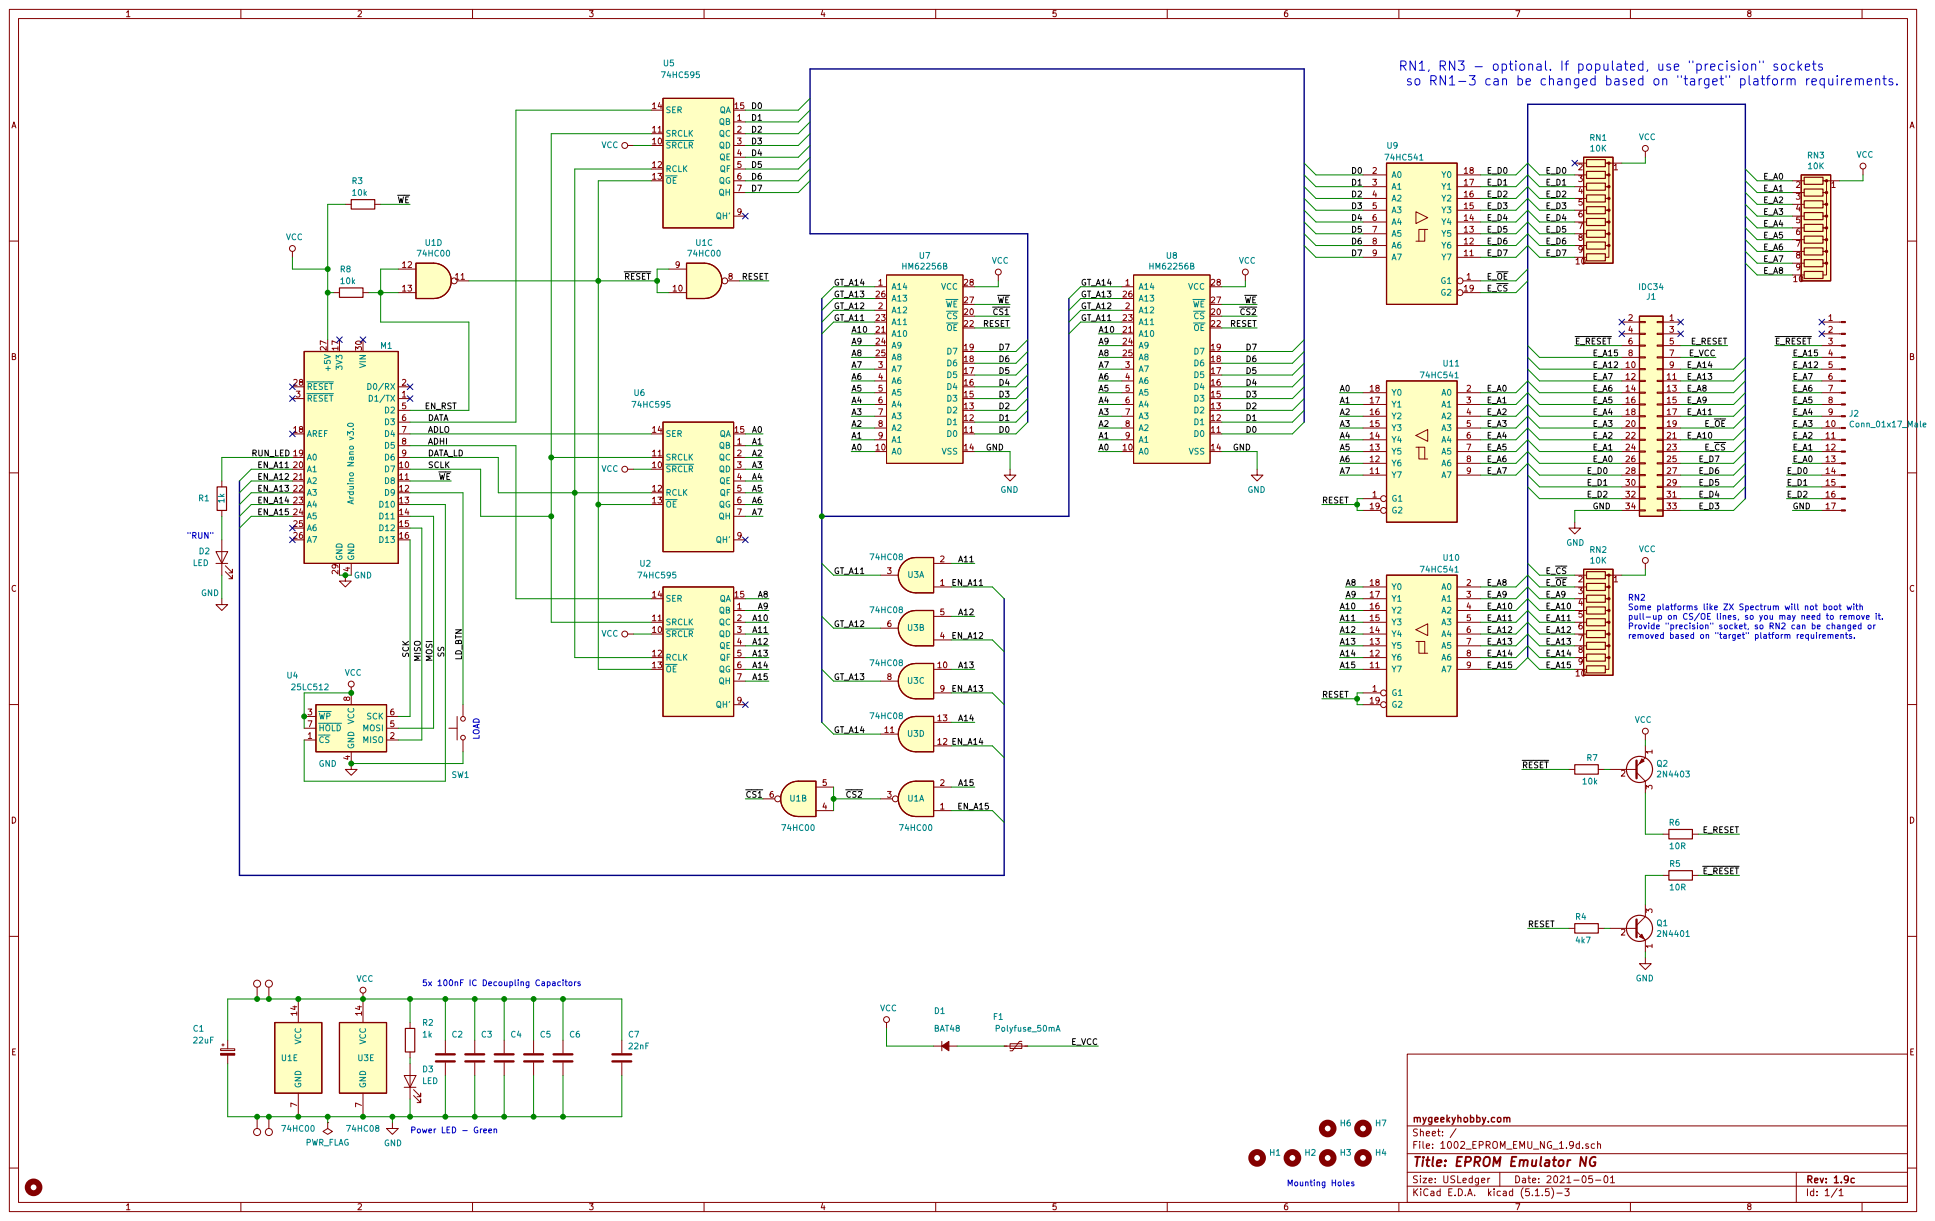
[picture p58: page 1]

4 D2 5 D3 6 D4 7 D5 8 D6 9 M1 Arduino Nano v3.0 QB 1 SRCLR 10 SRCLK 11 RCLK 12 OE 13 SER 14 QA 15 QC 2 QD 3 QE 4 QF 5 QG 6 QH 7 QH' 9 U5

RN1, RN3 - optional. If populated, use "precision" sockets
so RN1-3 can be changed based on "target" platform requirements.

RN2 Some platforms like ZX Spectrum will not boot with

pull-up on CS/OE lines, so you may need to remove it.
Provide "precision" socket, so RN2 can be changed or

4 MOSI 5 SCK 6 HOLD 7 VCC

File: 1002_EPROM_EMU_NG_1.9d.sch Sheet: / mygeekyhobby.com

Id: 1/1 Title: EPROM Emulator NG

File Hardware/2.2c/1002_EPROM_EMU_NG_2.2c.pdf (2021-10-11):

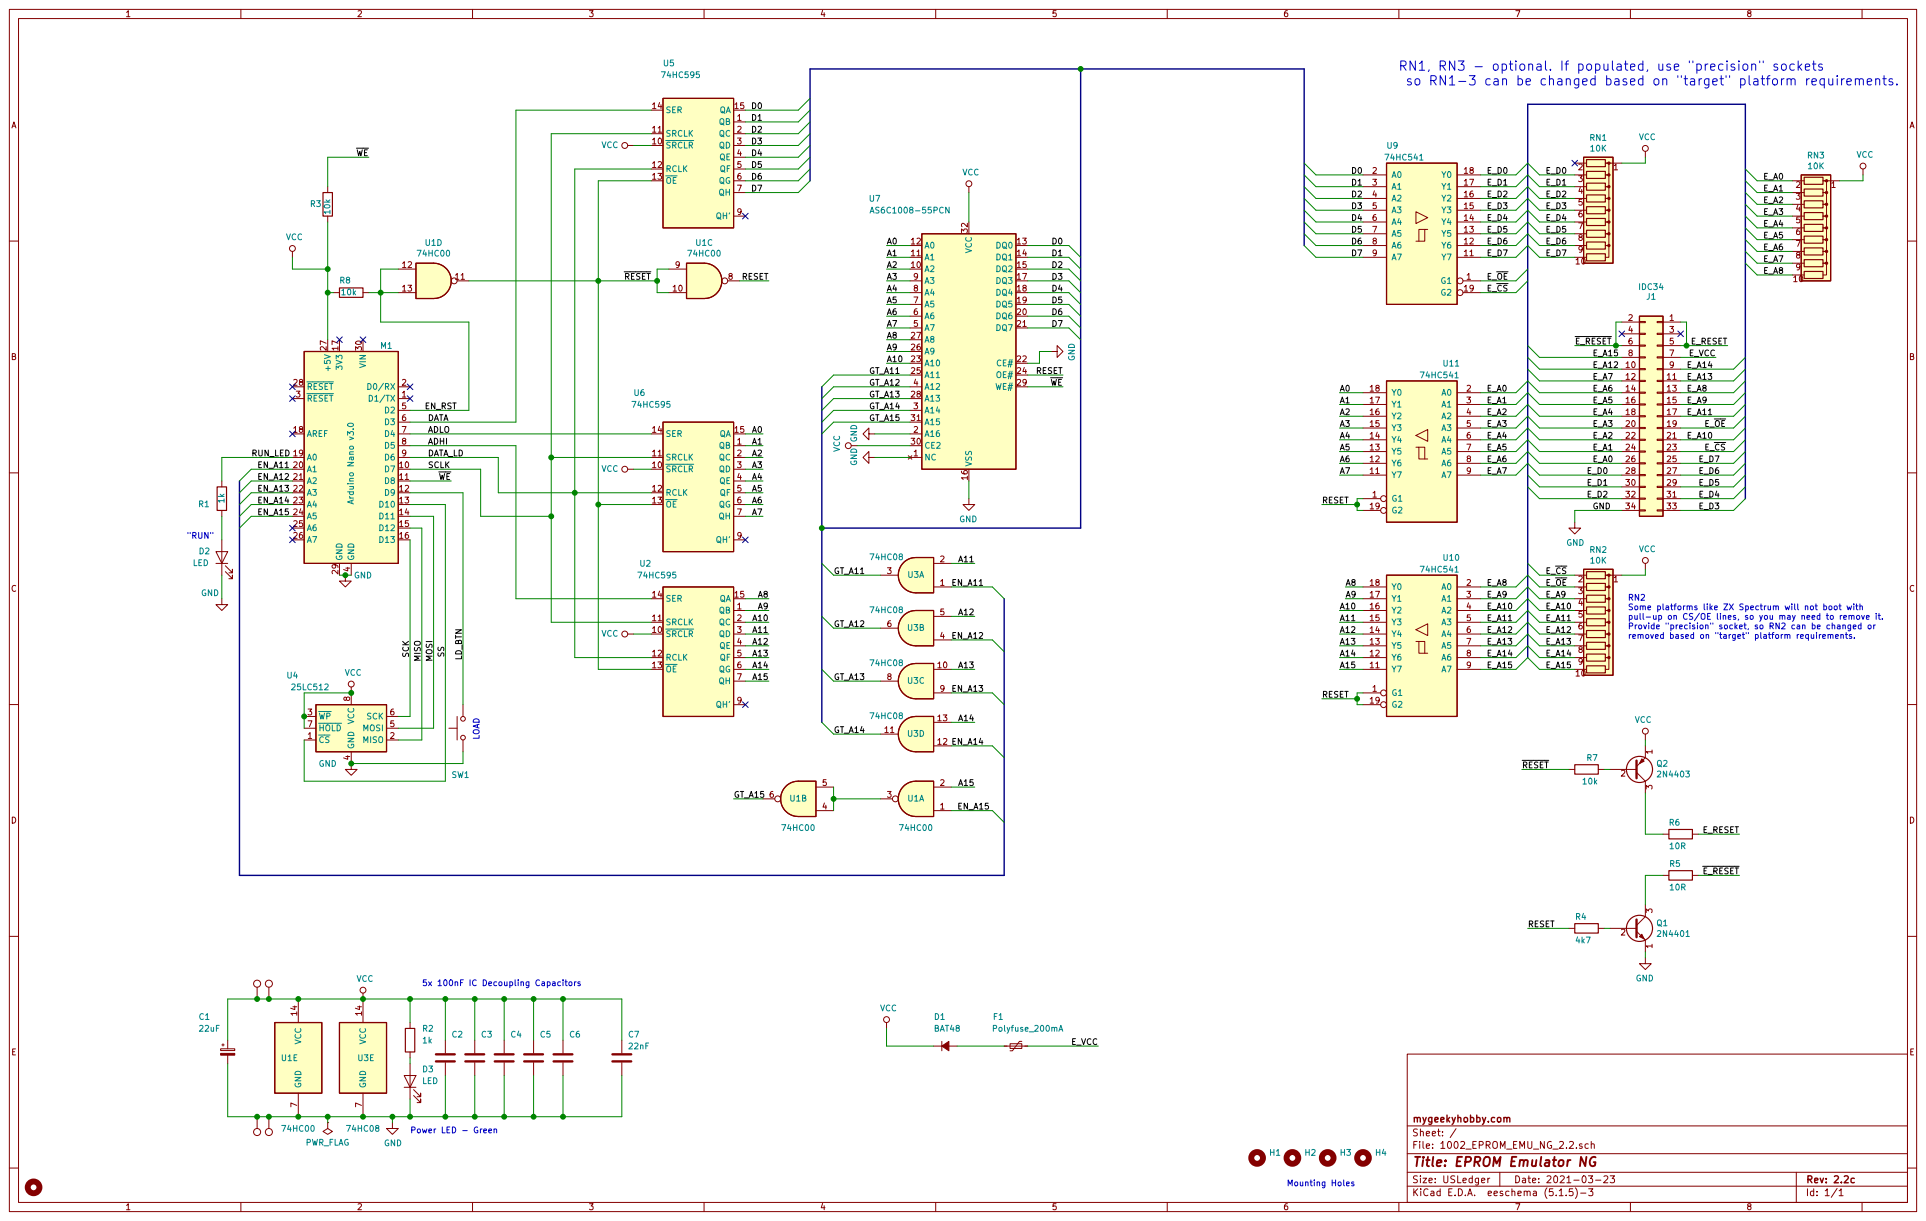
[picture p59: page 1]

RN1, RN3 - optional. If populated, use "precision" sockets

so RN1-3 can be changed based on "target" platform requirements. LOAD

RN2 Some platforms like ZX Spectrum will not boot with

pull-up on CS/OE lines, so you may need to remove it.
Provide "precision" socket, so RN2 can be changed or
removed based on "target" platform requirements.
10R GND

Id: 1/1 Title: EPROM Emulator NG

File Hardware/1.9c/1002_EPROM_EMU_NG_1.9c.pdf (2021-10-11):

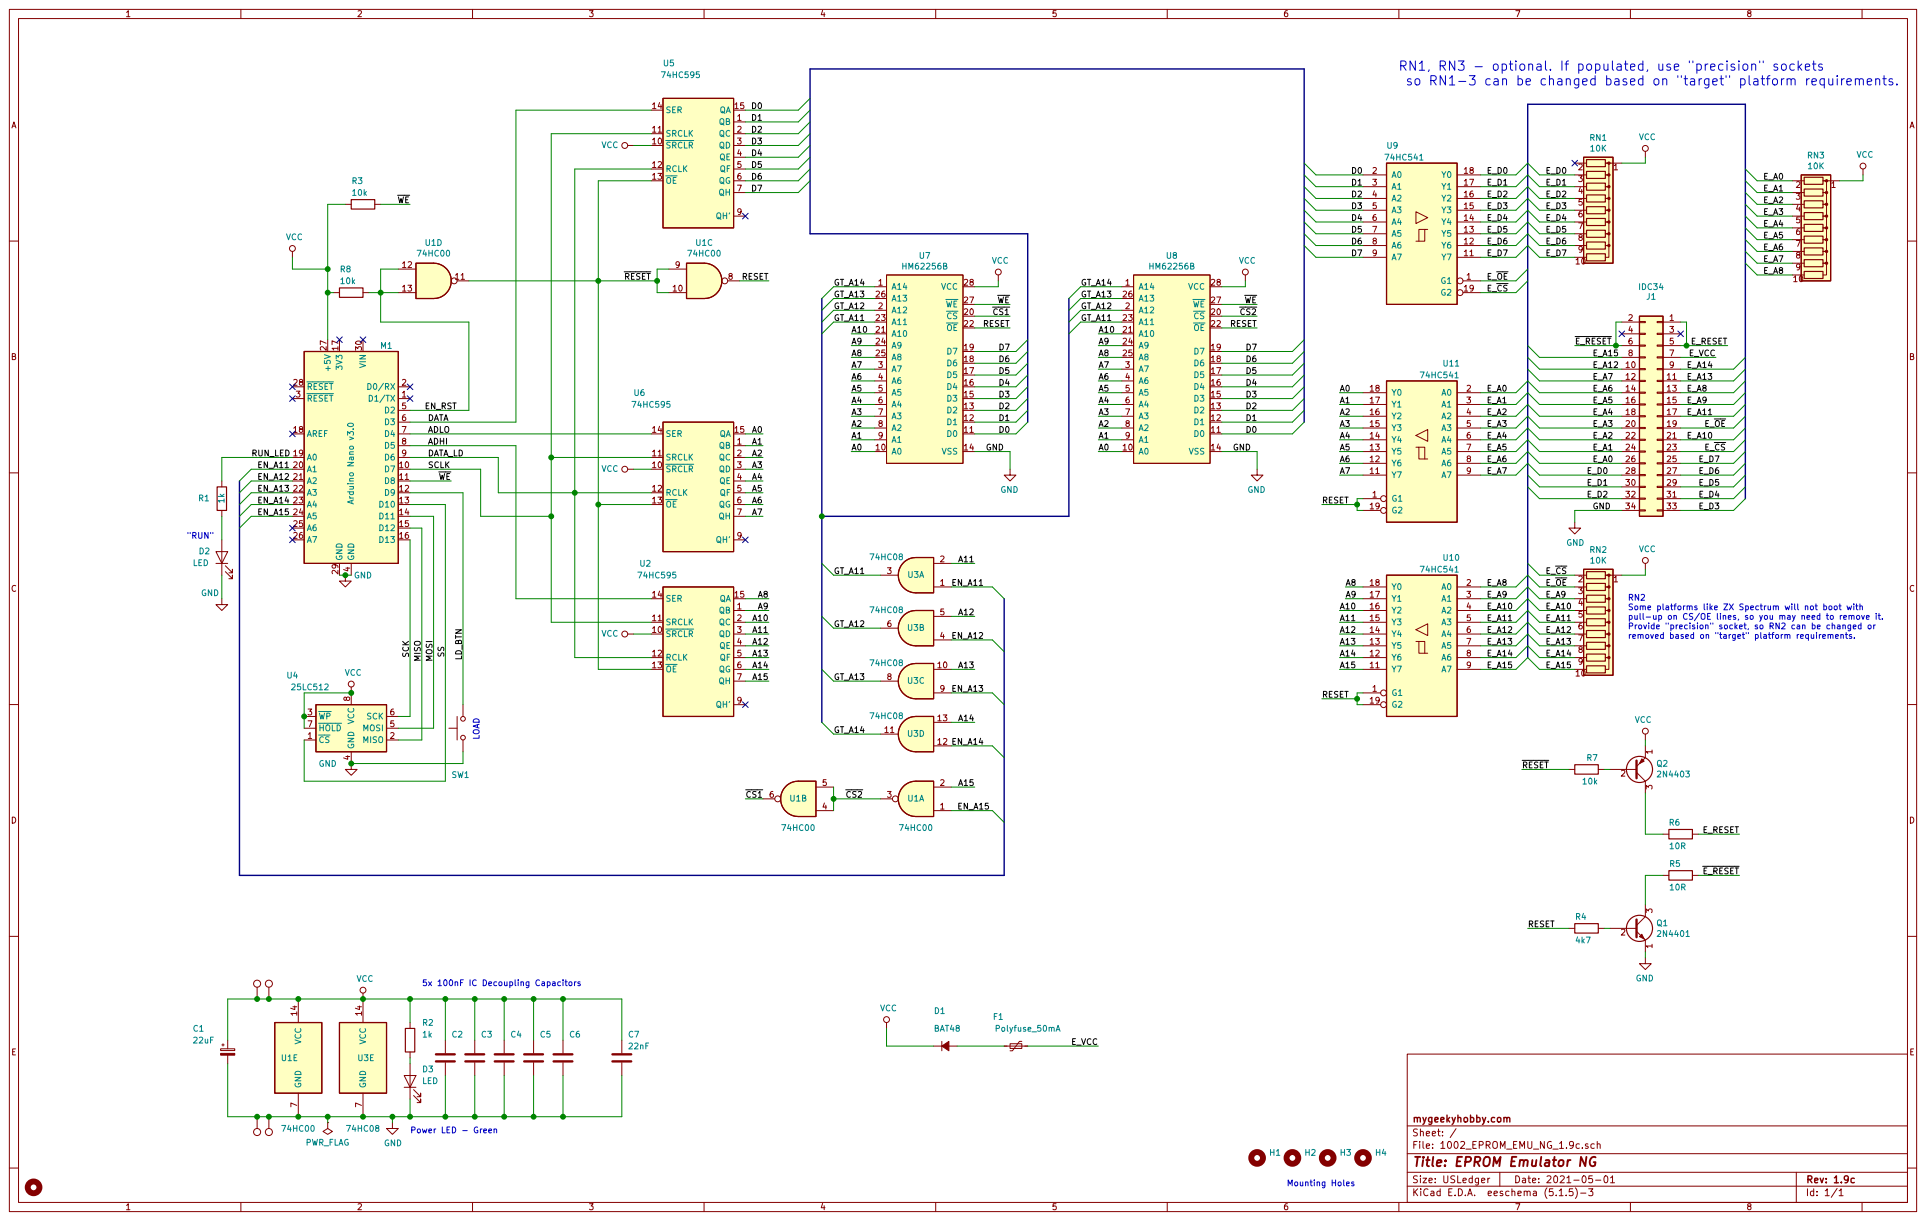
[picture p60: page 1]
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

5x 100nF IC Decoupling Capacitors LOAD

pull-up on CS/OE lines, so you may need to remove it.
Provide "precision" socket, so RN2 can be changed or
removed based on "target" platform requirements.
2N4401 VCC GND

File: 1002_EPROM_EMU_NG_1.9c.sch Sheet: / mygeekyhobby.com

Id: 1/1 Title: EPROM Emulator NG

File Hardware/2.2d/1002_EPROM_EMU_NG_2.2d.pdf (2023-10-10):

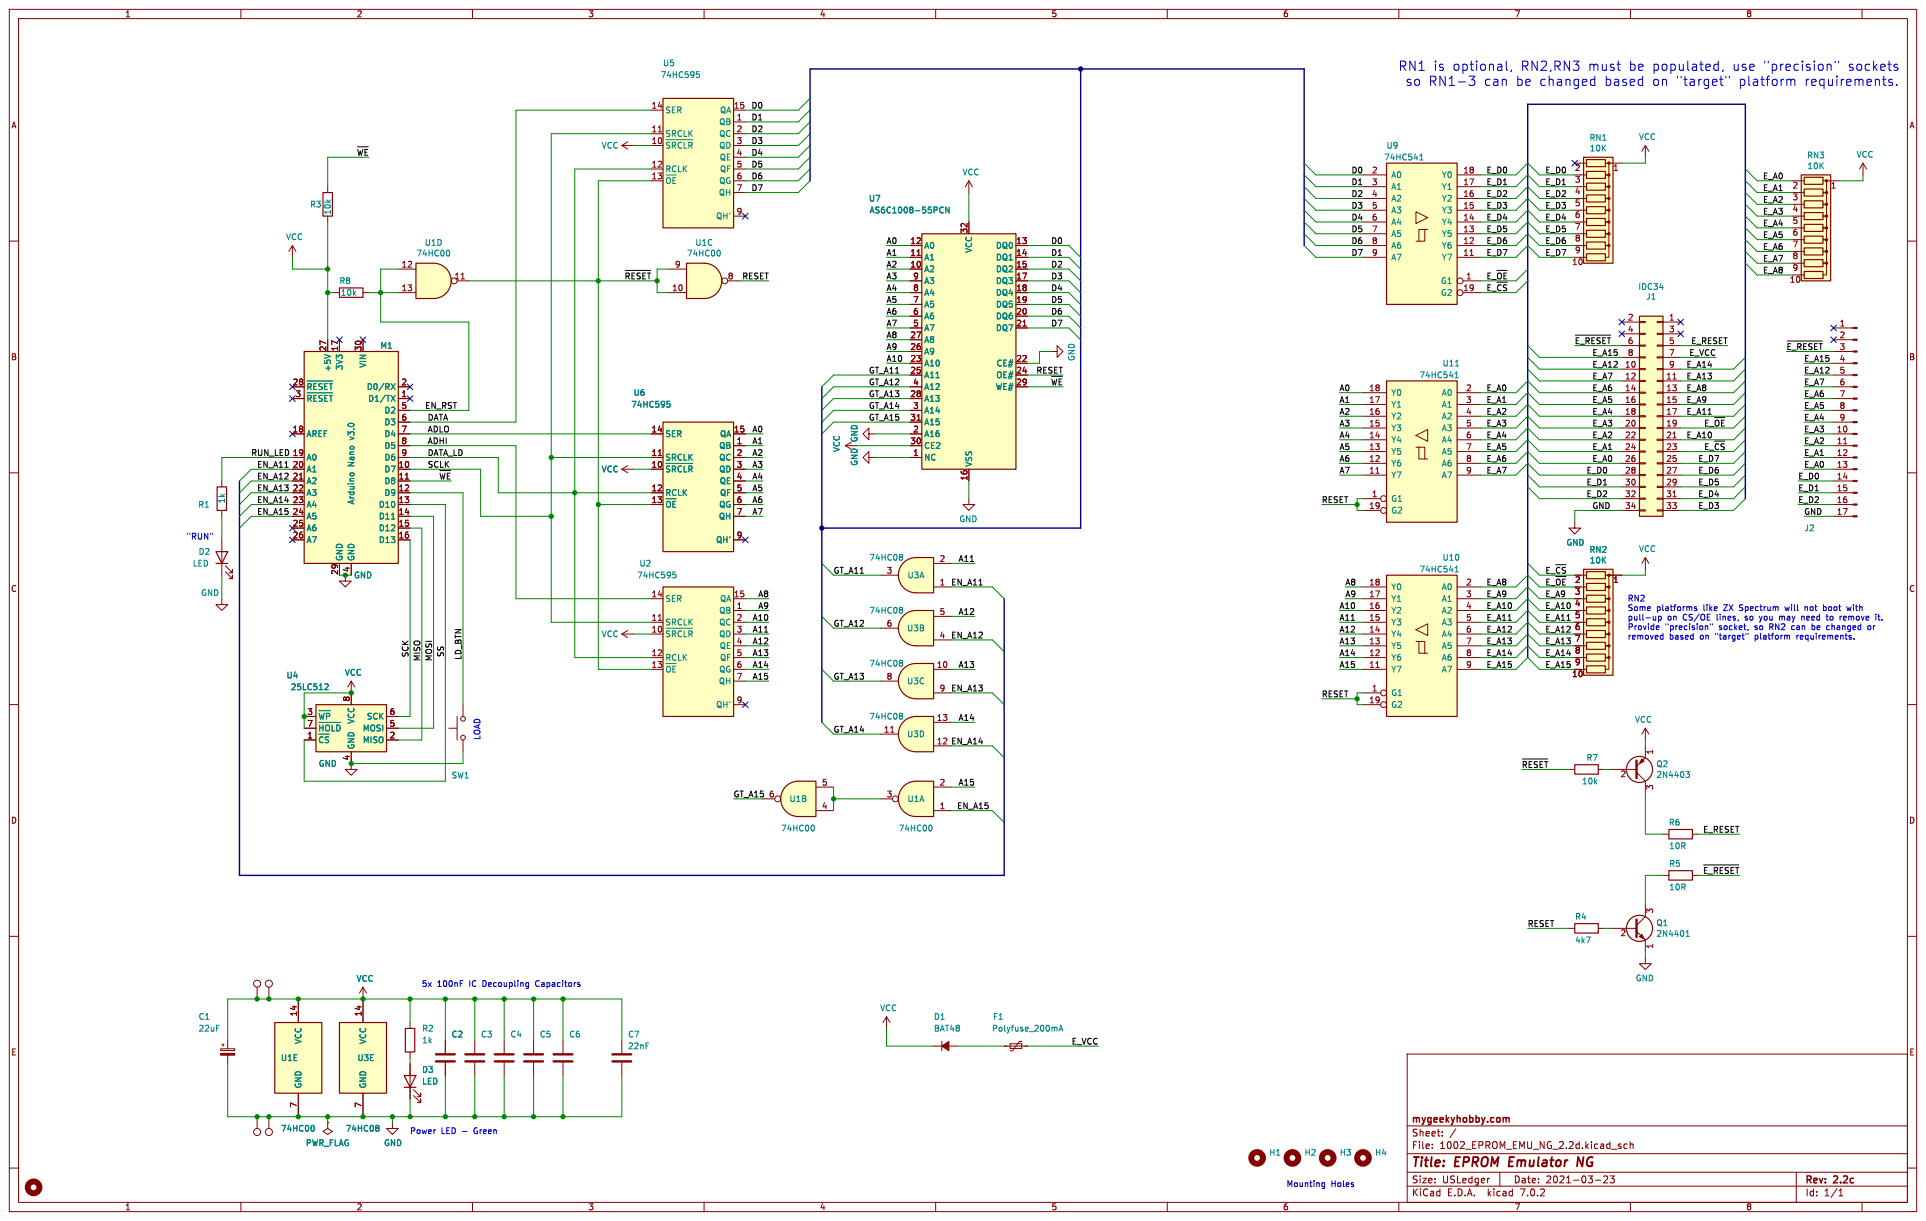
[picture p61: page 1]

Id: 1/1 Title: EPROM Emulator NG

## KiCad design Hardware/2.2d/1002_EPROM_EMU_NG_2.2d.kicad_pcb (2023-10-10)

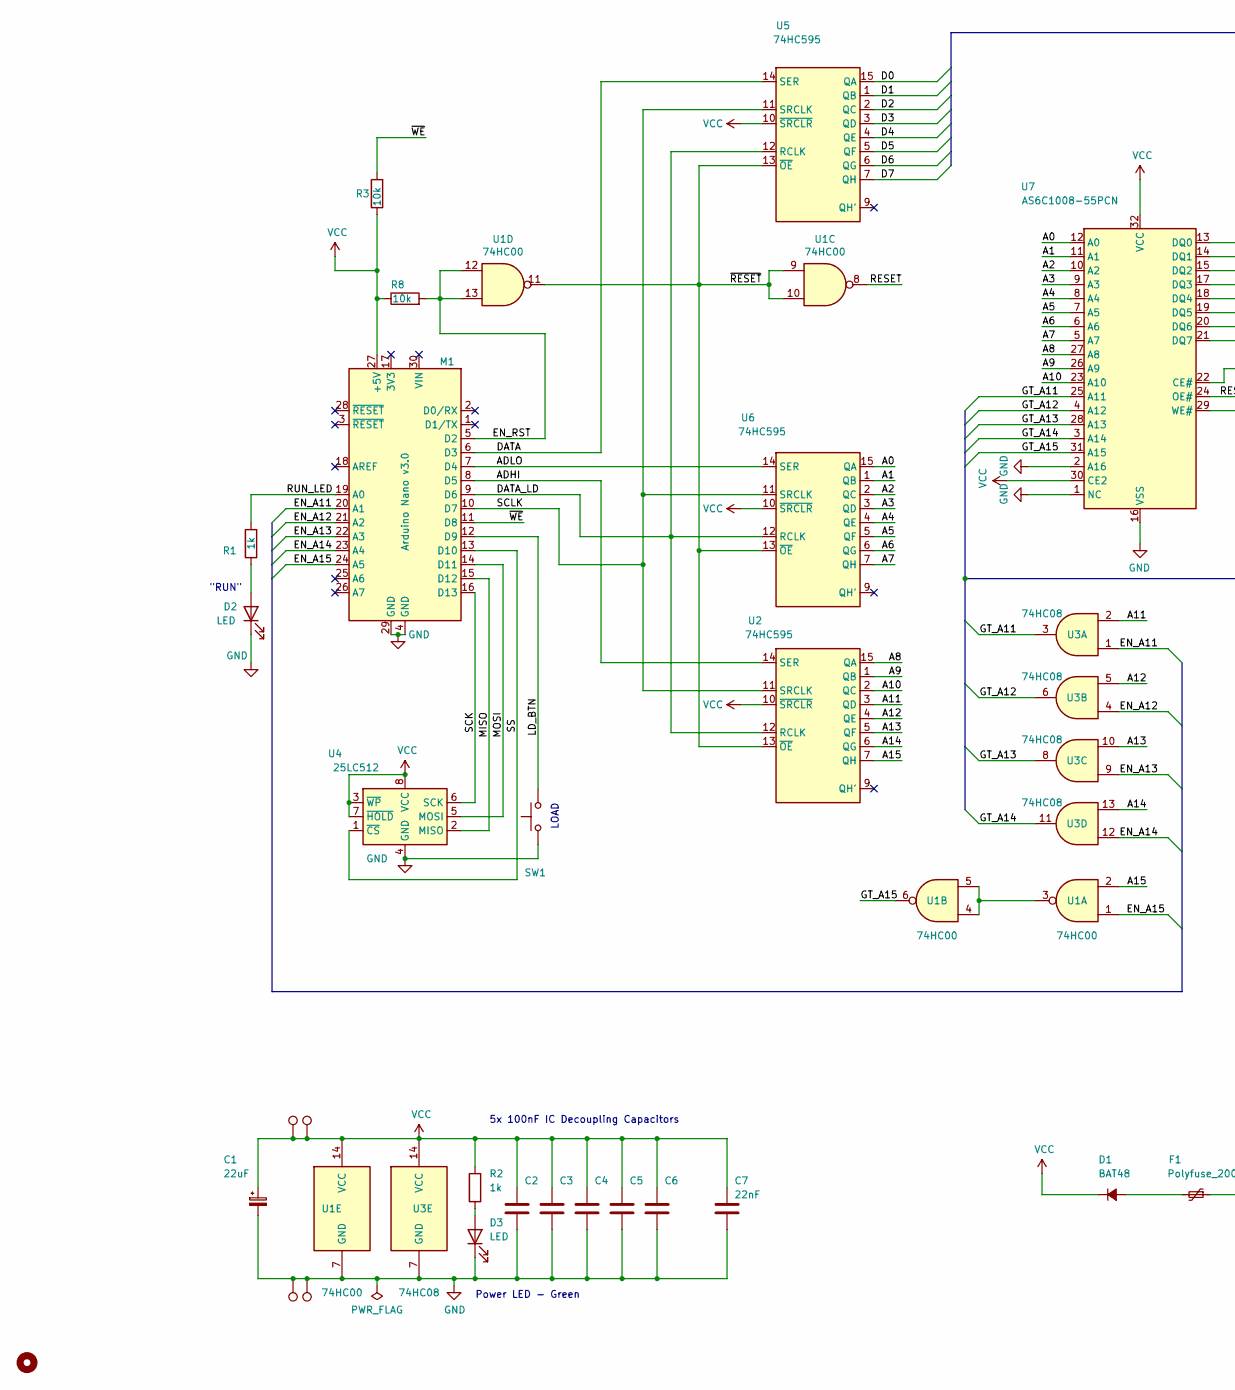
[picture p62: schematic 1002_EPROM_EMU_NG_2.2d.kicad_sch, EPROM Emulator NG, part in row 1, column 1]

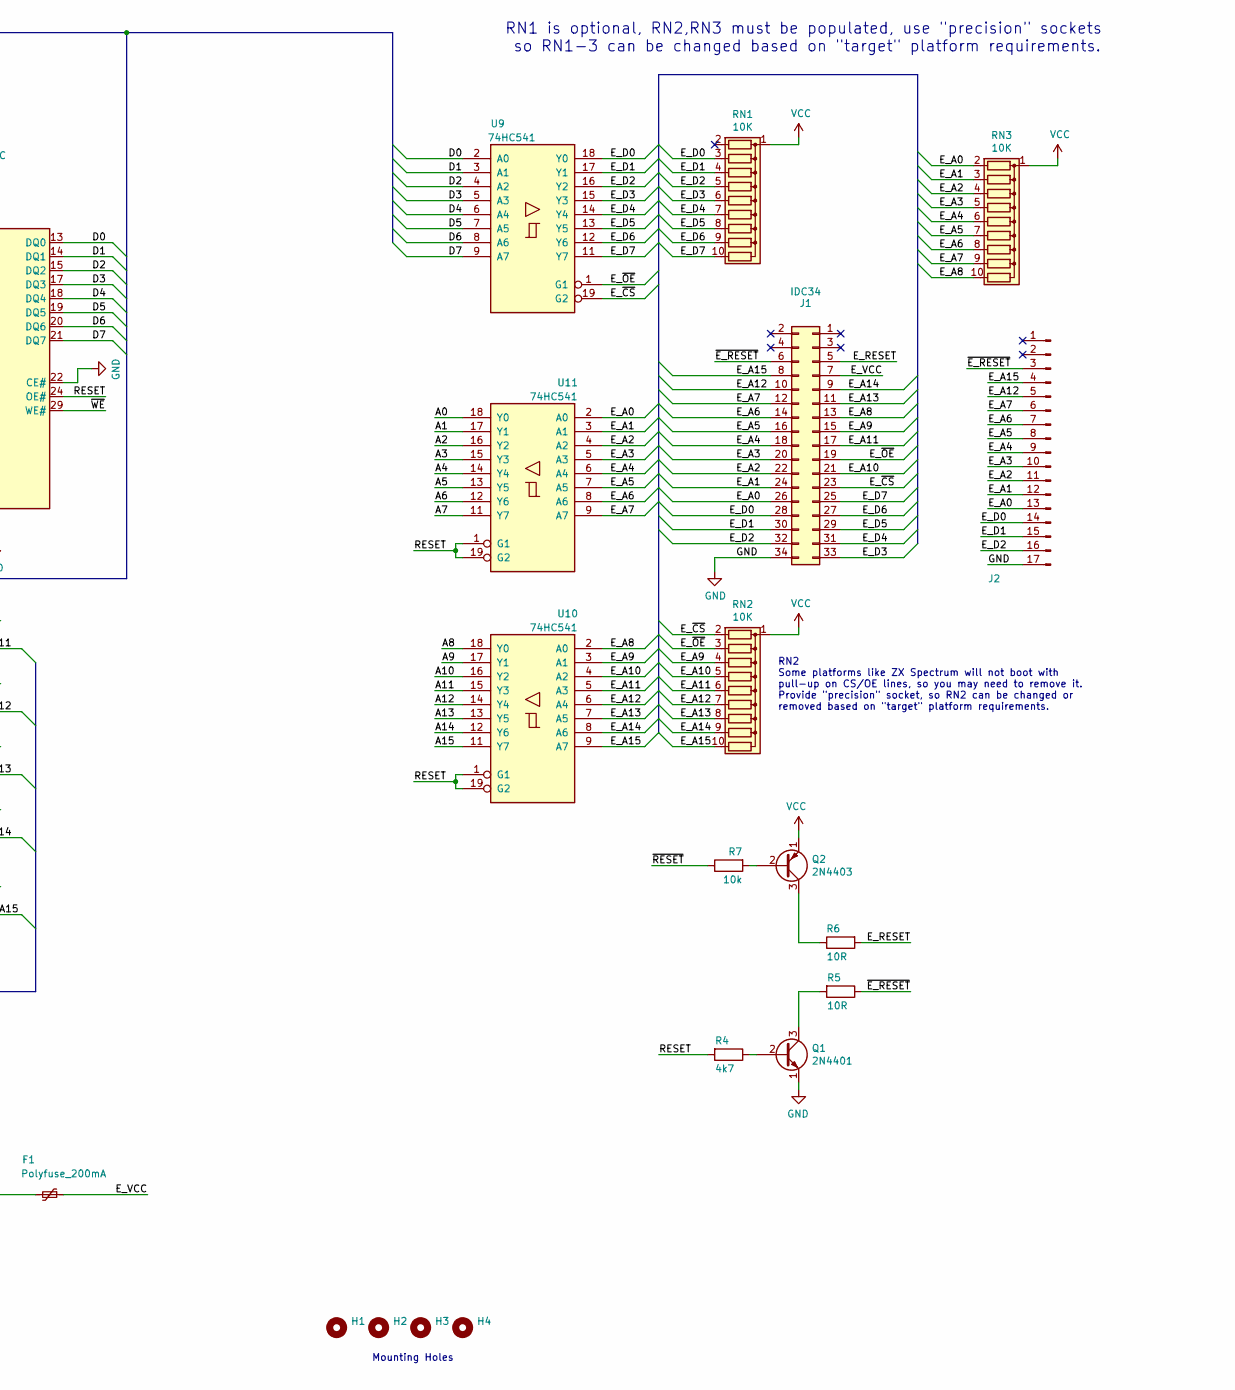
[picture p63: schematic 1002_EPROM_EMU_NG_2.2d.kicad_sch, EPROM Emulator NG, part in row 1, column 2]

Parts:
C1: 22uF; CP_Radial_D6.3mm_P2.50mm
C2, C3, C4, C5, C6: 100nF; C_Disc_D4.7mm_W2.5mm_P5.00mm
C7: 22nF; C_Disc_D4.7mm_W2.5mm_P5.00mm
D1: BAT48; D_DO-35_SOD27_P7.62mm_Horizontal
D2, D3: LED; LED_D3.0mm
F1: Polyfuse_200mA; C_Disc_D10.0mm_W2.5mm_P5.00mm
H1, H2, H3, H4: MountingHole; MountingHole_2.2mm_M2
H5: MountingHole; OSHW-Logo2_9.8x8mm_SilkScreen
J1: IDC34; IDC-Header_2x17_P2.54mm_Horizontal_Lock
J2: Conn_01x17_Male; PinHeader_1x17_P2.54mm_Vertical
M1: Arduino Nano v3.0; Arduino_Nano
Q1: 2N4401; TO-92_Inline_Wide
Q2: 2N4403; TO-92_Inline_Wide
R1, R2: 1k; R_Axial_DIN0204_L3.6mm_D1.6mm_P7.62mm_Horizontal
R3, R7, R8: 10k; R_Axial_DIN0204_L3.6mm_D1.6mm_P7.62mm_Horizontal
R4: 4k7; R_Axial_DIN0204_L3.6mm_D1.6mm_P7.62mm_Horizontal
R5, R6: 10R; R_Axial_DIN0204_L3.6mm_D1.6mm_P7.62mm_Horizontal
RN1, RN2, RN3: 10K; R_Array_SIP10
SW1: SW_Push; SW_PUSH_6mm
TP1, TP4: VCC; TestPoint_THTPad_D1.5mm_Drill0.7mm
TP2, TP3: GND; TestPoint_THTPad_D1.5mm_Drill0.7mm
U1: 74HC00; DIP-14_W7.62mm_Socket
U2, U5, U6: 74HC595; DIP-16_W7.62mm_Socket
U3: 74HC08; DIP-14_W7.62mm_Socket
U4: 25LC512; DIP-8_W7.62mm_Socket
U7: AS6C1008-55PCN; DIP-32_W15.24mm_Socket
U9, U10, U11: 74HC541; DIP-20_W7.62mm_Socket

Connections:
/A0: U6.15 (QA), U7.12 (A0), U11.18 (Y0)
/A1: U6.1 (QB), U7.11 (A1), U11.17 (Y1)
/A2: U6.2 (QC), U7.10 (A2), U11.16 (Y2)
/A3: U6.3 (QD), U7.9 (A3), U11.15 (Y3)
/A4: U6.4 (QE), U7.8 (A4), U11.14 (Y4)
/A5: U6.5 (QF), U7.7 (A5), U11.13 (Y5)
/A6: U6.6 (QG), U7.6 (A6), U11.12 (Y6)
/A7: U6.7 (QH), U7.5 (A7), U11.11 (Y7)
/A8: U2.15 (QA), U7.27 (A8), U10.18 (Y0)
/A9: U2.1 (QB), U7.26 (A9), U10.17 (Y1)
/A10: U2.2 (QC), U7.23 (A10), U10.16 (Y2)
/A11: U2.3 (QD), U3.2, U10.15 (Y3)
/A12: U2.4 (QE), U3.5, U10.14 (Y4)
/A13: U2.5 (QF), U3.10, U10.13 (Y5)
/A14: U2.6 (QG), U3.13, U10.12 (Y6)
/A15: U1.2, U2.7 (QH), U10.11 (Y7)
/ADHI: M1.8 (D5), U2.14 (SER)
/ADLO: M1.7 (D4), U6.14 (SER)
/D0: U5.15 (QA), U7.13 (DQ0), U9.2 (A0)
/D1: U5.1 (QB), U7.14 (DQ1), U9.3 (A1)
/D2: U5.2 (QC), U7.15 (DQ2), U9.4 (A2)
/D3: U5.3 (QD), U7.17 (DQ3), U9.5 (A3)
/D4: U5.4 (QE), U7.18 (DQ4), U9.6 (A4)
/D5: U5.5 (QF), U7.19 (DQ5), U9.7 (A5)
/D6: U5.6 (QG), U7.20 (DQ6), U9.8 (A6)
/D7: U5.7 (QH), U7.21 (DQ7), U9.9 (A7)
/DATA: M1.6 (D3), U5.14 (SER)
/DATA_LD: M1.9 (D6), U2.12 (RCLK), U5.12 (RCLK), U6.12 (RCLK)
/EN_A11: M1.20 (A1), U3.1
/EN_A12: M1.21 (A2), U3.4
/EN_A13: M1.22 (A3), U3.9
/EN_A14: M1.23 (A4), U3.12
/EN_A15: M1.24 (A5), U1.1
/EN_RST: M1.5 (D2), R8.2, U1.12, U1.13
/E_A0: J1.26, J2.13, RN3.2 (R1), U11.2 (A0)
/E_A1: J1.24, J2.12, RN3.3 (R2), U11.3 (A1)
/E_A2: J1.22, J2.11, RN3.4 (R3), U11.4 (A2)
/E_A3: J1.20, J2.10, RN3.5 (R4), U11.5 (A3)
/E_A4: J1.18, J2.9, RN3.6 (R5), U11.6 (A4)
/E_A5: J1.16, J2.8, RN3.7 (R6), U11.7 (A5)
/E_A6: J1.14, J2.7, RN3.8 (R7), U11.8 (A6)
/E_A7: J1.12, J2.6, RN3.9 (R8), U11.9 (A7)
/E_A8: J1.13, RN3.10 (R9), U10.2 (A0)
/E_A9: J1.15, RN2.4 (R3), U10.3 (A1)
/E_A10: J1.21, RN2.5 (R4), U10.4 (A2)
/E_A11: J1.17, RN2.6 (R5), U10.5 (A3)
/E_A12: J1.10, J2.5, RN2.7 (R6), U10.6 (A4)
/E_A13: J1.11, RN2.8 (R7), U10.7 (A5)
/E_A14: J1.9, RN2.9 (R8), U10.8 (A6)
/E_A15: J1.8, J2.4, RN2.10 (R9), U10.9 (A7)
/E_D0: J1.28, J2.14, RN1.3 (R2), U9.18 (Y0)
/E_D1: J1.30, J2.15, RN1.4 (R3), U9.17 (Y1)
/E_D2: J1.32, J2.16, RN1.5 (R4), U9.16 (Y2)
/E_D3: J1.33, RN1.6 (R5), U9.15 (Y3)
/E_D4: J1.31, RN1.7 (R6), U9.14 (Y4)
/E_D5: J1.29, RN1.8 (R7), U9.13 (Y5)
/E_D6: J1.27, RN1.9 (R8), U9.12 (Y6)
/E_D7: J1.25, RN1.10 (R9), U9.11 (Y7)
/E_RESET: J1.5, R6.2
/E_VCC: F1.1, J1.7
/E_~CS: J1.23, RN2.2 (R1), U9.19 (G2)
/E_~OE: J1.19, RN2.3 (R2), U9.1 (G1)
/GT_A11: U3.3, U7.25 (A11)
/GT_A12: U3.6, U7.4 (A12)
/GT_A13: U3.8, U7.28 (A13)
/GT_A14: U3.11, U7.3 (A14)
/GT_A15: U1.6, U7.31 (A15)
/LD_BTN: M1.12 (D9), SW1.2
/MISO: M1.15 (D12), U4.2 (MISO)
/MOSI: M1.14 (D11), U4.5 (MOSI)
/RESET: R4.2, U1.8, U7.24 (OE#), U10.1 (G1), U10.19 (G2), U11.1 (G1), U11.19 (G2)
/RUN_LED: M1.19 (A0), R1.2
/SCK: M1.16 (D13), U4.6 (SCK)
/SCLK: M1.10 (D7), U2.11 (SRCLK), U5.11 (SRCLK), U6.11 (SRCLK)
/SS: M1.13 (D10), U4.1 (~CS)
/~E_RESET: J1.6, J2.3, R5.1
/~RESET: R7.1, U1.9, U1.10, U1.11, U2.13 (~OE), U5.13 (~OE), U6.13 (~OE)
/~WE: M1.11 (D8), R3.2, U7.29 (WE#)
GND: C1.2, C2.2, C3.2, C4.2, C5.2, C6.2, C7.2, D2.1 (K), D3.1 (K), J1.34, J2.17, M1.4 (GND), M1.29 (GND), Q1.1 (E), SW1.1, TP2.1, TP3.1, U1.7 (GND), U2.8 (GND), U3.7 (GND), U4.4 (GND), U5.8 (GND), U6.8 (GND), U7.1 (NC), U7.2 (A16), U7.16 (VSS), U7.22 (CE#), U9.10 (GND), U10.10 (GND), U11.10 (GND)
unnamed: D1.2 (A), F1.2
unnamed: D2.2 (A), R1.1
unnamed: D3.2 (A), R2.2
unnamed: Q1.2 (B), R4.1
unnamed: Q1.3 (C), R5.2
unnamed: Q2.2 (B), R7.2
unnamed: Q2.3 (C), R6.1
unnamed: U1.3, U1.4, U1.5
VCC: C1.1, C2.1, C3.1, C4.1, C5.1, C6.1, C7.1, D1.1 (K), M1.27 (+5V), Q2.1 (E), R2.1, R3.1, R8.1, RN1.1 (common), RN2.1 (common), RN3.1 (common), TP1.1, TP4.1, U1.14 (VCC), U2.10 (~SRCLR), U2.16 (VCC), U3.14 (VCC), U4.3 (~WP), U4.7 (~HOLD), U4.8 (VCC), U5.10 (~SRCLR), U5.16 (VCC), U6.10 (~SRCLR), U6.16 (VCC), U7.30 (CE2), U7.32 (VCC), U9.20 (VCC), U10.20 (VCC), U11.20 (VCC)

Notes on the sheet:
RN2 Some platforms like ZX Spectrum will not boot with pull-up on CS/OE lines, so you may need to remove it. Provide "precision" socket, so RN2 can be changed or removed based on "target" platform requirements.
"RUN"
Power LED - Green
LOAD
RN1 is optional, RN2,RN3 must be populated, use "precision" sockets so RN1-3 can be changed based on "target" platform requirements.
5x 100nF IC Decoupling Capacitors
Mounting Holes

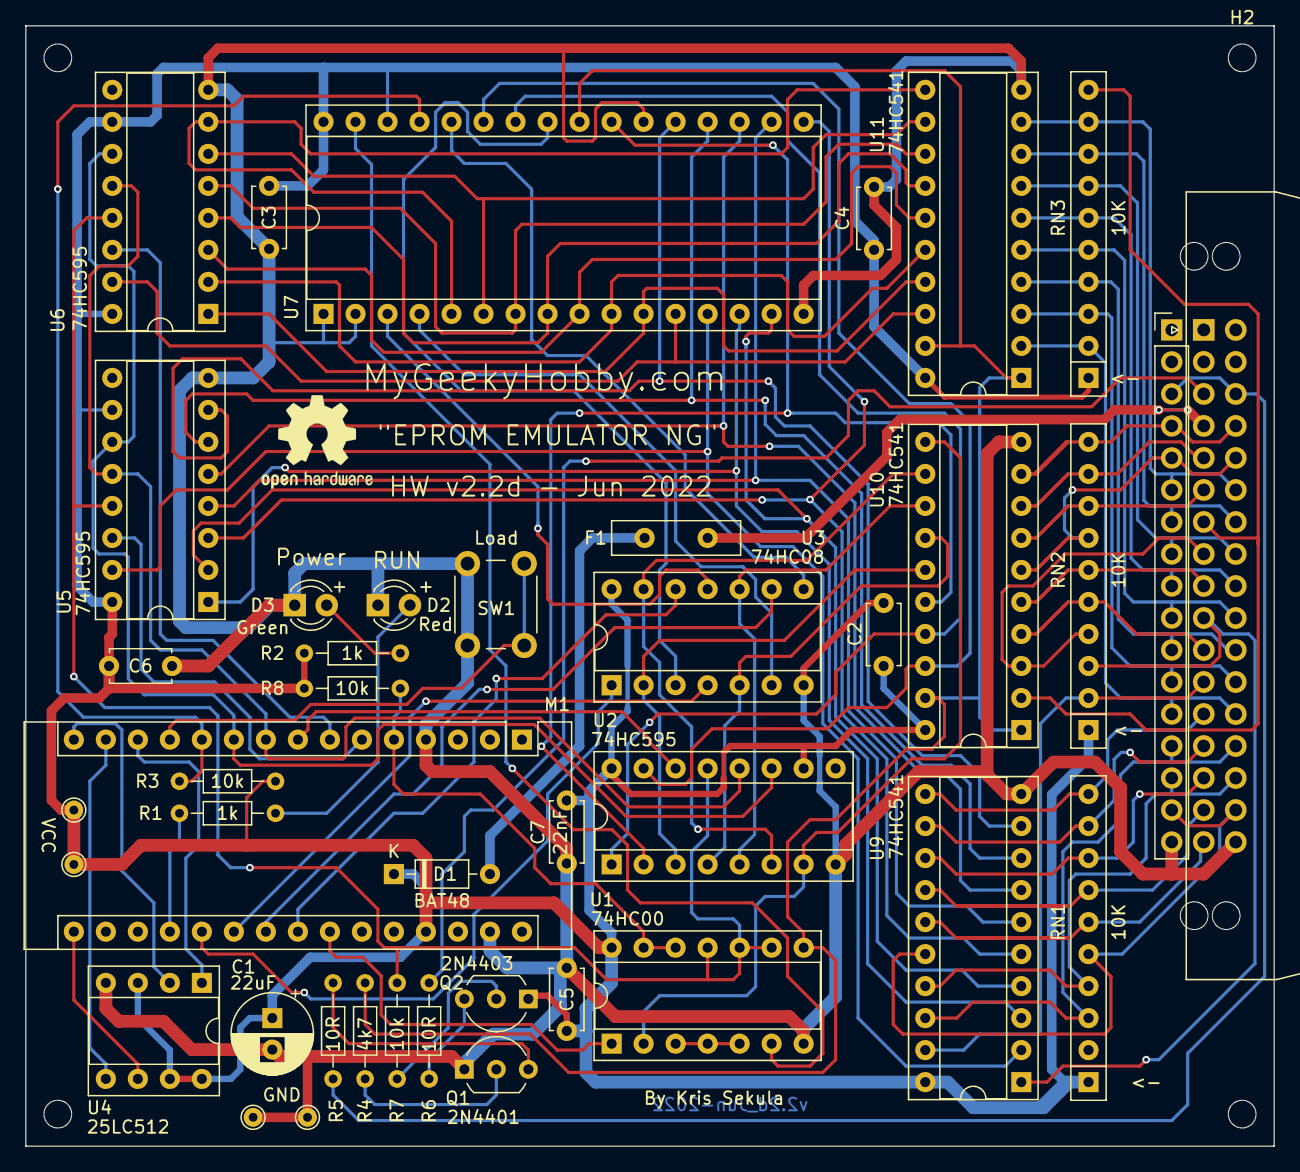
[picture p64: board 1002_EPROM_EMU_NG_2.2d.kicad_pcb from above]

Board: 2 copper layers, 99.1 x 88.9 mm, 47 parts (0 on the bottom side), 88 nets.

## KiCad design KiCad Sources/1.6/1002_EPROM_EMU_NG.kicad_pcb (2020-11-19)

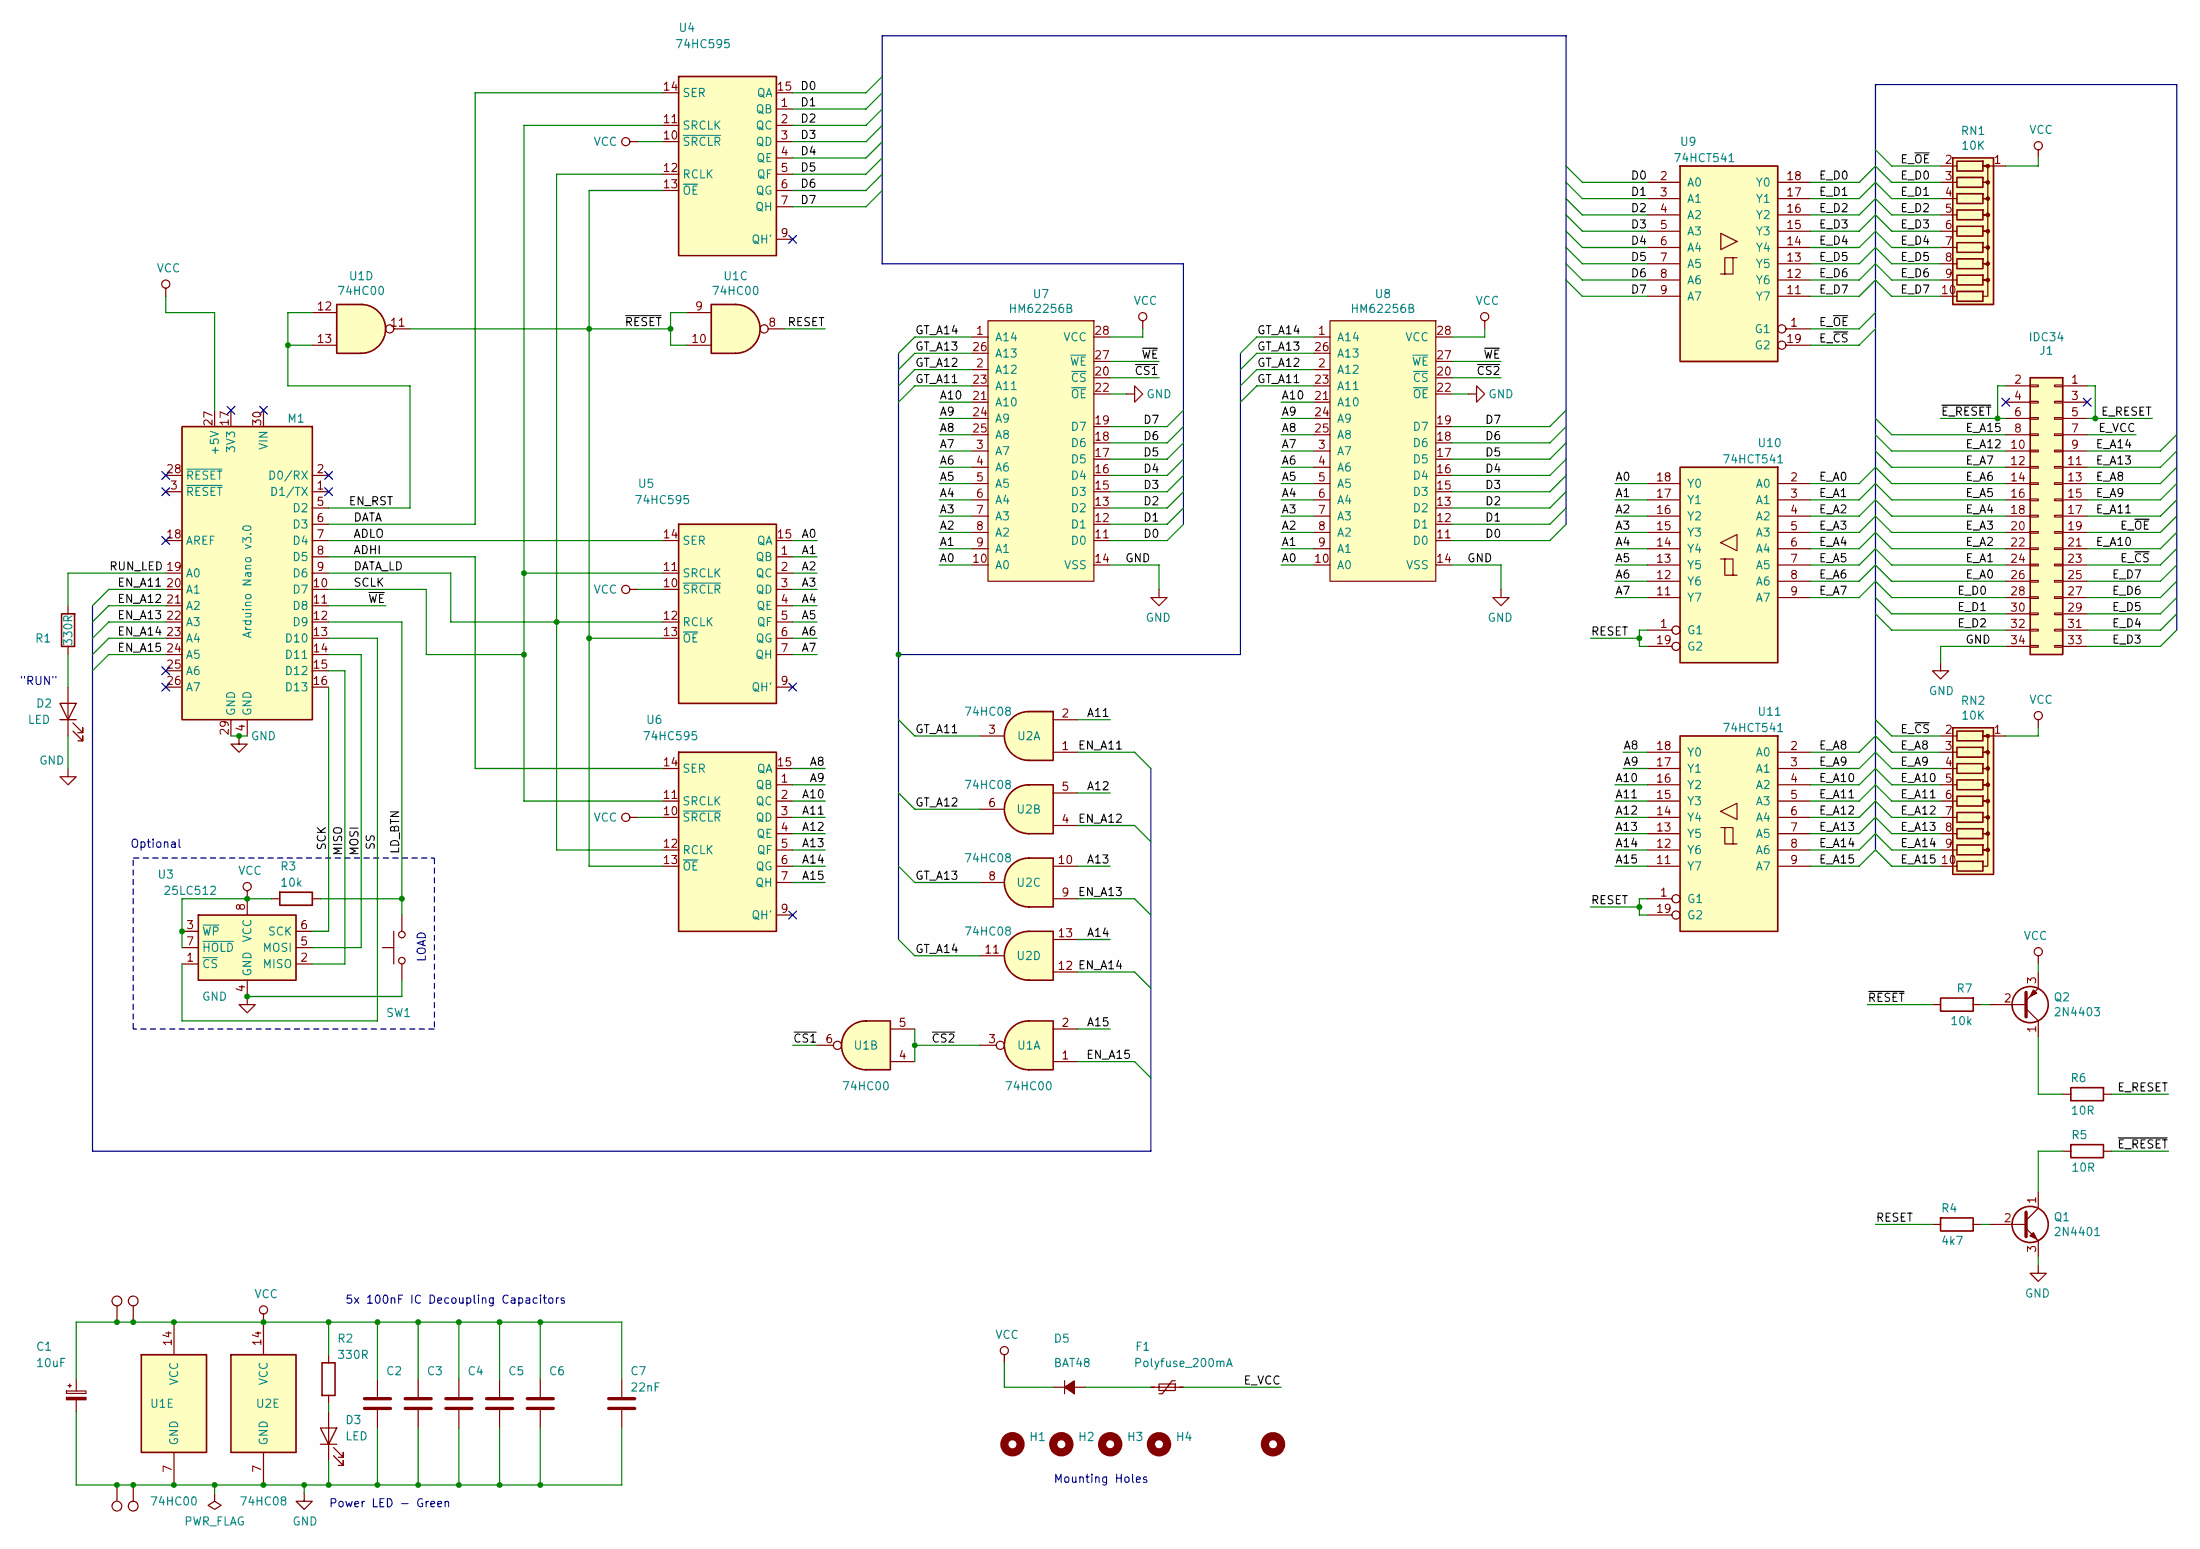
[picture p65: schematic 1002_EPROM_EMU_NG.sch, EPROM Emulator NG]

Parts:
C1: 10uF; CP_Radial_D6.3mm_P2.50mm
C2, C3, C4, C5, C6: 100nF; C_Disc_D4.7mm_W2.5mm_P5.00mm
C7: 22nF; C_Disc_D4.7mm_W2.5mm_P5.00mm
D2, D3: LED; LED_D3.0mm
D5: BAT48; D_DO-35_SOD27_P7.62mm_Horizontal
F1: Polyfuse_200mA; C_Disc_D10.0mm_W2.5mm_P5.00mm
H1, H2, H3, H4: MountingHole; MountingHole_2.2mm_M2
H5: MountingHole; OSHW-Logo2_9.8x8mm_SilkScreen
J1: IDC34; IDC-Header_2x17_P2.54mm_Horizontal_Lock
M1: Arduino Nano v3.0; Arduino_Nano
Q1: 2N4401; TO-92_Inline_Wide
Q2: 2N4403; TO-92_Inline_Wide
R1, R2: 330R; R_Axial_DIN0204_L3.6mm_D1.6mm_P7.62mm_Horizontal
R3, R7: 10k; R_Axial_DIN0204_L3.6mm_D1.6mm_P7.62mm_Horizontal
R4: 4k7; R_Axial_DIN0204_L3.6mm_D1.6mm_P7.62mm_Horizontal
R5, R6: 10R; R_Axial_DIN0204_L3.6mm_D1.6mm_P7.62mm_Horizontal
RN1, RN2: 10K; R_Array_SIP10
SW1: SW_Push; SW_PUSH_6mm
TP1, TP4: VCC; TestPoint_THTPad_D1.5mm_Drill0.7mm
TP2, TP3: GND; TestPoint_THTPad_D1.5mm_Drill0.7mm
U1: 74HC00; DIP-14_W7.62mm_Socket
U2: 74HC08; DIP-14_W7.62mm_Socket
U3: 25LC512; DIP-8_W7.62mm_Socket
U4, U5, U6: 74HC595; DIP-16_W7.62mm_Socket
U7, U8: HM62256B; DIP-28_W15.24mm_Socket
U9, U10, U11: 74HCT541; DIP-20_W7.62mm_Socket

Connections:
/A0: U5.15 (QA), U7.10 (A0), U8.10 (A0), U10.18 (Y0)
/A1: U5.1 (QB), U7.9 (A1), U8.9 (A1), U10.17 (Y1)
/A2: U5.2 (QC), U7.8 (A2), U8.8 (A2), U10.16 (Y2)
/A3: U5.3 (QD), U7.7 (A3), U8.7 (A3), U10.15 (Y3)
/A4: U5.4 (QE), U7.6 (A4), U8.6 (A4), U10.14 (Y4)
/A5: U5.5 (QF), U7.5 (A5), U8.5 (A5), U10.13 (Y5)
/A6: U5.6 (QG), U7.4 (A6), U8.4 (A6), U10.12 (Y6)
/A7: U5.7 (QH), U7.3 (A7), U8.3 (A7), U10.11 (Y7)
/A8: U6.15 (QA), U7.25 (A8), U8.25 (A8), U11.18 (Y0)
/A9: U6.1 (QB), U7.24 (A9), U8.24 (A9), U11.17 (Y1)
/A10: U6.2 (QC), U7.21 (A10), U8.21 (A10), U11.16 (Y2)
/A11: U2.2, U6.3 (QD), U11.15 (Y3)
/A12: U2.5, U6.4 (QE), U11.14 (Y4)
/A13: U2.10, U6.5 (QF), U11.13 (Y5)
/A14: U2.13, U6.6 (QG), U11.12 (Y6)
/A15: U1.2, U6.7 (QH), U11.11 (Y7)
/ADHI: M1.8 (D5), U6.14 (SER)
/ADLO: M1.7 (D4), U5.14 (SER)
/D0: U4.15 (QA), U7.11 (D0), U8.11 (D0), U9.2 (A0)
/D1: U4.1 (QB), U7.12 (D1), U8.12 (D1), U9.3 (A1)
/D2: U4.2 (QC), U7.13 (D2), U8.13 (D2), U9.4 (A2)
/D3: U4.3 (QD), U7.15 (D3), U8.15 (D3), U9.5 (A3)
/D4: U4.4 (QE), U7.16 (D4), U8.16 (D4), U9.6 (A4)
/D5: U4.5 (QF), U7.17 (D5), U8.17 (D5), U9.7 (A5)
/D6: U4.6 (QG), U7.18 (D6), U8.18 (D6), U9.8 (A6)
/D7: U4.7 (QH), U7.19 (D7), U8.19 (D7), U9.9 (A7)
/DATA: M1.6 (D3), U4.14 (SER)
/DATA_LD: M1.9 (D6), U4.12 (RCLK), U5.12 (RCLK), U6.12 (RCLK)
/EN_A11: M1.20 (A1), U2.1
/EN_A12: M1.21 (A2), U2.4
/EN_A13: M1.22 (A3), U2.9
/EN_A14: M1.23 (A4), U2.12
/EN_A15: M1.24 (A5), U1.1
/EN_RST: M1.5 (D2), U1.12, U1.13
/E_A0: J1.26, U10.2 (A0)
/E_A1: J1.24, U10.3 (A1)
/E_A2: J1.22, U10.4 (A2)
/E_A3: J1.20, U10.5 (A3)
/E_A4: J1.18, U10.6 (A4)
/E_A5: J1.16, U10.7 (A5)
/E_A6: J1.14, U10.8 (A6)
/E_A7: J1.12, U10.9 (A7)
/E_A8: J1.13, RN2.3 (R2), U11.2 (A0)
/E_A9: J1.15, RN2.4 (R3), U11.3 (A1)
/E_A10: J1.21, RN2.5 (R4), U11.4 (A2)
/E_A11: J1.17, RN2.6 (R5), U11.5 (A3)
/E_A12: J1.10, RN2.7 (R6), U11.6 (A4)
/E_A13: J1.11, RN2.8 (R7), U11.7 (A5)
/E_A14: J1.9, RN2.9 (R8), U11.8 (A6)
/E_A15: J1.8, RN2.10 (R9), U11.9 (A7)
/E_D0: J1.28, RN1.3 (R2), U9.18 (Y0)
/E_D1: J1.30, RN1.4 (R3), U9.17 (Y1)
/E_D2: J1.32, RN1.5 (R4), U9.16 (Y2)
/E_D3: J1.33, RN1.6 (R5), U9.15 (Y3)
/E_D4: J1.31, RN1.7 (R6), U9.14 (Y4)
/E_D5: J1.29, RN1.8 (R7), U9.13 (Y5)
/E_D6: J1.27, RN1.9 (R8), U9.12 (Y6)
/E_D7: J1.25, RN1.10 (R9), U9.11 (Y7)
/E_RESET: J1.1, J1.5, R6.2
/E_VCC: F1.1, J1.7
/E_~CS~: J1.23, RN2.2 (R1), U9.19 (G2)
/E_~OE~: J1.19, RN1.2 (R1), U9.1 (G1)
/GT_A11: U2.3, U7.23 (A11), U8.23 (A11)
/GT_A12: U2.6, U7.2 (A12), U8.2 (A12)
/GT_A13: U2.8, U7.26 (A13), U8.26 (A13)
/GT_A14: U2.11, U7.1 (A14), U8.1 (A14)
/LD_BTN: M1.12 (D9), R3.1, SW1.2
/MISO: M1.15 (D12), U3.2 (MISO)
/MOSI: M1.14 (D11), U3.5 (MOSI)
/RESET: R4.2, U1.8, U10.1 (G1), U10.19 (G2), U11.1 (G1), U11.19 (G2)
/RUN_LED: M1.19 (A0), R1.2
/SCK: M1.16 (D13), U3.6 (SCK)
/SCLK: M1.10 (D7), U4.11 (SRCLK), U5.11 (SRCLK), U6.11 (SRCLK)
/SS: M1.13 (D10), U3.1 (~CS)
/~CS1~: U1.6, U7.20 (~CS)
/~CS2~: U1.3, U1.4, U1.5, U8.20 (~CS)
/~E_RESET~: J1.2, J1.6, R5.1
/~RESET~: R7.1, U1.9, U1.10, U1.11, U4.13 (~OE), U5.13 (~OE), U6.13 (~OE)
/~WE~: M1.11 (D8), U7.27 (~WE), U8.27 (~WE)
GND: C1.2, C2.2, C3.2, C4.2, C5.2, C6.2, C7.2, D2.1 (K), D3.1 (K), J1.34, M1.4 (GND), M1.29 (GND), Q1.3 (E), SW1.1, TP2.1, TP3.1, U1.7 (GND), U2.7 (GND), U3.4 (GND), U4.8 (GND), U5.8 (GND), U6.8 (GND), U7.14 (VSS), U7.22 (~OE), U8.14 (VSS), U8.22 (~OE), U9.10 (GND), U10.10 (GND), U11.10 (GND)
unnamed: D2.2 (A), R1.1
unnamed: D3.2 (A), R2.2
unnamed: D5.2 (A), F1.2
unnamed: Q1.1 (C), R5.2
unnamed: Q1.2 (B), R4.1
unnamed: Q2.1 (C), R6.1
unnamed: Q2.2 (B), R7.2
VCC: C1.1, C2.1, C3.1, C4.1, C5.1, C6.1, C7.1, D5.1 (K), M1.27 (+5V), Q2.3 (E), R2.1, R3.2, RN1.1 (common), RN2.1 (common), TP1.1, TP4.1, U1.14 (VCC), U2.14 (VCC), U3.3 (~WP), U3.7 (~HOLD), U3.8 (VCC), U4.10 (~SRCLR), U4.16 (VCC), U5.10 (~SRCLR), U5.16 (VCC), U6.10 (~SRCLR), U6.16 (VCC), U7.28 (VCC), U8.28 (VCC), U9.20 (VCC), U10.20 (VCC), U11.20 (VCC)

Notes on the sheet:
5x 100nF IC Decoupling Capacitors
Power LED - Green
"RUN"
LOAD
Optional
Mounting Holes

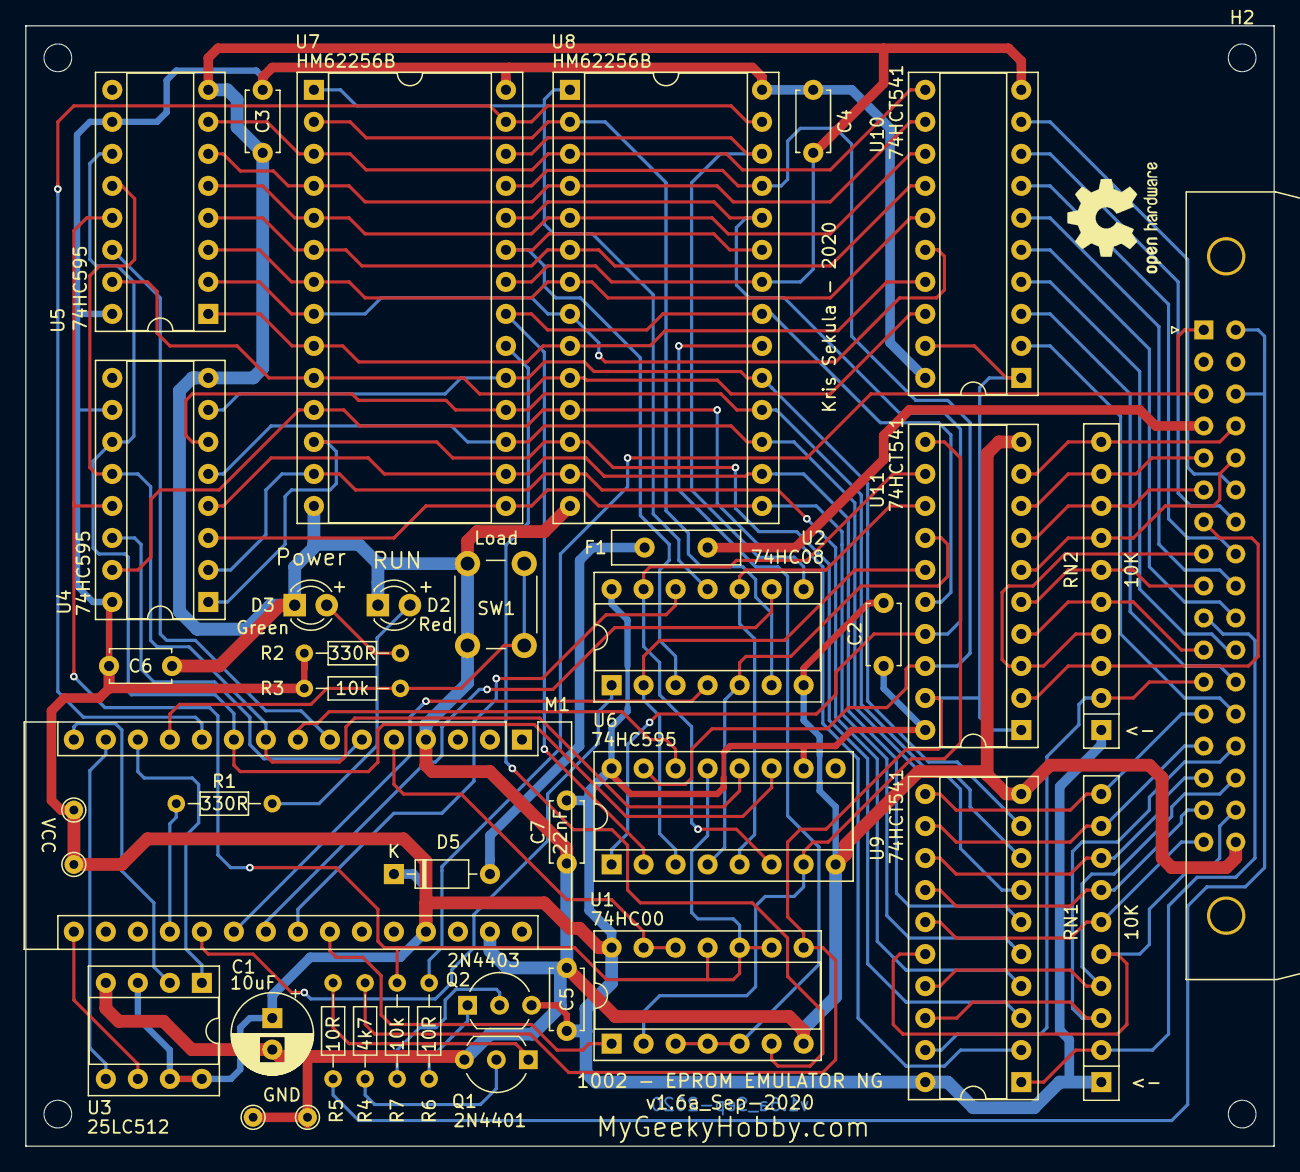
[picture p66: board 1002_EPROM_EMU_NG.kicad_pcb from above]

Board: 2 copper layers, 99.1 x 88.9 mm, 45 parts (0 on the bottom side), 88 nets.

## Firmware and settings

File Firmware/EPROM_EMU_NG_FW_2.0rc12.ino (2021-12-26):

// 
// This sketch controls the EPROM memory Emulator hardware described on mygeekyhobby.com, code is maintained by Kris Sekula with support from community 
// Parts of this code have been kindly contributed by Ralf-Peter Nerlich
//    
// 1.8rc1 Oct-2020
//  - optimized for speed (now loading from SPI via a button or "auto" takes only 3.5s for 27512)
//  - HW version now in EEPROM of the Arduino, so doesn't change every time you upload a new sketch version (update the default HW version below before you run the first time)
//  - only update "last EPROM" if Save to SPI was on... this way when you reload from SPI EEPROM you will also get the last used EPROM type configured on the bus (this was a bug before)
//  - includes the fix as per ERRATA for PCB ver 1.6 and below
//
// 2.0rc1 Oct-2020
//  - support for binary transfer
//  - support for SPI EEPROM addressed transfers
// 2.0rc2 Dec-2020 
//		- eliminate pull up on button by using the CPU built in pull up resistors
//		- change the "long-press" LOAD button function from "disable auto-load" to more useful "reset target" function
// 2.0rc6 Mar-2021
//    - speed increase by optimising pin/port control with low level code instead of "digitalwrite"
//    - SPI speed increas to 8MHz
//	  - Added support for 28C256
// 2.0rc7 Mar-2021
//    - Added support for 28C64 (it's just a label as 2764 = 28C64 pinout)
// 2.0rc8 Mar-2021
//    - Added direct to SRAM upload (this is only used when "save to SPI EEPROM" is not enabled, and improves speed by shifting data from serial directly to SRAM without extra buffor)
// 2.0rc9 Mar-2021
//	  - prevously filename rc8 had rc7 config inside, now changed to rc9 to match the SW rc9
// 2.0rc10 Aug-2021
//    - added a fix for black nano with vqfn atmega328p
// 2.0rc11 Nov-2021, a number of fixes and improvements kindly contributed by by Ralf-Peter Nerlich <early8bitz.de> 2021-11-14
//    - fixed EPROM type 8 (28C64) handling in setup()
//    - changed numeric EPROM IDs (memory codes) to symbolic names for clarity
//    - corrected help entries for :iniE256 and :iniE64
// 2.0rc12 Dec-2021
//	  - fix for operation without the 100nF reset capacitor (auto-reset on connect disabled in HW)

#include <EEPROM.h>

// pin configurations

#define DATA 3  // data pin for shift register handling D0-D7
#define ADLO 4  // data pin for shift register handling A0-A7
#define ADHI 5  // data pin for shift register handling A8-A15
#define SCLK 7  // clock ping for all shift registers
#define DAT_LD 6  // latch pin for all shift registers  PD6

// Gating signals - ignores selected A11 - A15 address pins besed on EPROM Type
#define EN_A11 A1  // A11 data pin gating signal 
#define EN_A12 A2  // A12 data pin gating signal 
#define EN_A13 A3  // A13 data pin gating signal 
#define EN_A14 A4  // A14 data pin gating signal 
#define EN_A15 A5  // A15 data pin gating signal


#define EN_RST 2  //  internal / external bus control pin
#define WE 8      // SRAM Write Enable Pin

#define LD_BTN 9  // load data from SPI button
#define LED_G A0  // RED LED


// low level ping / port control
#define ADHI_LO PORTD &= ~(1<<PD5) // set LOW
#define ADHI_HI PORTD |=  (1<<PD5) // set High

#define ADLO_LO PORTD &= ~(1<<PD4) // set LOW
#define ADLO_HI PORTD |=  (1<<PD4) // set High

#define DATA_LO PORTD &= ~(1<<PD3) // set LOW
#define DATA_HI PORTD |=  (1<<PD3) // set High

#define SCLK_LO PORTD &= ~(1<<PD7) // set LOW
#define SCLK_HI PORTD |=  (1<<PD7) // set High

#define DAT_LD_LO PORTD &= ~(1<<PD6) // set LOW
#define DAT_LD_HI PORTD |=  (1<<PD6) // set High

#define WE_LO PORTB &= ~(1<<PB0) // set LOW
#define WE_HI PORTB |=  (1<<PB0) // set High

#define SS_LO PORTB &= ~(1<<PB2) // set LOW
#define SS_HI PORTB |=  (1<<PB2) // set High

#define LED_OFF PORTC &= ~(1<<PC0) // LED OFF
#define LED_ON PORTC |=  (1<<PC0) // LED ON
#define LED_FLIP PINC = bit(PC0) // toggle LED

// SPI EEPROM stuff

#define DATAOUT 11  //MOSI
#define DATAIN  12  //MISO
#define SPICLOCK  13  //sck
#define SLAVESELECT 10  //ss

// SPI opcodes - taken from Arduino SPI examples
#define WREN  6
#define WRDI  4
#define RDSR  5
#define WRSR  1
#define READ  3
#define WRITE 2
#define CE 199 

// utility byte
byte clr;

// spi_address tracking
unsigned int spi_address = 0; // SPI_EEPROM address
unsigned int page_ctn = 0;

// binary transfer buffer
byte byteBuffer [513];

// configuration addresses in internal EEPROM
int mem_cfg = 0;  // EEPROM address where we store last used EPROM information (value 1 = 2716, 2 = 2732, 3 = 2764, 4 = 27128, 5 = 27256, 6 = 27512, 7 = 28256)
int save_cfg = 1; // EEPROM address where we store settings for "SAVE to SPI EEPROM option" (value 1 = yes, 2 = no)
int auto_cfg = 2; // EEPROM address where we store settings for "Auto load from SPI EEPROM" option (value 1 = yes, 2 = no)
int ver_cfg = 10;  // EEPROM start addres where we store hardware version (up to 10 characters)

// global config settings
bool saveSPI;
bool autoLoad;
unsigned int lastEPROM;
                       
const char FW_ver[] = "2.0rc12";
char HW_ver[10];

// ID numbers for ROM types
enum {noROM, rom16K, rom32K, rom64K, rom128K, rom256K, rom512K, romE256K, romE64K, lastType};

// Name strings for  ROM types (same order as in enumeration)
const char* memTable[lastType] = {"27xx","2716","2732","2764","27128","27256","27512","28C256","28C64"}; // lookup table for memory type

void setup() {
  //Serial.begin(1000000);
  Serial.begin(115200);
  
  pinMode( WE, OUTPUT ); digitalWrite( WE, LOW );
  pinMode( EN_RST, OUTPUT ); digitalWrite( EN_RST, HIGH );  // disable emulaton, wait for computer control or autload

  pinMode( DATA, OUTPUT ); digitalWrite( DATA, LOW );
  pinMode( ADLO, OUTPUT ); digitalWrite( ADLO, LOW );
  pinMode( ADHI, OUTPUT ); digitalWrite( ADHI, LOW );

  pinMode( DAT_LD, OUTPUT ); digitalWrite( DAT_LD, LOW );
  pinMode( SCLK, OUTPUT ); digitalWrite( SCLK, LOW );


  pinMode( LED_G, OUTPUT ); digitalWrite( LED_G, LOW );

  // address lines gate signals as outputs
  pinMode( EN_A11, OUTPUT );
  pinMode( EN_A12, OUTPUT );
  pinMode( EN_A13, OUTPUT ); 
  pinMode( EN_A14, OUTPUT );
  pinMode( EN_A15, OUTPUT );

  //
  pinMode(LD_BTN,INPUT_PULLUP); 
  
  setBus(rom512K); //  default settings to enable all address lines

  // SPI EEPROM pins
  pinMode(DATAOUT, OUTPUT);
  pinMode(DATAIN, INPUT);
  pinMode(SPICLOCK,OUTPUT);
  pinMode(SLAVESELECT,OUTPUT); digitalWrite(SLAVESELECT,HIGH); //disable device

  // SPCR = 01010000
  //interrupt disabled,spi enabled,msb 1st,master,clk low when idle,
  //sample on leading edge of clk,system clock/2 rate (8MHz SPI clock)
  SPCR = (1<<SPE)|(1<<MSTR);
  SPSR = (1 << SPI2X);
  clr=SPSR;
  clr=SPDR;

  // load configuration, set defaults if needed
  
  //
  // get "last used EPROM" config from SPI_EEPROM
  //
  if ((EEPROM.read(mem_cfg) >= lastType) || (EEPROM.read(mem_cfg) < rom16K)) {
    EEPROM.update(mem_cfg, rom512K);
    Serial.println(F("Setting default EPROM Memory to 27512"));
  }
  else {
    lastEPROM = EEPROM.read(mem_cfg) ;
    Serial.println(String("Config: Last EPROM used is ") + memTable[lastEPROM]);
  }
  //
  // get "save to SPI_EEPROM" config from EEPROM
  //
  switch (EEPROM.read(save_cfg)) {
    case 0:
      saveSPI = false;
      Serial.println(F("Option: Save to SPI EEPROM set to disable"));
      break;
    case 1:
      saveSPI = true;
      Serial.println(F("Option: Save to SPI EEPROM set to enable"));
      break;
    default:
      EEPROM.write(save_cfg,0);
      Serial.println(F("Default: disabling save to spi"));
      break;
  }
  //
  // get "auto load from SPI_EEPROM" config from EEPROM
  //
  switch (EEPROM.read(auto_cfg)) {
    case 0:
      autoLoad = false;
      Serial.println(F("Option: Auto load from SPI EEPROM set to disable"));
      break;
    case 1:
      autoLoad = true;
      Serial.println(F("Option: Auto load from SPI EEPROM set to enable"));
      break;
    default:
      EEPROM.write(auto_cfg,0);
      Serial.println(F("Default: Disabling Auto load from SPI EEPROM "));
      break;
  }
  
  // fix for black nano with atmega328p vqfn package
  writeMemoryLocation(0x0001,0x00);
  writeMemoryLocation(0x0001,0x00);
  //
  
  // load data from SPI EEPROM if configured

  if (autoLoad == true ) {
    load_SPIEEPROM(lastEPROM);
  }

  //
  // get hardware version from EEPROM
  //
  EEPROM.get(ver_cfg, HW_ver); // load version from EEPROM
  
  if(HW_ver[0] != 'v') {
    // set default version
    Serial.println(F("setting default internal hw version"));
    //
    EEPROM.put(ver_cfg, "v2.1"); //Set this to whatever you have on the PCB, if you did the HW mod as per Errata, call it v1.6f or similar   <--------- README                                  
    EEPROM.get(ver_cfg, HW_ver);
  }
  //
  // if you missed setting up the hw version before, you can temporary replace the "if((HW_ver[0] != 'v')" with "if(1)"
  //

  Serial.println("");
  Serial.println(F("Emulator Started, waiting for computer contol"));
  printabout();
}

//
// restore SRAM from SPI EEPROM
//

void load_SPIEEPROM (int eprom) {
  
  setBus(rom512K); // allows access to enire 64KiB SRAM Memory - equivlet of emulating 27512 eprom
  digitalWrite( WE, LOW);       // brings data bus of SRAM to high-z
  digitalWrite( EN_RST, HIGH ); // reset target, disable 541 buffers, enable shift registers
  digitalWrite( LED_G, LOW );
  
  unsigned int max_size;
  switch (eprom) {
    case rom16K:
      Serial.println(F( "-> Loading 2716 EPROM from SPI"));
      max_size = 16; // pages of 128 bytes
      break;
    case rom32K:
      Serial.println(F( "->  Loading 2732 EPROM from SPI"));   
      max_size = 32; // pages of 128 bytes
      break;
    case rom64K:
      Serial.println(F( "->  Loading 2764 EPROM from SPI"));
      max_size = 64; // pages of 128 bytes
      break;
    case rom128K:
      Serial.println(F( "->  Loading 27128 EPROM from SPI"));
      max_size = 128; // pages of 128 bytes
      break;
    case rom256K:
      Serial.println(F( "-> Loading 27256 EPROM from SPI"));
      max_size = 256; // pages of 128 bytes
      break;
    case rom512K:
      Serial.println(F( "-> Loading 27512 EPROM from SPI"));
      max_size = 512; // pages of 128 bytes
      break;
    case romE256K:
      Serial.println(F( "-> Loading 28C256 EEPROM from SPI"));
      max_size = 512; // pages of 128 bytes
      break;
     case romE64K:
      Serial.println(F( "->  Loading 28C64 EEPROM from SPI"));
      max_size = 64; // pages of 128 bytes
      break;
    default:
      Serial.println(F( "-> Default: Loading 27512 EPROM from SPI"));
      max_size = 512; // pages of 128 bytes
      break;
  }

  // now load this many pages from SPI EEPROM
  
  byte SPIdata;
  int clmn = 0;
  
  for (unsigned int page = 0; page < max_size; page++) {

    // visual feedback to user that trasfer from SPI EEPROM to SRAM is happening
    if (spi_address & 0010000) {
      LED_FLIP;
    }

    SS_LO; // select SPI EEPROM
    
    spi_transfer(READ);                     //transmit read opcode
    spi_transfer((byte)(spi_address>>8));   //send MSByte address first
    spi_transfer((byte)(spi_address));      //send LSByte address
    
    for (int i=0; i<128; i++) {
      SPIdata = spi_transfer(0xFF); //get data byte by trasfering dummy 0xff data to spi eeprom
      writeMemoryLocation(spi_address, SPIdata);
      spi_address++;
    }
    //digitalWrite(SLAVESELECT,HIGH); //release chip, signal end transfer
    SS_HI;  // release SPI EEPROM
    
    // this section is so that the python script trying to connect to the Arduino knows SPI loading is happening and can wait for it to finish.
    Serial.print(".");
    clmn ++;
    if (clmn > 63) {
      Serial.println("");
      clmn = 0;
    }
  }
 
  setBus(eprom); // now that SRAM is loaded with data, we can enable correct address lines

  digitalWrite( EN_RST, LOW );  // disable shift registers, address enable buffers.
  digitalWrite( WE, HIGH);      // enable SRAM outputs
  digitalWrite( LED_G, HIGH );  // turn on "RUN" LED
  
  Serial.println(F("Done loading from SPI EEPROM to SRAM"));  
}

//
// procedure to setup erase SPI EEPROM
//

void clearSPIEEPROM (){
   // send write enable command to unlock writting to EEPROM

      //digitalWrite(SLAVESELECT,LOW);
      SS_LO;
      spi_transfer(WREN);
      //digitalWrite(SLAVESELECT,HIGH);
      SS_HI;

      // chip erase command
      //digitalWrite(SLAVESELECT,LOW);
      SS_LO;
      spi_transfer(CE);            //chip erase instruction
      //digitalWrite(SLAVESELECT,HIGH);
      SS_HI;
      delay(10);
}

//
// procedure to setup address for spi transaction
//

void setAddressSPI (unsigned short address){
   // send write enable command to unlock writting to EEPROM

      //digitalWrite(SLAVESELECT,LOW);
      SS_LO;
      spi_transfer(WREN);
      //digitalWrite(SLAVESELECT,HIGH);
      SS_HI;

      // write command
      //digitalWrite(SLAVESELECT,LOW);
      SS_LO;
      spi_transfer(WRITE);            //write instruction
      
      // set start address
      spi_transfer((char)(address>>8));
      spi_transfer((char)(address));
}

//
// new as of 2.0
//
// data should be in the byteBuffer, either 128, 256, 384 or 512 bytes
// 
void writeBufferSPI(unsigned short address, unsigned int bytecount) {
  // process data from byteBuffer
 
  setAddressSPI(address); // set initial spi address
  
  int m=0; // page counter for SPI EEPROM
  for (int k=0; k<bytecount; k++) {
    // every 128 bytes issue a save command and set address
    if(m == 128 ) {
      // every 128 bytes write data and set new address
      SS_HI;
      // wait for write to finish, for 25LC512 Twc = 5ms, here 5.05ms 
      delay(5);
      delayMicroseconds(50); 
      setAddressSPI(address); // set address
      m=0;
    }
    spi_transfer(byteBuffer[k+1]);
    address++;
    m++;
  }
  SS_HI;
}

// SPI EEPROM transfer routine

char spi_transfer(volatile char data)
{
  SPDR = data;                    // Start the transmission
  while (!(SPSR & (1<<SPIF)))     // Wait for the end of the transmission
  {
  };
  return SPDR;                    // return the received byte
}

//
// print "about" message 
//
void printabout() {    
          Serial.print(F("-> HW: ")); Serial.print(HW_ver);
          Serial.print(F(", FW: ")); Serial.print(FW_ver);
          Serial.print(F(", SPI: ")); Serial.print(saveSPI);
          Serial.print(F(", Auto: ")); Serial.print(autoLoad);
          Serial.print(F(", Last EPROM: ")); Serial.print(memTable[lastEPROM]);        
          Serial.println(F(", mygeekyhobby.com 2020 :)"));
}

//  Adjusts address lanes A11 - A15, based on imput EPROM type is 2716 = 1 ... 27512 = 6
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
void loop() {
  
if (digitalRead(LD_BTN) == LOW) {           // Yeah, the button is pressed
    delay(500);                             // Wait 0.5s and look again
    if (digitalRead(LD_BTN) == HIGH) {      // Button released after 500ms = short press
       // short press will load from SPI_EEPROM
      Serial.println(F("Load from SPI EEPROM triggered by pushbutton"));
      lastEPROM = EEPROM.read(mem_cfg);
      load_SPIEEPROM(lastEPROM);
    } else {                             // Button not released after 500ms
      delay(1000);                       // Wait 1s more
      if (digitalRead(LD_BTN) == LOW) {  // Button not released after (500+1000)ms = long press
        // long press resets target
        digitalWrite( EN_RST, HIGH);
        delay(150);
        digitalWrite( EN_RST, LOW );
        Serial.println(F("-> Resetting target via button"));
        digitalWrite( LED_G, LOW );   // turn the LED off to indicate the RESET was succesful
        while (digitalRead(LD_BTN) == LOW) {
          delay(100);                    // wait for releasing button
        }
        digitalWrite( LED_G, HIGH );    //
      }
    }
    delay(3000);                         // next possible push in 3s

  } // end processing push button
  
  if (Serial.available() > 0) {
    char ch = Serial.read();            
    if ( ch == 0x0D /*CR*/) {
      return;
    }
    // detect end of frame
    if ( ch == 0x0A /*LF*/) {
      // decode frame
      
      if (rxFrame.length() == 0){
        Serial.println(F(">"));
        rxFrame = "";
        return;     
      }
      
      //
      if ( rxFrame == ":>" ) {
        Serial.println(F("<"));
        rxFrame = "";
        return;     
      }
      //

      //
      // get sync
      //      
      if ( rxFrame == ":EMUOFF" ) {
        digitalWrite( WE, LOW);       // brings data bus of SRAM to high-z
        digitalWrite( EN_RST, HIGH ); // reset target, disable 541 buffers, enable shift registers
        digitalWrite( LED_G, LOW );  // RUN LED off
        printabout();
        rxFrame = "";
		setBus(rom512K); // new in rc12
        return;     
      }
      //
      // start emulation
      //
      if ( rxFrame == ":EMUON" ) {
          digitalWrite( EN_RST, LOW );  // disable shift registers, address enable buffers.
          digitalWrite( WE, HIGH);      // enable SRAM outputs
          digitalWrite( LED_G, HIGH );  // turn on "RUN" LED
          
          Serial.println(F("-> Emulator Running."));
          spi_address = 0;              // may have to remove that later   
          rxFrame = "";
          return;                  
      }
      
      if ( rxFrame == ":ini16" ) {
        setBus(rom16K);
        if (saveSPI) {EEPROM.update(mem_cfg, rom16K);}
        rxFrame = "";
        return;     
      }
      if ( rxFrame == ":ini32" ) {
        setBus(rom32K);
        if (saveSPI) {EEPROM.update(mem_cfg, rom32K);}
        rxFrame = "";
        return;     
      }
      if ( rxFrame == ":ini64" ) {
        setBus(rom64K);
        if (saveSPI) {EEPROM.update(mem_cfg, rom64K);}
        rxFrame = "";
        return;     
      }
      if ( rxFrame == ":ini128" ) {
        setBus(rom128K);
        if (saveSPI) {EEPROM.update(mem_cfg, rom128K);}
        rxFrame = "";
        return;     
      }
      if ( rxFrame == ":ini256" ) {
        setBus(rom256K);
        if (saveSPI) {EEPROM.update(mem_cfg, rom256K);}
        rxFrame = "";
        return;     
      }
      if ( rxFrame == ":ini512" ) {
        setBus(rom512K);
        if (saveSPI) {EEPROM.update(mem_cfg, rom512K);}
        rxFrame = "";
        return;  
      }
      // Set memory to 28C256 EEPROM
      if ( rxFrame == ":iniE256" ) {
        setBus(romE256K);
        if (saveSPI) {EEPROM.update(mem_cfg, romE256K);}
        rxFrame = "";
        return;     
      }
      // Set memory to 28C64 EEPROM
      if ( rxFrame == ":iniE64" ) {
        setBus(romE64K);
        if (saveSPI) {EEPROM.update(mem_cfg, romE64K);}
        rxFrame = "";
        return;     
      }
      // data will be also written to SPI
      if ( rxFrame == ":iniSPI1" ) {
        saveSPI = true;
        EEPROM.update(save_cfg,1);
        Serial.println(F("-> SPI save ON"));
        spi_address = 0;     
        rxFrame = "";
        return;     
      }
      // data will be also written to SPI
      if ( rxFrame == ":iniSPI0" ) {
        saveSPI = false;
        EEPROM.update(save_cfg,0);
        Serial.println(F("-> SPI save OFF"));  
        rxFrame = "";
        return;        
      }
      //
      // process binary frame, new as of 2.0, process binary frame format <start address><bytecount><payload up to size of buffer> in chunks of 128Bytes
      //
      if ( rxFrame == ":SBN" ) {
        Serial.println(F("->in"));
        unsigned int startaddr = Serial.parseInt();
        unsigned int bytecount = Serial.parseInt();
        
        // now we know start address and how many bytes are coming
        int transfered = Serial.readBytes(byteBuffer,bytecount+1);   // may need bytecount + 1
        // now write the buffer to SRAM
        writeBuffer(startaddr, bytecount);
        if (saveSPI) {writeBufferSPI(startaddr, bytecount);}
        Serial.println(F("ACK"));
        rxFrame = "";
        return;     
      }
      //
      // write directly to SRAM, new as of 2.0rc8
      // 
      if ( rxFrame == ":DIR" ) {
        Serial.println(F(">"));
        unsigned int startaddr = Serial.parseInt();
        unsigned int bytecount = Serial.parseInt();

        // now we know start address and how many bytes are coming
        byte in_data;
        in_data = Serial.read(); // this is to ignore an extra /n in serial buffer
        
        while (bytecount>0){
        // process data from byteBuffer
          if (Serial.available() > 0){
            in_data = Serial.read();
            writeMemoryLocation(startaddr,in_data);
            startaddr++;
            bytecount--;
          }
        }
        Serial.println(F(">"));
        rxFrame = "";
        return;     
      }
      
       // load the SPI EEPROM data to SRAM on boot.
      if ( rxFrame == ":iniAuto1" ) {
        autoLoad = true;
        EEPROM.update(auto_cfg,1);
        Serial.println(F("-> Auto Load ON"));   
        rxFrame = "";
        return;       
      }
      // data will be also written to SPI
      if ( rxFrame == ":iniAuto0" ) {
        autoLoad = false;
        EEPROM.update(auto_cfg,0);
        Serial.println(F("-> Auto Load OFF"));
        rxFrame = "";
        return;     
      }
      // Erase SPI EEPROM ( you can call it from Arduiono serial monitor by typing :SPICLR)
      if ( rxFrame == ":SPICLR" ) {
        clearSPIEEPROM();
        Serial.println(F("->ERASED SPI EEPROM"));
        rxFrame = "";
        return;  
      }
      if ( rxFrame == ":help" or rxFrame =="?" or rxFrame == "help") {
        printhelp();
        rxFrame = "";
        return;
      }

      rxFrame = "";          
    }
    else {
      rxFrame += ch;      
    }
  }
}

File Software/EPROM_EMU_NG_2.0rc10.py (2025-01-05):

#!/usr/bin/env python3
# kris@mygeekyhobby.com
#
# ver 1.0 - may 2020	- initial release
# ver 1.2 - june 2020 	- added save to SPI EEPROM functionality
# 						- fixed the args parsing
#						- added auto load wait option
#						- added save SPI option
# ver 1.3 - july 2020	- removed some of the debug stuff
#						- removed address scrolling when loading
# ver 1.6g - Aug 2020	- Lunches GUI when no parameters specified (code contributed by John Gerrard)... requires PySimpleGUI module "pip install PySimpleGUI"
#						- small fixes to the output
# ver 1.6e              - fixed bug with SPI==y 
#
# ver 2.0rc1 - Oct 2020   	- save parameters in GUI
#							- .bin and .hex file support
#							- binary mode upload with packets of 128-512 bytes at a time
#							- Save to SPI works with any type of data range (any source file less than 128 bytes gets "padded" with 0xFF)
# ver 2.0rc2 - Oct 2020   	- support other extenstions like .rom .img etc... everything not .hex is treated as binary (thanks to Hubert for the feedback and contribution)
#                           - fixed bug where a 128Byte of "00h" was treated as "no data" (thanks to Hubert for the feedback and contribution)
# ver 2.0rc3 - Oct 2020     - code from rc1 that was missing in rc2 was added back, one typo fixed (thx again Hubert)   	
# ver 2.0rc7 - Apr 2021		- added support for 28C64 and 28C256 EEPROM memory (experimental)
# ver 2.0rc8 - Apr 2021	    - added direct to SRAM upload bypassing local buffer					
# ver 2.0rc9 - Apr 2021	    - lowered the size of transfer chunk from 2048 to 1024 for transfers with "spi -n" as 2048 was causing issues on macOS
# ver 2.0rc10- Jan 2024     - allow refreshing serial ports, group gui elements, add input validation, use FreeSimpleGui
#                           - use transfer chunks of 2048 on non-macOS and 1024 on macOS.

version = "2.0rc10"

import argparse
import serial,os
import time
import FreeSimpleGUI as sg
import sys
import platform
from serial.tools.list_ports import comports

# All routines here

# Print int list in Hex format (for debugging only)
def PrintHex(intList):
	row = 0
	for val in intList:
		print("%0.2X"%val, end=' ', flush=True)
		row += 1
		if row == 64:
			print("")
			row=0
# -----------------------------------------------------------------------
def chunkData(bfr):
	"""
	Analyze the 64k buffer, find all 128Byte chunks that are in use (have data != to -1)
	Will return a list of 512 entries with "1" meaning block of 128Bytes had data chaned and "0" no data changed
	"""
	mapped=[]

	for i in range(0,len(bfr),128):
		chunk = bfr[i:i+128]			# split buffer into 128 Bytes chunks
		
		used = False

		for cell in chunk:				# if any byte changed, mark chunk for upload
			if cell >= 0:
				used = True
		
		if used:
			mapped.append(1)
		else:
			mapped.append(0)

	return mapped
# -----------------------------------------------------------------------
def plotData(mapped):
	"""
	Display map of data usage in the buffer, "*" data used and "_" not used
	"""
	col=0
	for idx in range(len(mapped)):
		if idx == 0:		# first address special case
			print("0x%0.4X"%idx, end=' ', flush=True)

		if mapped[idx] == 1:
			print("*", end=' ', flush=True)
		else:
			print("-", end=' ', flush=True)
		col+=1
		if col == 32:
			if (idx*128+128) < 65535:
				print("")
				print("0x%0.4X"%int(idx*128+128),end=' ', flush=True)
				col=0
	return


# -----------------------------------------------------------------------
def packetData(mapped):
	global spi

	data=[]
	"""
	create a list of tuples [(start_address,size),(start_address,size),...,(start_address,size)] ... size can be 128,256,384,512
	in other words find continues ranges of 128Byte data that has changed, group into packets of 128-512 bytes, create a list for later processing
	"""
	if spi == "y":
		buffer_size = 512
	else:
		if platform.system() == "Darwin":
			buffer_size = 1024
		else:
			buffer_size = 2048

	size=0
	start=0
	for idx in range(len(mapped)):
		if mapped[idx] == 1:                  # found used sector
			if size == 0:                     # if chunk empty (new chunk)
				start = idx * 128             # init start address of new chunk
			size += 128                       # one sector more to load
			# test for full chunk or partial filled chunk at end of buffer
			if (size >= buffer_size) or ((size > 0) and (idx >= (len(mapped) - 1))):
				data.append((start, size))    # save chunk
				size = 0                      # reinit size for next chunk
		else:                                 # found unused or cached sector
			if size > 0:                      # sectors in chunk?
				data.append((start, size))    # save chunk, if exists
			size = 0                          # reinit size for next chunk
	return data
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

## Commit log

2020-06-23 3d-Case Folder added
2020-06-23 STL for base added
    [EPROM EMU NG base plate_v2.stl]
2020-07-06 Added a few fixes to create the 1.4 version of PCB
    Pull up on CE on OE added
2020-07-06 Version 1.4 of PCB, with optimised power routing.
    Hopefully this will fix the CMOS latch-up I was getting on U11
    [1002_EPROM_EMU_NG.kicad_pcb]
2020-07-06 Delete 1002_EPROM_EMU_NG_pcb_3D.png
    to be replaced by 1.4 pcb
2020-07-12 Added Digikey based BOM
    Don't buy the Arduino Nano in Digikey, use Amazon or eBay instead as it's much cheaper there. I added it to the DigiKey BOM for completeness.
    [BOM_1_4.csv, BOM_1_4.xlsx]
2020-07-16 Fixed a potential bug when Saving to SPI EEPROM
2020-07-16 Bug fix for SPI EEPROM save
    potentially fixed a bug with SPI EEPROM save
    [EPROM_EMU_NG_FW.ino]
2020-10-06 updated BOM to version 1.6, added SIP socket for RNs and adjusted some parts to better fit the PCB
    [BOM_1_6.csv, BOM_1_6.xlsx]
2020-10-06 clean up old BOM
    [BOM_1_4.csv, BOM_1_4.xlsx]
2020-10-06 Added csv BOM
    [BOM_1_6.csv]
2020-10-07 Updated PCB to version 1.6
    [1002_EPROM_EMU_NG.kicad_pcb, 1002_EPROM_EMU_NG.sch]
2020-10-07 Added picture of v1.5 PCB
2020-10-09 Added Brother laber printer formatted label for the DIP28 emulator probe, also a png version for standard printer.
2020-10-26 Add files via upload
    v1.7 PCB, DON'T USE YET
2020-10-27 Added Errata file for PCB 1.6 and below
    A recommended fix for a design flaw in PCB versions 1.6 and below.
2020-10-27 Use this firmware with PCB ver 1.6 or lower
    See the Errata pdf for details, Option B - beta firmware fix for the emulator if you are unable to perform the HW modification.
    [EPROM_EMU_NG_FW_wFix.ino]
2020-10-28 includes the fix for /OE to SRAM
    waiting for PCBs before I officially release this version
2020-11-09 Added 2.0rc1
    Release Candidate 1 for firmware 2.0
    * Uses binary transfer mode
    * SPI EEPROM save option works across entire 64k address space
2020-11-09 Adde Python script 2.0rc1 and release notes
    This is release candidate 1 for software version 2.0
    * save parameters in GUI
    * .bin and .hex file support
    * binary mode upload with packets of 128-512 bytes at a time
    * Save to SPI works with any type of data range (any source file less than 128 bytes gets "padded" with 0xFF)
2020-11-14 Added DIP24 probe design
2020-11-14 DIP24 Probe pictures
2020-11-19 1.8b
    Added version 1.8b of the PCB. Includes fixes to the SRAM CS line as well as the silkscreen for Q1(2N4401) and Q2(2N4403)
    [1002_EPROM_EMU_NG_1.8.kicad_pcb, 1002_EPROM_EMU_NG_1.8b.sch]
2020-11-19 Fixed Q1 and Q2 footprint
2020-11-19 upadated version number to 1.8b in schematic
    [1002_EPROM_EMU_NG_1.8b.sch]
2020-11-19 Reshuffled files into folders
    [1002_EPROM_EMU_NG.kicad_pcb, 1002_EPROM_EMU_NG.sch, BOM_1_6.csv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]
2020-11-19 Updated KiCad Sources
    [1002_EPROM_EMU_NG.kicad_pcb, 1002_EPROM_EMU_NG.sch, BOM_1_6.xlsx]
2020-11-19 updated Probe Design document
2020-11-23 missed some code in RC2 from RC1 ... fixed now
    [EPROM_NG_v2.0rc3.py]
2020-12-23 Code cleanup, SPI to SRAM load speed improvements
    Major code cleanup, thanks to Hubert H. Long press of the LOAD button does a 150ms target reset (if you connect the reset hook to your target)
    [EPROM_EMU_NG_FW_2.0rc3.ino]
2021-01-17 1.9 KiCad sources uploaded
    [1002_EPROM_EMU_NG_1.9.kicad_pcb, 1002_EPROM_EMU_NG_1.9.sch]
2021-01-17 Uploaded HW v2.1 KiCad sources
    [1002_EPROM_EMU_NG_2.1.kicad_pcb, 1002_EPROM_EMU_NG_2.1.sch]
2021-04-10 Updated files to version 2.2
    Cosmetic changes to schematic and PCB
    [1002_EPROM_EMU_NG_2.2.kicad_pcb, 1002_EPROM_EMU_NG_2.2.sch]
2021-04-12 Python code 2.0rc9 added
    Fixed transfer size to 1024 bytes as 2048 was causing issues on macOS
    [EPROM_EMU_NG_2.0rc9.py]
2021-04-25 Added assembly instructions for HW 2.2
2021-08-22 fix for black nano v3 causing issues
    Black Nano v3 clones with vqfn atmage328p were misbehaving, this small fix seems to make things work again
    [EPROM_EMU_NG_FW_2.0rc3.ino, EPROM_EMU_NG_FWrc10.ino]
2021-10-11 1.9c assembly instructions and Gerbers added
2021-10-11 Schematic diagram for 1.9c added
2021-10-11 2.2c BOM, gerbers and schematic diagram added
    [EpromEmu_2_2c_BoM_DigiKey.xlsx]
2021-10-11 2.2c assembly instruction added
2021-10-11 1.9c added Digikey compatible BoM
    [EpromEmu_1_9c_BoM_DigiKey.xlsx]
2021-11-15 Added few fixes submitted by Ralf
    Fixed bugs related to EEPROM memory type
    [EPROM_EMU_NG_FWrc11.ino]
2021-11-15 Added few fixes submitted by Ralf
    corrected fw ver string
    [EPROM_EMU_NG_FWrc11.ino]
2021-12-13 Added KiCad Sources for 2.2c
2021-12-26 added workarounds for ATMEGA328PB as found in some new Nano clones
    [EPROM_EMU_NG_FW.ino, EPROM_EMU_NG_FW_2.0rc1.ino, EPROM_EMU_NG_FW_2.0rc12.ino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]
2021-12-26 Added Nano_328PB picture with modded Reset circuit
2022-01-18 updated BOMs
    [EpromEmu_1_9c_BoM_DigiKey.xlsx, EpromEmu_2_2c_BoM_DigiKey.xlsx]
2022-07-10 Added support for TLY 3100 DIP 28 probe
    [EpromEmu_1_9d_BoM_DigiKey_v3.xlsx, EpromEmu_2_2d_BoM_DigiKey_v1.xlsx]
2022-07-10 Support for TLY 3100 dip 28 probe added
2023-10-10 Added 2.2d KiCad sources
    [1002_EPROM_EMU_NG_2.2d.kicad_pcb, 1002_EPROM_EMU_NG_2.2d.kicad_sch]
2023-10-10 updated schematic pdf
2023-12-31 updated assembly instructions to ver.2.2c(B)
2024-01-31 updated BOM
    [EpromEmu_2_2d_BoM_DigiKey_v2.xlsx]
2024-01-31 Delete Hardware/2.2d/EpromEmu_2_2d_BoM_DigiKey_v1.xlsx
    updated to v2
    [EpromEmu_2_2d_BoM_DigiKey_v1.xlsx]
2025-01-05 Fix indentation
    Some code was indented with spaces instead of tabs, which is
    overwhelminly used in the rest of the code. Unify.
    [EPROM_EMU_NG_2.0rc10.py]
2025-01-05 Fallback for saved window position
    when using the emulator from different devices with different screen
    resolutions, the saved position might not be valid. If that is the
    case, use a default location.
2025-01-05 Switch communication to be all in binary
    Instead of encoding/decoding all serial communication to the terminal's
    encoding, keep everything in binary for communications and decode only
    when printing to the terminal.
    This solves my issue where the script crashed when running on a raspberry
    pi through ssh from a macOS machine.
    [EPROM_EMU_NG_2.0rc10.py]
2025-01-05 Make output of the script more compact
    Make it easier to parse script output at a glance:
    $ epromemung -mem 27512 -spi y -auto y a4091_cdfs.rom /dev/ttyUSB1
    EPROM EMU NG tool v2.0rc10
    Processing a4091_cdfs.rom... done (bin)
    Using serial port /dev/ttyUSB1, emulating: 27512 EPROM
    <- attempting to get sync
    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
2025-03-31 Add EPROM_NG_v2.0rc4.py - move to using FreeSimpleGUI, only load gui library if needed, show friendly import errors
    [EPROM_EMU_NG_2.0rc8.py, EPROM_EMU_NG_2.0rc9.py, EPROM_NG_V2.0rc3.pyqt5.py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]
